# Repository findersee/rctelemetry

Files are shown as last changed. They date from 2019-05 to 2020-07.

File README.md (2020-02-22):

# rctelemetry
<p>FrSky Smart port compatible Telemetry board.</p>
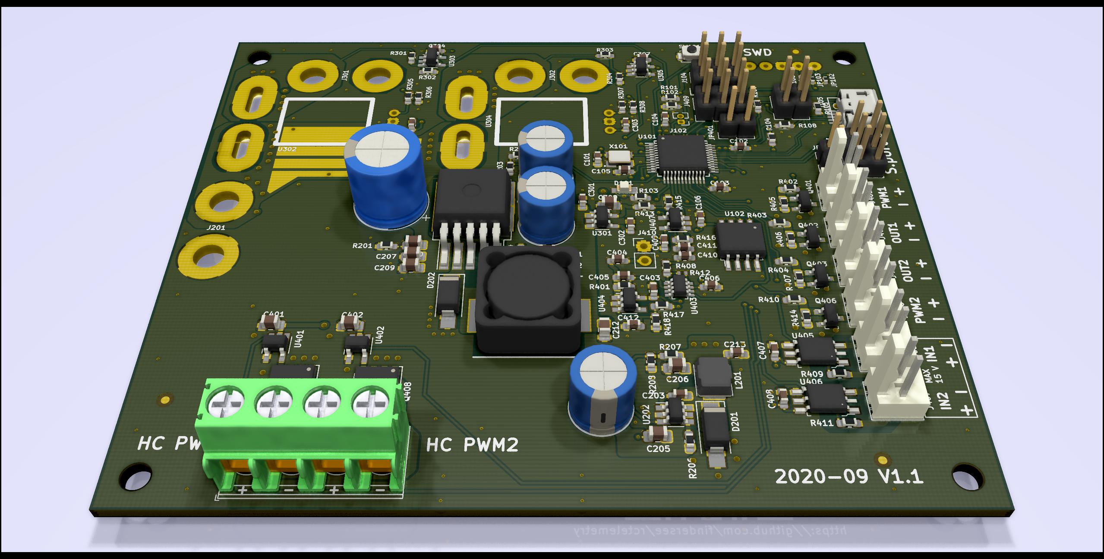
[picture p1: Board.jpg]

Telemetry features:<ul>
<li>Two DC power measurement channels, current and Voltage for speed controllers.</li>
<li>Battery input voltage measurement</li>
</ul>
Sbus integration:<ul>
  <li>2 servo channels</li>
  <li>2 PWM capable output channels 10A each</li>
  <li>2 PWM capable output channels 4A each</li>
  <li>2 Digital output channels 4A each</li>
  <li>2 Opto-isolated inputs</li>
  <li> Expansion UART </li>
</ul>

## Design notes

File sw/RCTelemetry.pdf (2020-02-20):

## RCTelemetry Project Configuration Report

# 1. Description

## 1.1. Project

Project Name | RCTelemetry
Board Name | custom
Generated with: | STM32CubeMX 5.4.0
Date | 02/18/2020

## 1.2. MCU

MCU Series | STM32F3
MCU Line | STM32F303
MCU name | STM32F303CCTx
MCU Package | LQFP48
MCU Pin number | 48

# 2. Pinout Configuration

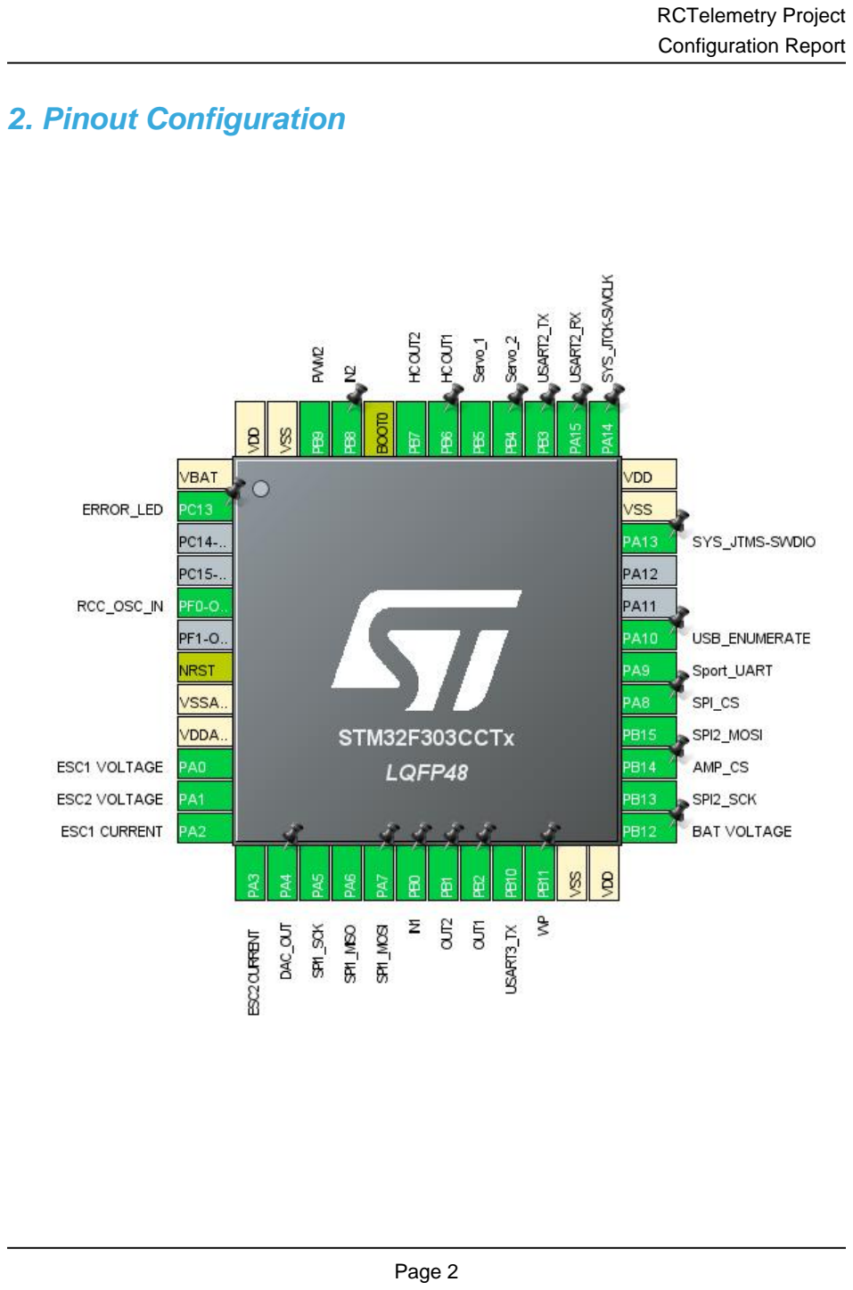
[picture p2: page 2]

# 3. Pins Configuration

Pin Number LQFP48 | Pin Name (function after reset) | Pin Type | Alternate Function(s) | Label
1 | VBAT | Power
2 | PC13 * | I/O | GPIO_Output | ERROR_LED
5 | PF0-OSC_IN | I/O | RCC_OSC_IN
7 | NRST | Reset
8 | VSSA/VREF- | Power
9 | VDDA/VREF+ | Power
10 | PA0 | I/O | ADC1_IN1 | ESC1 VOLTAGE
11 | PA1 | I/O | ADC1_IN2 | ESC2 VOLTAGE
12 | PA2 | I/O | ADC1_IN3 | ESC1 CURRENT
13 | PA3 | I/O | ADC1_IN4 | ESC2 CURRENT
14 | PA4 | I/O | DAC_OUT1 | DAC_OUT
15 | PA5 | I/O | SPI1_SCK
16 | PA6 | I/O | SPI1_MISO
17 | PA7 | I/O | SPI1_MOSI
18 | PB0 * | I/O | GPIO_Input | IN1
19 | PB1 * | I/O | GPIO_Output | OUT2
20 | PB2 * | I/O | GPIO_Output | OUT1
21 | PB10 | I/O | USART3_TX
22 | PB11 * | I/O | GPIO_Output | WP
23 | VSS | Power
24 | VDD | Power
25 | PB12 | I/O | ADC4_IN3 | BAT VOLTAGE
26 | PB13 | I/O | SPI2_SCK
27 | PB14 * | I/O | GPIO_Output | AMP_CS
28 | PB15 | I/O | SPI2_MOSI
29 | PA8 * | I/O | GPIO_Output | SPI_CS
30 | PA9 | I/O | USART1_TX | Sport_UART
31 | PA10 * | I/O | GPIO_Output | USB_ENUMERATE
34 | PA13 | I/O | SYS_JTMS-SWDIO
35 | VSS | Power
36 | VDD | Power
37 | PA14 | I/O | SYS_JTCK-SWCLK
38 | PA15 | I/O | USART2_RX
39 | PB3 | I/O | USART2_TX
40 | PB4 | I/O | TIM16_CH1 | Servo_2
41 | PB5 | I/O | TIM17_CH1 | Servo_1

Pin Number LQFP48 | Pin Name (function after reset) | Pin Type | Alternate Function(s) | Label
42 | PB6 | I/O | TIM4_CH1 | HC OUT1
43 | PB7 | I/O | TIM4_CH2 | HC OUT2
44 | BOOT0 | Boot
45 | PB8 * | I/O | GPIO_Input | IN2
46 | PB9 | I/O | TIM4_CH4 | PWM2
47 | VSS | Power
48 | VDD | Power

## * The pin is affected with an I/O function

# 4. Clock Tree Configuration

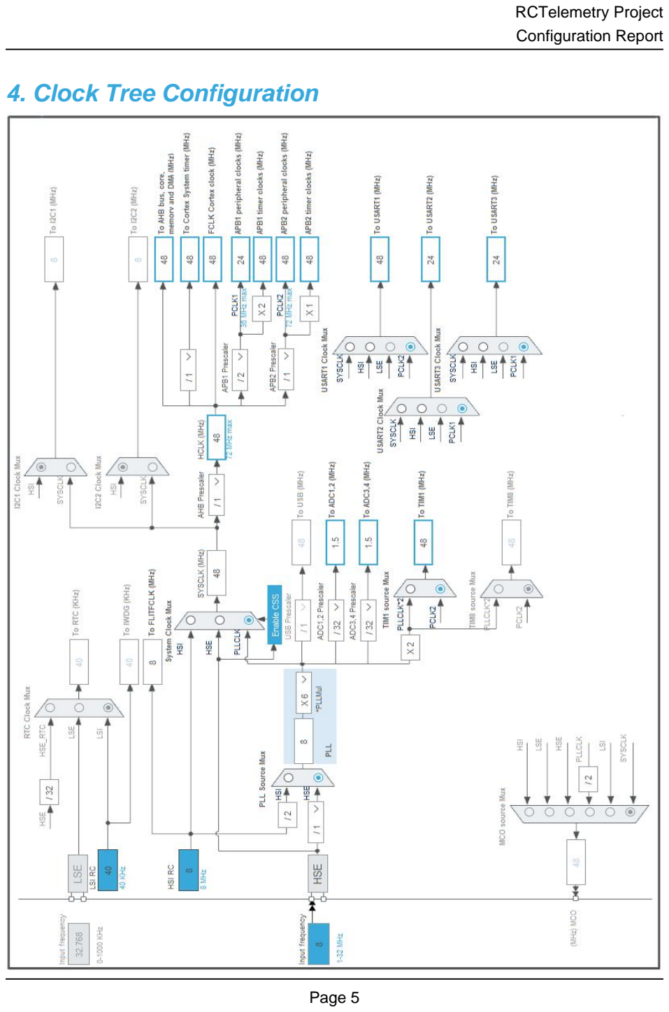
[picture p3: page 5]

# 5. Software Project

## 5.1. Project Settings

Name | Value
Project Name | RCTelemetry
Project Folder | C:\Users\akiku\GIT\rctelemetry\sw
Toolchain / IDE | STM32CubeIDE
Firmware Package Name and Version | STM32Cube FW_F3 V1.11.0

## 5.2. Code Generation Settings

Name | Value
STM32Cube MCU packages and embedded software | Copy only the necessary library files
Generate peripheral initialization as a pair of '.c/.h' files | No
Backup previously generated files when re-generating | No
Delete previously generated files when not re-generated | Yes
Set all free pins as analog (to optimize the power consumption) | No

# 6. Power Consumption Calculator report

### 6.1. Microcontroller Selection

Series | STM32F3
Line | STM32F303
MCU | STM32F303CCTx
Datasheet | 023353_Rev13

### 6.2. Parameter Selection

Temperature | 25
Vdd | 3.6

# 7. IPs and Middleware Configuration

# 7.1. ADC1

## IN1: IN1 Single-ended IN2: IN2 Single-ended IN3: IN3 Single-ended mode: IN4 mode: Vrefint Channel 7.1.1. Parameter Settings:

### ADCs_Common_Settings:

Mode | Independent mode

### ADC_Settings:

Clock Prescaler | ADC Asynchronous clock mode
Resolution | ADC 12-bit resolution
Data Alignment | Right alignment
Scan Conversion Mode | Enabled
Continuous Conversion Mode | Enabled *
Discontinuous Conversion Mode | Disabled
DMA Continuous Requests | Disabled
End Of Conversion Selection | End of single conversion
Overrun behaviour | Overrun data overwritten
Low Power Auto Wait | Disabled

### ADC_Regular_ConversionMode:

Enable Regular Conversions | Enable
Number Of Conversion | 5 *
External Trigger Conversion Source | Regular Conversion launched by software
External Trigger Conversion Edge | None
Rank | 1
Channel | Channel 1
Sampling Time | 7.5 Cycles *
Offset Number | No offset
Offset | 0
Rank | 2 *
Channel | Channel 2 *
Sampling Time | 7.5 Cycles *
Offset Number | No offset
Offset | 0
Rank | 3 *

Channel | Channel 3 *
Sampling Time | 7.5 Cycles *
Offset Number | No offset
Offset | 0
Rank | 4 *
Channel | Channel 4 *
Sampling Time | 7.5 Cycles *
Offset Number | No offset
Offset | 0
Rank | 5 *
Channel | Channel Vrefint *
Sampling Time | 1.5 Cycles
Offset Number | No offset
Offset | 0

### ADC_Injected_ConversionMode:

Enable Injected Conversions | Enable
Number Of Conversions | 0

### Analog Watchdog 1:

Enable Analog WatchDog1 Mode | false

### Analog Watchdog 2:

Enable Analog WatchDog2 Mode | false

### Analog Watchdog 3:

Enable Analog WatchDog3 Mode | false

# 7.2. ADC4

## IN3: IN3 Single-ended 7.2.1. Parameter Settings:

### ADCs_Common_Settings:

Mode | Independent mode

### ADC_Settings:

Clock Prescaler | ADC Asynchronous clock mode
Resolution | ADC 12-bit resolution
Data Alignment | Right alignment
Scan Conversion Mode | Disabled
Continuous Conversion Mode | Enabled *
Discontinuous Conversion Mode | Disabled
DMA Continuous Requests | Disabled

End Of Conversion Selection | End of single conversion
Overrun behaviour | Overrun data overwritten
Low Power Auto Wait | Disabled

### ADC_Regular_ConversionMode:

Enable Regular Conversions | Enable
Number Of Conversion | 1
External Trigger Conversion Source | Regular Conversion launched by software
External Trigger Conversion Edge | None
Rank | 1
Channel | Channel 3
Sampling Time | 1.5 Cycles
Offset Number | No offset
Offset | 0

### ADC_Injected_ConversionMode:

Enable Injected Conversions | Enable
Number Of Conversions | 0

### Analog Watchdog 1:

Enable Analog WatchDog1 Mode | false

### Analog Watchdog 2:

Enable Analog WatchDog2 Mode | false

### Analog Watchdog 3:

Enable Analog WatchDog3 Mode | false

# 7.3. CRC

## mode: Activated 7.3.1. Parameter Settings:

### Basic Parameters:

Default Polynomial State | Enable
Default Init Value State | Enable

### Advanced Parameters:

Input Data Inversion Mode | None
Output Data Inversion Mode | Disable
Input Data Format | Bytes

# 7.4. DAC

## mode: OUT1 Configuration 7.4.1. Parameter Settings:

### DAC Out1 Settings:

Output Buffer | Enable
Trigger | Timer 6 Trigger Out event *
Wave generation mode | Disabled

# 7.5. GPIO

# 7.6. RCC

## High Speed Clock (HSE): BYPASS Clock Source 7.6.1. Parameter Settings:

### System Parameters:

VDD voltage (V) | 3.3
Prefetch Buffer | Enabled
Flash Latency(WS) | 1 WS (2 CPU cycle)

### RCC Parameters:

HSI Calibration Value | 16
HSE Startup Timout Value (ms) | 100
LSE Startup Timout Value (ms) | 5000

# 7.7. SPI1

## Mode: Full-Duplex Master 7.7.1. Parameter Settings:

### Basic Parameters:

Frame Format | Motorola
Data Size | 8 Bits *
First Bit | MSB First

### Clock Parameters:

Prescaler (for Baud Rate) | 4 *
Baud Rate | 12.0 MBits/s *
Clock Polarity (CPOL) | Low

Clock Phase (CPHA) | 1 Edge

### Advanced Parameters:

CRC Calculation | Disabled
NSSP Mode | Enabled
NSS Signal Type | Software

# 7.8. SPI2

## Mode: Transmit Only Master 7.8.1. Parameter Settings:

### Basic Parameters:

Frame Format | Motorola
Data Size | 8 Bits *
First Bit | MSB First

### Clock Parameters:

Prescaler (for Baud Rate) | 2
Baud Rate | 12.0 MBits/s *
Clock Polarity (CPOL) | Low
Clock Phase (CPHA) | 1 Edge

### Advanced Parameters:

CRC Calculation | Disabled
NSSP Mode | Enabled
NSS Signal Type | Software

# 7.9. SYS

## Debug: Serial Wire Timebase Source: TIM7

# 7.10. TIM1

## Clock Source : Internal Clock 7.10.1. Parameter Settings:

### Counter Settings:

Prescaler (PSC - 16 bits value) | 0
Counter Mode | Up
Counter Period (AutoReload Register - 16 bits value ) | 0

Internal Clock Division (CKD) | No Division
Repetition Counter (RCR - 16 bits value) | 0
auto-reload preload | Disable

### Trigger Output (TRGO) Parameters:

Master/Slave Mode (MSM bit) | Disable (Trigger input effect not delayed)
Trigger Event Selection TRGO | Reset (UG bit from TIMx_EGR)
Trigger Event Selection TRGO2 | Reset (UG bit from TIMx_EGR)

# 7.11. TIM2

## Clock Source : Internal Clock 7.11.1. Parameter Settings:

### Counter Settings:

Prescaler (PSC - 16 bits value) | 24000 *
Counter Mode | Up
Counter Period (AutoReload Register - 32 bits value ) | 2000 *
Internal Clock Division (CKD) | No Division
auto-reload preload | Disable

### Trigger Output (TRGO) Parameters:

Master/Slave Mode (MSM bit) | Disable (Trigger input effect not delayed)
Trigger Event Selection TRGO | Update Event *

# 7.12. TIM3

## Clock Source : Internal Clock 7.12.1. Parameter Settings:

### Counter Settings:

Prescaler (PSC - 16 bits value) | 0
Counter Mode | Up
Counter Period (AutoReload Register - 16 bits value ) | 0
Internal Clock Division (CKD) | No Division
auto-reload preload | Disable

### Trigger Output (TRGO) Parameters:

Master/Slave Mode (MSM bit) | Disable (Trigger input effect not delayed)
Trigger Event Selection TRGO | Reset (UG bit from TIMx_EGR)

# 7.13. TIM4

## Clock Source : Internal Clock Channel1: PWM Generation CH1 Channel2: PWM Generation CH2 Channel4: PWM Generation CH4 7.13.1. Parameter Settings:

### Counter Settings:

Prescaler (PSC - 16 bits value) | 3-1 *
Counter Mode | Up
Counter Period (AutoReload Register - 16 bits value ) | 1600-1 *
Internal Clock Division (CKD) | No Division
auto-reload preload | Disable

### Trigger Output (TRGO) Parameters:

Master/Slave Mode (MSM bit) | Disable (Trigger input effect not delayed)
Trigger Event Selection TRGO | Reset (UG bit from TIMx_EGR)

### Clear Input:

Clear Input Source | Disable

### PWM Generation Channel 1:

Mode | PWM mode 1
Pulse (16 bits value) | 0
Output compare preload | Enable
Fast Mode | Disable
CH Polarity | High

### PWM Generation Channel 2:

Mode | PWM mode 1
Pulse (16 bits value) | 0
Output compare preload | Enable
Fast Mode | Disable
CH Polarity | High

### PWM Generation Channel 4:

Mode | PWM mode 1
Pulse (16 bits value) | 0
Output compare preload | Enable
Fast Mode | Disable
CH Polarity | High

# 7.14. TIM6

## mode: Activated 7.14.1. Parameter Settings:

### Counter Settings:

Prescaler (PSC - 16 bits value) | 1 *
Counter Mode | Up
Counter Period (AutoReload Register - 16 bits value ) | 64535 *
auto-reload preload | Enable *

### Trigger Output (TRGO) Parameters:

Trigger Event Selection | Reset (UG bit from TIMx_EGR)

# 7.15. TIM15

## mode: Clock Source 7.15.1. Parameter Settings:

### Counter Settings:

Prescaler (PSC - 16 bits value) | 0
Counter Mode | Up
Counter Period (AutoReload Register - 16 bits value ) | 0
Internal Clock Division (CKD) | No Division
Repetition Counter (RCR - 8 bits value) | 0
auto-reload preload | Disable

### Trigger Output (TRGO) Parameters:

Master/Slave Mode (MSM bit) | Disable (Trigger input effect not delayed)
Trigger Event Selection | Reset (UG bit from TIMx_EGR)

# 7.16. TIM16

## mode: Activated Channel1: Output Compare CH1 7.16.1. Parameter Settings:

### Counter Settings:

Prescaler (PSC - 16 bits value) | 0
Counter Mode | Up
Counter Period (AutoReload Register - 16 bits value ) | 0
Internal Clock Division (CKD) | No Division
Repetition Counter (RCR - 8 bits value) | 0
auto-reload preload | Disable

### Break And Dead Time management - BRK Configuration:

BRK State | Disable
BRK Polarity | High
BRK Filter (4 bits value) | 0

### Break And Dead Time management - Output Configuration:

Automatic Output State | Disable
Off State Selection for Run Mode (OSSR) | Disable
Off State Selection for Idle Mode (OSSI) | Disable
Lock Configuration | Off

### Output Compare Channel 1:

Mode | Frozen (used for Timing base)
Pulse (16 bits value) | 0
Output compare preload | Disable
CH Polarity | High
CH Idle State | Reset

# 7.17. TIM17

## mode: Activated Channel1: Output Compare CH1 7.17.1. Parameter Settings:

### Counter Settings:

Prescaler (PSC - 16 bits value) | 0
Counter Mode | Up
Counter Period (AutoReload Register - 16 bits value ) | 0
Internal Clock Division (CKD) | No Division
Repetition Counter (RCR - 8 bits value) | 0
auto-reload preload | Disable

### Break And Dead Time management - BRK Configuration:

BRK State | Disable
BRK Polarity | High
BRK Filter (4 bits value) | 0

### Break And Dead Time management - Output Configuration:

Automatic Output State | Disable
Off State Selection for Run Mode (OSSR) | Disable
Off State Selection for Idle Mode (OSSI) | Disable
Lock Configuration | Off

### Output Compare Channel 1:

Mode | Frozen (used for Timing base)
Pulse (16 bits value) | 0
Output compare preload | Disable
CH Polarity | High
CH Idle State | Reset

# 7.18. USART1

## Mode: Single Wire (Half-Duplex) 7.18.1. Parameter Settings:

### Basic Parameters:

Baud Rate | 57600 *
Word Length | 8 Bits (including Parity)
Parity | None
Stop Bits | 1

### Advanced Parameters:

Data Direction | Receive and Transmit
Over Sampling | 16 Samples
Single Sample | Disable

### Advanced Features:

Auto Baudrate | Disable
TX Pin Active Level Inversion | Enable *
RX Pin Active Level Inversion | Enable *
Data Inversion | Disable
TX and RX Pins Swapping | Disable
Overrun | Enable
DMA on RX Error | Enable
MSB First | Disable

# 7.19. USART2

## Mode: Asynchronous

## 7.19.1. Parameter Settings:

### Basic Parameters:

Baud Rate | 115200 *
Word Length | 8 Bits (including Parity)
Parity | None
Stop Bits | 1

### Advanced Parameters:

Data Direction | Receive and Transmit
Over Sampling | 16 Samples
Single Sample | Disable

### Advanced Features:

Auto Baudrate | Disable
TX Pin Active Level Inversion | Disable
RX Pin Active Level Inversion | Disable
Data Inversion | Disable
TX and RX Pins Swapping | Disable
Overrun | Enable
DMA on RX Error | Enable
MSB First | Disable

# 7.20. USART3

## Mode: Single Wire (Half-Duplex) 7.20.1. Parameter Settings:

### Basic Parameters:

Baud Rate | 100000 *
Word Length | 9 Bits (including Parity) *
Parity | Even *
Stop Bits | 2 *

### Advanced Parameters:

Data Direction | Receive Only *
Over Sampling | 16 Samples
Single Sample | Disable

### Advanced Features:

Auto Baudrate | Disable
TX Pin Active Level Inversion | Enable *

RX Pin Active Level Inversion

| Enable *
Data Inversion | Disable
TX and RX Pins Swapping | Disable
Overrun | Enable
DMA on RX Error | Enable
MSB First | Disable

# 7.21. FREERTOS

## Interface: CMSIS_V1 7.21.1. Config parameters:

### API:

FreeRTOS API | CMSIS v1

### Versions:

FreeRTOS version | 10.0.1
CMSIS-RTOS version | 1.02

### Kernel settings:

USE_PREEMPTION | Enabled
CPU_CLOCK_HZ | SystemCoreClock
TICK_RATE_HZ | 1000
MAX_PRIORITIES | 7
MINIMAL_STACK_SIZE | 128
MAX_TASK_NAME_LEN | 16
USE_16_BIT_TICKS | Disabled
IDLE_SHOULD_YIELD | Enabled
USE_MUTEXES | Enabled
USE_RECURSIVE_MUTEXES | Disabled
USE_COUNTING_SEMAPHORES | Disabled
QUEUE_REGISTRY_SIZE | 8
USE_APPLICATION_TASK_TAG | Disabled
ENABLE_BACKWARD_COMPATIBILITY | Enabled
USE_PORT_OPTIMISED_TASK_SELECTION | Enabled
USE_TICKLESS_IDLE | Disabled
USE_TASK_NOTIFICATIONS | Enabled
RECORD_STACK_HIGH_ADDRESS | Disabled

### Memory management settings:

Memory Allocation | Dynamic *
TOTAL_HEAP_SIZE | 5500 *
Memory Management scheme | heap_4

### Hook function related definitions:

USE_IDLE_HOOK | Disabled
USE_TICK_HOOK | Disabled
USE_MALLOC_FAILED_HOOK | Disabled
USE_DAEMON_TASK_STARTUP_HOOK | Disabled
CHECK_FOR_STACK_OVERFLOW | Disabled

### Run time and task stats gathering related definitions:

GENERATE_RUN_TIME_STATS | Disabled
USE_TRACE_FACILITY | Disabled
USE_STATS_FORMATTING_FUNCTIONS | Disabled

### Co-routine related definitions:

USE_CO_ROUTINES | Disabled
MAX_CO_ROUTINE_PRIORITIES | 2

### Software timer definitions:

USE_TIMERS | Disabled

### Interrupt nesting behaviour configuration:

LIBRARY_LOWEST_INTERRUPT_PRIORITY | 15
LIBRARY_MAX_SYSCALL_INTERRUPT_PRIORITY | 5

## 7.21.2. Include parameters:

### Include definitions:

vTaskPrioritySet | Enabled
uxTaskPriorityGet | Enabled
vTaskDelete | Enabled
vTaskCleanUpResources | Disabled
vTaskSuspend | Enabled
vTaskDelayUntil | Disabled
vTaskDelay | Enabled
xTaskGetSchedulerState | Enabled
xTaskResumeFromISR | Enabled
xQueueGetMutexHolder | Disabled
xSemaphoreGetMutexHolder | Disabled
pcTaskGetTaskName | Disabled
uxTaskGetStackHighWaterMark | Disabled
xTaskGetCurrentTaskHandle | Disabled
eTaskGetState | Disabled
xEventGroupSetBitFromISR | Disabled
xTimerPendFunctionCall | Disabled
xTaskAbortDelay | Disabled
xTaskGetHandle | Disabled

### * User modified value

# 8. System Configuration

# 8.1. GPIO configuration

IP | Pin | Signal | GPIO mode | GPIO pull/up pull down

## Max Speed

## User Label

ADC1 | PA0 | ADC1_IN1 | Analog mode | No pull up pull down | n/a | ESC1 VOLTAGE
| PA1 | ADC1_IN2 | Analog mode | No pull up pull down | n/a | ESC2 VOLTAGE
| PA2 | ADC1_IN3 | Analog mode | No pull up pull down | n/a | ESC1 CURRENT
| PA3 | ADC1_IN4 | Analog mode | No pull up pull down | n/a | ESC2 CURRENT
ADC4 | PB12 | ADC4_IN3 | Analog mode | No pull up pull down | n/a | BAT VOLTAGE
DAC | PA4 | DAC_OUT1 | Analog mode | No pull up pull down | n/a | DAC_OUT
RCC | PF0-OSC_IN RCC_OSC_IN | n/a | n/a | n/a
SPI1 | PA5 | SPI1_SCK | Alternate Function Push Pull | No pull up pull down | High *
| PA6 | SPI1_MISO | Alternate Function Push Pull | No pull up pull down | High *
| PA7 | SPI1_MOSI | Alternate Function Push Pull | No pull up pull down | High *
SPI2 | PB13 | SPI2_SCK | Alternate Function Push Pull | No pull up pull down | High *
| PB15 | SPI2_MOSI | Alternate Function Push Pull | No pull up pull down | High *
SYS | PA13 | SYS_JTMS- SWDIO | n/a | n/a | n/a
| PA14 | SYS_JTCK- SWCLK | n/a | n/a | n/a
TIM4 | PB6 | TIM4_CH1 | Alternate Function Push Pull | No pull up pull down | Low | HC OUT1
| PB7 | TIM4_CH2 | Alternate Function Push Pull | No pull up pull down | Low | HC OUT2
| PB9 | TIM4_CH4 | Alternate Function Push Pull | No pull up pull down | Low | PWM2
TIM16 | PB4 | TIM16_CH1 | Alternate Function Push Pull | No pull up pull down | Low | Servo_2
TIM17 | PB5 | TIM17_CH1 | Alternate Function Push Pull | No pull up pull down | Low | Servo_1
USART1 | PA9 | USART1_TX | Alternate Function

### Push Pull *

| | | | No pull up pull down | High * | Sport_UART
USART2 | PA15 | USART2_RX | Alternate Function Push Pull | No pull up pull down | High *
| PB3 | USART2_TX | Alternate Function Push Pull | No pull up pull down | High *
USART3 | PB10 | USART3_TX | Alternate Function Open Drain | No pull up pull down | High *
GPIO | PC13 | GPIO_Output | Output Open Drain * | No pull up pull down | Low | ERROR_LED
| PB0 | GPIO_Input | Input mode | Pull up * | n/a | IN1
| PB1 | GPIO_Output | Output Push Pull | No pull up pull down | Low | OUT2
| PB2 | GPIO_Output | Output Push Pull | No pull up pull down | Low | OUT1
| PB11 | GPIO_Output | Output Push Pull | No pull up pull down | Low | WP
| PB14 | GPIO_Output | Output Push Pull | No pull up pull down | Low | AMP_CS
| PA8 | GPIO_Output | Output Push Pull | No pull up pull down | Low | SPI_CS

IP | Pin | Signal | GPIO mode | GPIO pull/up pull down | Max Speed | User Label
| PA10 | GPIO_Output | Output Push Pull | No pull up pull down | Low | USB_ENUMERATE
| PB8 | GPIO_Input | Input mode | Pull up * | n/a | IN2

# 8.2. DMA configuration

DMA request | Stream | Direction | Priority
USART1_RX | DMA1_Channel5 | Peripheral To Memory | High *
DAC_CH1 | DMA2_Channel3 | Memory To Peripheral | High *
ADC1 | DMA1_Channel1 | Peripheral To Memory | Low
USART1_TX | DMA1_Channel4 | Memory To Peripheral | Very High *
ADC4 | DMA2_Channel2 | Peripheral To Memory | Low
USART3_RX | DMA1_Channel3 | Peripheral To Memory | Medium *
USART2_RX | DMA1_Channel6 | Peripheral To Memory | Low

## USART1_RX: DMA1_Channel5 DMA request Settings:

Mode: | Circular *
Peripheral Increment: | Disable
Memory Increment: | Enable *
Peripheral Data Width: | Byte
Memory Data Width: | Byte

## DAC_CH1: DMA2_Channel3 DMA request Settings:

Mode: | Circular *
Peripheral Increment: | Disable
Memory Increment: | Enable *
Peripheral Data Width: | Half Word
Memory Data Width: | Half Word

## ADC1: DMA1_Channel1 DMA request Settings:

Mode: | Circular *
Peripheral Increment: | Disable
Memory Increment: | Enable *
Peripheral Data Width: | Half Word
Memory Data Width: | Half Word

## USART1_TX: DMA1_Channel4 DMA request Settings:

Mode: | Normal
Peripheral Increment: | Disable
Memory Increment: | Enable *
Peripheral Data Width: | Byte
Memory Data Width: | Byte

## ADC4: DMA2_Channel2 DMA request Settings:

Mode: | Circular *
Peripheral Increment: | Disable
Memory Increment: | Enable *
Peripheral Data Width: | Half Word
Memory Data Width: | Half Word

## USART3_RX: DMA1_Channel3 DMA request Settings:

Mode: | Circular *
Peripheral Increment: | Disable
Memory Increment: | Enable *
Peripheral Data Width: | Byte
Memory Data Width: | Byte

## USART2_RX: DMA1_Channel6 DMA request Settings:

Mode: | Normal
Peripheral Increment: | Disable
Memory Increment: | Enable *
Peripheral Data Width: | Byte
Memory Data Width: | Byte

# 8.3. NVIC configuration

Interrupt Table | Enable | Preenmption Priority | SubPriority
Non maskable interrupt | true | 0 | 0
Hard fault interrupt | true | 0 | 0
Memory management fault | true | 0 | 0
Pre-fetch fault, memory access fault | true | 0 | 0
Undefined instruction or illegal state | true | 0 | 0
System service call via SWI instruction | true | 0 | 0
Debug monitor | true | 0 | 0
Pendable request for system service | true | 15 | 0
System tick timer | true | 15 | 0
DMA1 channel1 global interrupt | true | 5 | 0
DMA1 channel3 global interrupt | true | 5 | 0
DMA1 channel4 global interrupt | true | 5 | 0
DMA1 channel5 global interrupt | true | 5 | 0
DMA1 channel6 global interrupt | true | 5 | 0
TIM1 trigger, commutation and TIM17 interrupts | true | 5 | 0
USART1 global interrupt / USART1 wake-up interrupt through EXTI line 25 | true | 5 | 0
USART3 global interrupt / USART3 wake-up interrupt through EXTI line 28 | true | 5 | 0
TIM7 global interrupt | true | 0 | 0
DMA2 channel2 global interrupt | true | 5 | 0
DMA2 channel3 global interrupt | true | 5 | 0
PVD interrupt through EXTI line16 | unused
Flash global interrupt | unused
RCC global interrupt | unused
ADC1 and ADC2 interrupts | unused
TIM1 break and TIM15 interrupts | unused
TIM1 update and TIM16 interrupts | unused
TIM1 capture compare interrupt | unused
TIM2 global interrupt | unused
TIM3 global interrupt | unused
TIM4 global interrupt | unused
SPI1 global interrupt | unused
SPI2 global interrupt | unused
USART2 global interrupt / USART2 wake-up interrupt through EXTI line 26 | unused
Timer 6 interrupt and DAC underrun interrupts | unused
ADC4 interrupt | unused
Floating point unit interrupt | unused

### * User modified value

# 9. Software Pack Report

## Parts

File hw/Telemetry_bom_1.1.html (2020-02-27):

Source File | C:\Users\akiku\GIT\rctelemetry\hw\Telemetry.sch
BoM Date | 27.2.2020 21.57.53
Schematic Version | 1.1
Schematic Date | 2020-02-24
PCB Variant | [u'default']
KiCad Version | Eeschema (5.1.5)-3
Component Groups | 54
Component Count (per PCB) | 130
Fitted Components (per PCB) | 127
Number of PCBs | 1
Total Component Count (for 1 PCBs) | 127
 | Description | References | Value | Footprint | Quantity Per PCB | Manufacturer | MPN | Datasheet
1 | Unpolarized capacitor, small symbol | C101 C102 C103 C104 C105 C106 C303 C304 C306 C307 C403 C405 C406 C407 C408 C409 C411 C412 | 100n/50V | C_0603_1608Metric_Pad1.05x0.95mm_HandSolder | 18 |  |  | ~
2 | Unpolarized capacitor | C207 C211 C212 | 100n/50V | C_0805_2012Metric_Pad1.15x1.40mm_HandSolder | 3 |  |  | ~
3 | Polarized capacitor | C202 C208 | 100uF/10V | C_Radial_D7.5_L11.2_P2.5 | 2 |  |  | ~
4 | Unpolarized capacitor, small symbol | C203 C213 C302 | 10n/50V | C_0603_1608Metric_Pad1.05x0.95mm_HandSolder | 3 |  |  | ~
5 | Unpolarized capacitor | C209 C210 | 10n/50V | C_0805_2012Metric_Pad1.15x1.40mm_HandSolder | 2 |  |  | ~
6 | Unpolarized capacitor | C206 | 10u/10V | C_0805_2012Metric_Pad1.15x1.40mm_HandSolder | 1 |  |  | ~
7 | Unpolarized capacitor, small symbol | C404 C410 | 10u/10V | C_0603_1608Metric_Pad1.05x0.95mm_HandSolder | 2 |  |  | ~
8 | Unpolarized capacitor | C205 C401 C402 | 1u/35V | C_0805_2012Metric_Pad1.15x1.40mm_HandSolder | 3 |  |  | ~
9 | Unpolarized capacitor, small symbol | C301 | 1u/35V | C_0603_1608Metric_Pad1.05x0.95mm_HandSolder | 1 |  |  | ~
10 | Polarized capacitor | C204 | 22u/35V | C_Radial_D7.5_L11.2_P2.5 | 1 |  |  | ~
11 | Unpolarized capacitor, small symbol | C309 | 2u2/10V | C_0805_2012Metric_Pad1.15x1.40mm_HandSolder | 1 |  |  | ~
12 | Polarized capacitor | C201 | 470uF/35V | CP_Radial_D10.0mm_P5.00mm | 1 |  |  | ~
13 | Light emitting diode | D101 | LED_Green | LED_0603_HandSoldering | 1 |  |  | ~
14 | Schottky diode | D201 D202 | SS54 | D_SMA_Handsoldering | 2 |  | SS54 | https://www.farnell.com/datasheets/1441695.pdf
15 | Generic connector, single row, 01x02, script generated (kicad-library-utils/schlib/autogen/connector/) | J410 | AUDIO | PinHeader_1x02_P2.54mm_Vertical | 1 |  |  | ~
16 | Generic connector, single row, 01x02, script generated (kicad-library-utils/schlib/autogen/connector/) | J102 | BOOT0 | Pin_Header_Straight_1x02_Pitch1.27mm | 1 |  |  | ~
17 | Generic connector, single row, 01x02, script generated (kicad-library-utils/schlib/autogen/connector/) | J201 J301 J302 | Conn_01x02 | 2Pin_4mm | 3 |  |  | ~
18 | Generic connector, single row, 01x02, script generated (kicad-library-utils/schlib/autogen/connector/) | J401 J402 J403 J405 J406 J407 | Conn_01x02 | Molex_KK-254_AE-6410-02A_1x02_P2.54mm_Vertical | 6 |  |  | ~
19 | Generic screw terminal, single row, 01x04, script generated (kicad-library-utils/schlib/autogen/connector/) | J404 | HC_OUT | TerminalBlock_Phoenix_PT-1,5-4-5.0-H_1x04_P5.00mm_Horizontal | 1 |  |  | ~
20 | Generic connector, single row, 01x06, script generated (kicad-library-utils/schlib/autogen/connector/) | J103 J104 | SPORT | Pin_Header_Straight_2x03 | 2 |  |  | ~
21 | Generic connector, double row, 02x03, odd/even pin numbering scheme (row 1 odd numbers, row 2 even numbers), script generated (kicad-library-utils/schlib/autogen/connector/) | J409 | ServoCon | PinHeader_2x03_P2.54mm_Vertical | 1 |  |  | ~
22 | Generic connector, single row, 01x04, script generated (kicad-library-utils/schlib/autogen/connector/) | J106 | UART_EXP | PinHeader_2x02_P2.54mm_Vertical | 1 |  |  | ~
23 | USB Micro Type B connector | J105 | USB_B_Micro | USB_Micro-B | 1 |  |  | ~
24 | Jumper, normally closed, small symbol | JP101 JP401 | Jumper_NC_Small | PinHeader_1x02_P2.54mm_Vertical | 2 |  |  | ~
25 | Inductor | L202 | BCRH1212Y-680M | L_Sunlord_MWSA1206 | 1 | Sunlord | MWSA1206-470MT | https://datasheet.lcsc.com/szlcsc/Sunlord-MWSA1206-470MT_C115409.pdf
26 | Inductor | L201 | SPN30304R7MPTE | L_Sunlord_MWSA0402 | 1 | Sunlord | MWSA0402-4R7MT | https://datasheet.lcsc.com/szlcsc/Sunlord-MWSA0402-4R7MT_C136097.pdf
27 | 100A Id, 30V Vds, NexFET N-Channel Power MOSFET, 4.2mOhm Ron, Qg (typ) 11.8nC, SON8 5x6mm | Q404 Q408 | CSD17306Q5A | TDSON-8-1_HandSoldering | 2 | Texas Instruments | CSD17306Q5A | http://www.ti.com/lit/gpn/csd17306q5a
28 | MOSFET N-CH 30V 5A SOT23 | Q401 Q402 Q403 Q406 | IRLML6344TRPBF | SOT-23-3 | 4 | Infineon Technologies | IRLML6344TRPBF | https://www.infineon.com/dgdl/irlml6344pbf.pdf?fileId=5546d462533600a4015356689c44262c
29 | Resistor | R101 R201 R206 R413 R415 R417 R418 | 10k | R_0603_1608Metric_Pad1.05x0.95mm_HandSolder | 7 |  |  | ~
30 | Resistor, small symbol | R205 R302 R304 R305 R307 | 12k | R_0603_1608Metric_Pad1.05x0.95mm_HandSolder | 5 |  |  | ~
31 | Resistor, small symbol | R401 R416 | 15k | R_0603_1608Metric_Pad1.05x0.95mm_HandSolder | 2 |  |  | ~
32 | Resistor, small symbol | R306 R308 | 18k | R_0603_1608Metric_Pad1.05x0.95mm_HandSolder | 2 |  |  | ~
33 | Resistor, small symbol | R105 R402 R403 R404 R409 R410 R411 | 1k5 | R_0603_1608Metric_Pad1.05x0.95mm_HandSolder | 7 |  |  | ~
34 | Resistor, small symbol | R202 R208 | 24k | R_0603_1608Metric_Pad1.05x0.95mm_HandSolder | 2 |  |  | ~
35 | Resistor | R102 R103 | 470R | R_0603_1608Metric_Pad1.05x0.95mm_HandSolder | 2 |  |  | ~
36 | Resistor | R104 R106 R107 R108 | 50R | R_0603_1608Metric_Pad1.05x0.95mm_HandSolder | 4 |  |  | ~
37 | Resistor, small symbol | R203 R301 R303 | 68k | R_0603_1608Metric_Pad1.05x0.95mm_HandSolder | 3 |  |  | ~
38 | Resistor, small symbol | R204 R408 | 6k2 | R_0603_1608Metric_Pad1.05x0.95mm_HandSolder | 2 |  |  | ~
39 | Resistor, small symbol | R207 R405 R406 R407 R414 | 75k | R_0603_1608Metric_Pad1.05x0.95mm_HandSolder | 5 |  |  | ~
40 | Push button switch, generic, two pins | SW101 | SW_Push | SW_SPST_B3U-1000P | 1 | Omron | B3U-1000P | https://omronfs.omron.com/en_US/ecb/products/pdf/en-b3u.pdf
41 | 100A Unidirectional Hall-Effect Current Sensor, +5.0V supply, 40mV/A, CB-5 PSF | U302 U304 | ACS758LCB-100B-PFF-T | Allegro_PFF | 2 | Allegro | ACS758LCB-100B-PFF-T | http://www.allegromicro.com/~/media/Files/Datasheets/ACS758-Datasheet.ashx?la=en
42 |  | U403 | AD5160BRJZ10-R2 | SOT-23-8 | 1 | AD5160BRJZ10-R2 | Analog Devices | https://www.analog.com/media/en/technical-documentation/data-sheets/AD5160.pdf
43 |  | U201 | AP1501-K5 | TO-263-5_TabPin3 | 1 | Diodes Inc | AP1501-K5 | https://www.diodes.com/assets/Datasheets/AP1501.pdf
44 |  | U102 | IS25LP032D | SOIC-8_W5.6mm | 1 | ISSI | IS25LP032D | http://www.issi.com/WW/pdf/25LP-WP032D.pdf
45 | 150mA 16V Low-noise Low-dropout Regulator With Shutdown, 5.0V output voltage, SOT-23-5 | U301 | LP2985-5.0 | SOT-23-5_HandSoldering | 1 | Texas Instruments | LP2985-5.0 | http://www.ti.com/lit/ds/symlink/lp2985.pdf
46 |  | U401 U402 | MCP1416 | SOT-23-5_HandSoldering | 2 | Microchip | MCP1416 | http://ww1.microchip.com/downloads/en/DeviceDoc/20002092F.pdf
47 | 1MHz, Low-Power Op Amp, SOT-23-5 | U303 | MCP6001-OT | SOT-23-5_HandSoldering | 1 | Microchip | MCP6001-OT | http://ww1.microchip.com/downloads/en/DeviceDoc/21733j.pdf
48 | 1MHz, Low-Power Op Amp, SOT-23-5 | U305 U404 U407 | MCP6001-OT | SOT-23-5_HandSoldering | 3 | Microchip | MCP6001-OT | http://ww1.microchip.com/downloads/en/DeviceDoc/21733j.pdf
49 |  | U202 | RT6200 | SOT-23-6_Handsoldering | 1 | Richtek Tech | RT6200 | https://www.richtek.com/assets/product_file/RT6200/DS6200-04.pdf
50 |  | U101 | STM32F303CBx | LQFP-48_7x7mm_Pitch0.5mm | 1 | ST Microelectronics | STM32F303CB | https://www.st.com/resource/en/datasheet/stm32f303cb.pdf
51 | OPTOISO 3.75KV PSH PULL SO6-5 | U405 U406 | TLP2361_TPL_E | SOIC-6-5_W4.55mm | 2 | Toshiba Semiconductor and Storage | TLP2361-TPLECT | https://toshiba.semicon-storage.com/info/docget.jsp?did=14229&prodName=TLP2361
52 |  | X101 | SG-310_SCF_8.000000MHZ | SG- 310 | 1 | Epson | SG-310_SCF_8.000000MHZ | https://support.epson.biz/td/api/doc_check.php?dl=brief_SG-310SEF&lang=en

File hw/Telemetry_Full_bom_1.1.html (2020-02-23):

Source File | C:\Users\akiku\GIT\rctelemetry\hw\Telemetry.sch
BoM Date | 23.2.2020 20.33.02
Schematic Version | 1.1
Schematic Date | 2020-02-23
PCB Variant | [u'default']
KiCad Version | Eeschema (5.1.5)-3
Component Groups | 54
Component Count (per PCB) | 119
Fitted Components (per PCB) | 118
Number of PCBs | 1
Total Component Count (for 1 PCBs) | 118
 | Description | References | Value | Footprint | Quantity Per PCB | Manufacturer | MPN | Datasheet
1 | Unpolarized capacitor, small symbol | C101 C102 C103 C104 C105 C106 C303 C304 C306 C307 C403 C405 C406 C407 C408 | 100n/50V | C_0603_1608Metric_Pad1.05x0.95mm_HandSolder | 15 |  |  | ~
2 | Unpolarized capacitor | C207 C211 C212 | 100n/50V | C_0805_2012Metric_Pad1.15x1.40mm_HandSolder | 3 |  |  | ~
3 | Polarized capacitor | C202 C208 | 100uF/10V | C_Radial_D7.5_L11.2_P2.5 | 2 |  |  | ~
4 | Unpolarized capacitor, small symbol | C203 C213 C302 | 10n/50V | C_0603_1608Metric_Pad1.05x0.95mm_HandSolder | 3 |  |  | ~
5 | Unpolarized capacitor | C209 C210 | 10n/50V | C_0805_2012Metric_Pad1.15x1.40mm_HandSolder | 2 |  |  | ~
6 | Unpolarized capacitor | C206 | 10u/10V | C_0805_2012Metric_Pad1.15x1.40mm_HandSolder | 1 |  |  | ~
7 | Unpolarized capacitor, small symbol | C404 | 10u/10V | C_0603_1608Metric_Pad1.05x0.95mm_HandSolder | 1 |  |  | ~
8 | Unpolarized capacitor | C205 C401 C402 | 1u/35V | C_0805_2012Metric_Pad1.15x1.40mm_HandSolder | 3 |  |  | ~
9 | Unpolarized capacitor, small symbol | C301 | 1u/35V | C_0603_1608Metric_Pad1.05x0.95mm_HandSolder | 1 |  |  | ~
10 | Polarized capacitor | C204 | 22u/35V | C_Radial_D7.5_L11.2_P2.5 | 1 |  |  | ~
11 | Unpolarized capacitor, small symbol | C309 | 2u2/10V | C_0805_2012Metric_Pad1.15x1.40mm_HandSolder | 1 |  |  | ~
12 | Polarized capacitor | C201 | 470uF/35V | CP_Radial_D10.0mm_P5.00mm | 1 |  |  | ~
13 | Light emitting diode | D101 | LED_Green | LED_0603_HandSoldering | 1 |  |  | ~
14 | Schottky diode | D201 D202 | SS54 | D_SMA_Handsoldering | 2 |  | SS54 | https://www.farnell.com/datasheets/1441695.pdf
15 | Generic connector, single row, 01x02, script generated (kicad-library-utils/schlib/autogen/connector/) | J410 | AUDIO | PinHeader_1x02_P2.54mm_Vertical | 1 |  |  | ~
16 | Generic connector, single row, 01x02, script generated (kicad-library-utils/schlib/autogen/connector/) | J102 | BOOT0 | Pin_Header_Straight_1x02_Pitch1.27mm | 1 |  |  | ~
17 | Generic connector, single row, 01x02, script generated (kicad-library-utils/schlib/autogen/connector/) | J201 J301 J302 | Conn_01x02 | 2Pin_4mm | 3 |  |  | ~
18 | Generic connector, single row, 01x02, script generated (kicad-library-utils/schlib/autogen/connector/) | J401 J402 J403 J405 J406 J407 | Conn_01x02 | Molex_KK-254_AE-6410-02A_1x02_P2.54mm_Vertical | 6 |  |  | ~
19 | Generic connector, single row, 01x02, script generated (kicad-library-utils/schlib/autogen/connector/) | J404 J408 | Conn_01x02 | TerminalBlock_Phoenix_PT-1,5-2-5.0-H_1x02_P5.00mm_Horizontal | 2 |  |  | ~
20 | Generic connector, single row, 01x06, script generated (kicad-library-utils/schlib/autogen/connector/) | J103 J104 | SPORT | Pin_Header_Straight_2x03 | 2 |  |  | ~
21 | Generic connector, double row, 02x03, odd/even pin numbering scheme (row 1 odd numbers, row 2 even numbers), script generated (kicad-library-utils/schlib/autogen/connector/) | J409 | ServoCon | PinHeader_2x03_P2.54mm_Vertical | 1 |  |  | ~
22 | Generic connector, single row, 01x04, script generated (kicad-library-utils/schlib/autogen/connector/) | J106 | UART_EXP | PinHeader_2x02_P2.54mm_Vertical | 1 |  |  | ~
23 | USB Micro Type B connector | J105 | USB_B_Micro | USB_Micro-B | 1 |  |  | ~
24 | Jumper, normally closed, small symbol | JP101 JP401 | Jumper_NC_Small | PinHeader_1x02_P2.54mm_Vertical | 2 |  |  | ~
25 | Inductor | L202 | BCRH1212Y-680M | L_Sunlord_MWSA1206 | 1 | Sunlord | MWSA1206-470MT | https://datasheet.lcsc.com/szlcsc/Sunlord-MWSA1206-470MT_C115409.pdf
26 | Inductor | L201 | SPN30304R7MPTE | L_Sunlord_MWSA0402 | 1 | Sunlord | MWSA0402-4R7MT | https://datasheet.lcsc.com/szlcsc/Sunlord-MWSA0402-4R7MT_C136097.pdf
27 | 100A Id, 30V Vds, NexFET N-Channel Power MOSFET, 4.2mOhm Ron, Qg (typ) 11.8nC, SON8 5x6mm | Q404 Q408 | CSD17306Q5A | TDSON-8-1_HandSoldering | 2 | Texas Instruments | CSD17306Q5A | http://www.ti.com/lit/gpn/csd17306q5a
28 | MOSFET N-CH 30V 5A SOT23 | Q401 Q402 Q403 Q406 | IRLML6344TRPBF | SOT-23-3 | 4 | Infineon Technologies | IRLML6344TRPBF | https://www.infineon.com/dgdl/irlml6344pbf.pdf?fileId=5546d462533600a4015356689c44262c
29 | Resistor, small symbol | R402 R403 R404 R410 | 10 | R_0603_1608Metric_Pad1.05x0.95mm_HandSolder | 4 |  |  | ~
30 | Resistor, small symbol | R409 R411 | 100 | R_0603_1608Metric_Pad1.05x0.95mm_HandSolder | 2 |  |  | ~
31 | Resistor | R101 R201 R206 R401 R405 R406 R407 R408 R414 | 10k | R_0603_1608Metric_Pad1.05x0.95mm_HandSolder | 9 |  |  | ~
32 | Resistor, small symbol | R205 R302 R304 R305 R307 | 12k | R_0603_1608Metric_Pad1.05x0.95mm_HandSolder | 5 |  |  | ~
33 | Resistor, small symbol | R306 R308 | 18k | R_0603_1608Metric_Pad1.05x0.95mm_HandSolder | 2 |  |  | ~
34 | Resistor, small symbol | R105 | 1k5 | R_0603_1608Metric_Pad1.05x0.95mm_HandSolder | 1 |  |  | ~
35 | Resistor, small symbol | R202 R208 | 24k | R_0603_1608Metric_Pad1.05x0.95mm_HandSolder | 2 |  |  | ~
36 | Resistor | R102 R103 | 470R | R_0603_1608Metric_Pad1.05x0.95mm_HandSolder | 2 |  |  | ~
37 | Resistor | R104 R106 R107 R108 | 50R | R_0603_1608Metric_Pad1.05x0.95mm_HandSolder | 4 |  |  | ~
38 | Resistor, small symbol | R204 | 5k6 | R_0603_1608Metric_Pad1.05x0.95mm_HandSolder | 1 |  |  | ~
39 | Resistor, small symbol | R203 R301 R303 | 68k | R_0603_1608Metric_Pad1.05x0.95mm_HandSolder | 3 |  |  | ~
40 | Resistor, small symbol | R207 | 75k | R_0603_1608Metric_Pad1.05x0.95mm_HandSolder | 1 |  |  | ~
41 | Push button switch, generic, two pins | SW101 | SW_Push | SW_SPST_B3U-1000P | 1 | Omron | B3U-1000P | https://omronfs.omron.com/en_US/ecb/products/pdf/en-b3u.pdf
42 | 100A Unidirectional Hall-Effect Current Sensor, +5.0V supply, 40mV/A, CB-5 PSF | U302 | ACS758CB-100U-PSF | Allegro_PFF | 1 | Allegro | ACS758LCB-100B-PFF-T | http://www.allegromicro.com/~/media/Files/Datasheets/ACS758-Datasheet.ashx?la=en
43 | 100A Unidirectional Hall-Effect Current Sensor, +5.0V supply, 40mV/A, CB-5 PSF | U304 | ACS758LCB-100B-PFF-T | Allegro_PFF | 1 | Allegro | ACS758LCB-100B-PFF-T | http://www.allegromicro.com/~/media/Files/Datasheets/ACS758-Datasheet.ashx?la=en
44 |  | U403 | AD5160BRJZ10-R2 | SOT-23-8 | 1 | AD5160BRJZ10-R2 | Analog Devices | https://www.analog.com/media/en/technical-documentation/data-sheets/AD5160.pdf
45 |  | U201 | AP1501-K5 | TO-263-5_TabPin3 | 1 | Diodes Inc | AP1501-K5 | https://www.diodes.com/assets/Datasheets/AP1501.pdf
46 |  | U102 | IS25LP032D | SOIC-8_W5.6mm | 1 | ISSI | IS25LP032D | http://www.issi.com/WW/pdf/25LP-WP032D.pdf
47 | 150mA 16V Low-noise Low-dropout Regulator With Shutdown, 5.0V output voltage, SOT-23-5 | U301 | LP2985-5.0 | SOT-23-5_HandSoldering | 1 | Texas Instruments | LP2985-5.0 | http://www.ti.com/lit/ds/symlink/lp2985.pdf
48 |  | U401 U402 | MCP1416 | SOT-23-5_HandSoldering | 2 | Microchip | MCP1416 | http://ww1.microchip.com/downloads/en/DeviceDoc/20002092F.pdf
49 | 1MHz, Low-Power Op Amp, SOT-23-5 | U303 U305 U404 | MCP6001-OT | SOT-23-5_HandSoldering | 3 | Microchip | MCP6001-OT | http://ww1.microchip.com/downloads/en/DeviceDoc/21733j.pdf
50 |  | U202 | RT6200 | SOT-23-6_Handsoldering | 1 | Richtek Tech | RT6200 | https://www.richtek.com/assets/product_file/RT6200/DS6200-04.pdf
51 |  | U101 | STM32F303CBx | LQFP-48_7x7mm_Pitch0.5mm | 1 | ST Microelectronics | STM32F303CB | https://www.st.com/resource/en/datasheet/stm32f303cb.pdf
52 | OPTOISO 3.75KV PSH PULL SO6-5 | U405 U406 | TLP2361_TPL_E | SOIC-6-5_W4.55mm | 2 | Toshiba Semiconductor and Storage | TLP2361-TPLECT | https://toshiba.semicon-storage.com/info/docget.jsp?did=14229&prodName=TLP2361
53 |  | X101 | SG-310_SCF_8.000000MHZ | SG- 310 | 1 | Epson | SG-310_SCF_8.000000MHZ | https://support.epson.biz/td/api/doc_check.php?dl=brief_SG-310SEF&lang=en

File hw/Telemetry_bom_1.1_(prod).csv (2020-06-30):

Component | Description | Designator | Comment | Footprint | Quantity Per PCB | Datasheet | MPN | Manufacturer
1 | Unpolarized capacitor, small symbol | C101 | 100n/50V | 0603_C | 1 | ~
2 | Unpolarized capacitor, small symbol | C102 | 100n/50V | 0603_C | 1 | ~
3 | Unpolarized capacitor, small symbol | C103 | 100n/50V | 0603_C | 1 | ~
4 | Unpolarized capacitor, small symbol | C104 | 100n/50V | 0603_C | 1 | ~
5 | Unpolarized capacitor, small symbol | C105 | 100n/50V | 0603_C | 1 | ~
6 | Unpolarized capacitor, small symbol | C106 | 100n/50V | 0603_C | 1 | ~
7 | Unpolarized capacitor | C207 | 100n/50V | 0805_C | 1 | ~
8 | Unpolarized capacitor, small symbol | C211 | 100n/50V | 0805_C | 1 | ~
9 | Unpolarized capacitor | C212 | 100n/50V | 0805_C | 1 | ~
10 | Unpolarized capacitor, small symbol | C303 | 100n/50V | 0603_C | 1 | ~
11 | Unpolarized capacitor, small symbol | C304 | 100n/50V | 0603_C | 1 | ~
12 | Unpolarized capacitor, small symbol | C306 | 100n/50V | 0603_C | 1 | ~
13 | Unpolarized capacitor, small symbol | C307 | 100n/50V | 0603_C | 1 | ~
14 | Unpolarized capacitor, small symbol | C403 | 100n/50V | 0603_C | 1 | ~
15 | Unpolarized capacitor, small symbol | C405 | 100n/50V | 0603_C | 1 | ~
16 | Unpolarized capacitor, small symbol | C406 | 100n/50V | 0603_C | 1 | ~
17 | Unpolarized capacitor, small symbol | C407 | 100n/50V | 0603_C | 1 | ~
18 | Unpolarized capacitor, small symbol | C408 | 100n/50V | 0603_C | 1 | ~
19 | Unpolarized capacitor, small symbol | C409 | 100n/50V | 0603_C | 1 | ~
20 | Unpolarized capacitor, small symbol | C411 | 100n/50V | 0603_C | 1 | ~
21 | Unpolarized capacitor, small symbol | C412 | 100n/50V | 0603_C | 1 | ~
22 | Unpolarized capacitor, small symbol | C203 | 10n/50V | 0603_C | 1 | ~
23 | Unpolarized capacitor | C209 | 10n/50V | 0805_C | 1 | ~
24 | Unpolarized capacitor | C210 | 10n/50V | 0805_C | 1 | ~
25 | Unpolarized capacitor | C213 | 10n/50V | 0603_C | 1 | ~
26 | Unpolarized capacitor, small symbol | C302 | 10n/50V | 0603_C | 1 | ~
27 | Unpolarized capacitor | C206 | 10u/10V | 0805_C | 1 | ~
28 | Unpolarized capacitor, small symbol | C404 | 10u/10V | 0603_C | 1 | ~
29 | Unpolarized capacitor, small symbol | C410 | 10u/10V | 0603_C | 1 | ~
30 | Unpolarized capacitor | C205 | 1u/35V | 0805_C | 1 | ~
31 | Unpolarized capacitor, small symbol | C301 | 1u/35V | 0603_C | 1 | ~
32 | Unpolarized capacitor, small symbol | C401 | 1u/35V | 0805_C | 1 | ~
33 | Unpolarized capacitor, small symbol | C402 | 1u/35V | 0805_C | 1 | ~
34 | Unpolarized capacitor, small symbol | C309 | 2u2/10V | 0805_C | 1 | ~
35 | Light emitting diode | D101 | LED_Green | LED_0603_HandSoldering | 1 | ~
36 | Schottky diode | D201 | SS54 | D_SMA | 1 | https://www.farnell.com/datasheets/1441695.pdf | SS54
37 | Schottky diode | D202 | SS54 | D_SMA | 1 | https://www.farnell.com/datasheets/1441695.pdf | SS54
38 | Inductor | L202 | BCRH1212Y-680M | L_Sunlord_MWSA1206 | 1 | https://datasheet.lcsc.com/szlcsc/Sunlord-MWSA1206-470MT_C115409.pdf | MWSA1206-470MT | Sunlord
39 | Inductor | L201 | SPN30304R7MPTE | L_Sunlord_MWSA0402 | 1 | https://datasheet.lcsc.com/szlcsc/Sunlord-MWSA0402-4R7MT_C136097.pdf | MWSA0402-4R7MT | Sunlord
40 | 100A Id, 30V Vds, NexFET N-Channel Power MOSFET, 4.2mOhm Ron, Qg (typ) 11.8nC, SON8 5x6mm | Q404 | CSD17306Q5A | TDSON-8-1_HandSoldering | 1 | http://www.ti.com/lit/gpn/csd17306q5a | CSD17306Q5A | Texas Instruments
41 | 100A Id, 30V Vds, NexFET N-Channel Power MOSFET, 4.2mOhm Ron, Qg (typ) 11.8nC, SON8 5x6mm | Q408 | CSD17306Q5A | TDSON-8-1_HandSoldering | 1 | http://www.ti.com/lit/gpn/csd17306q5a | CSD17306Q5A | Texas Instruments
42 | MOSFET N-CH 30V 5A SOT23 | Q401 | IRLML6344TRPBF | SOT-23-3 | 1 | https://www.infineon.com/dgdl/irlml6344pbf.pdf?fileId=5546d462533600a4015356689c44262c | IRLML6344TRPBF | Infineon Technologies
43 | MOSFET N-CH 30V 5A SOT23 | Q402 | IRLML6344TRPBF | SOT-23-3 | 1 | https://www.infineon.com/dgdl/irlml6344pbf.pdf?fileId=5546d462533600a4015356689c44262c | IRLML6344TRPBF | Infineon Technologies
44 | MOSFET N-CH 30V 5A SOT23 | Q403 | IRLML6344TRPBF | SOT-23-3 | 1 | https://www.infineon.com/dgdl/irlml6344pbf.pdf?fileId=5546d462533600a4015356689c44262c | IRLML6344TRPBF | Infineon Technologies
45 | MOSFET N-CH 30V 5A SOT23 | Q406 | IRLML6344TRPBF | SOT-23-3 | 1 | https://www.infineon.com/dgdl/irlml6344pbf.pdf?fileId=5546d462533600a4015356689c44262c | IRLML6344TRPBF | Infineon Technologies
46 | Resistor | R101 | 10k | 0603_R | 1 | ~
47 | Resistor, small symbol | R201 | 10k | 0603_R | 1 | ~
48 | Resistor | R206 | 10k | 0603_R | 1 | ~
49 | Resistor, small symbol | R413 | 10k | 0603_R | 1 | ~
50 | Resistor, small symbol | R415 | 10k | 0603_R | 1 | ~
51 | Resistor, small symbol | R417 | 10k | 0603_R | 1 | ~
52 | Resistor, small symbol | R418 | 10k | 0603_R | 1 | ~
53 | Resistor, small symbol | R205 | 12k | 0603_R | 1 | ~
54 | Resistor, small symbol | R302 | 12k | 0603_R | 1 | ~
55 | Resistor, small symbol | R304 | 12k | 0603_R | 1 | ~
56 | Resistor, small symbol | R305 | 12k | 0603_R | 1 | ~
57 | Resistor, small symbol | R307 | 12k | 0603_R | 1 | ~
58 | Resistor, small symbol | R401 | 15k | 0603_R | 1 | ~
59 | Resistor, small symbol | R416 | 15k | 0603_R | 1 | ~
60 | Resistor, small symbol | R306 | 18k | 0603_R | 1 | ~
61 | Resistor, small symbol | R308 | 18k | 0603_R | 1 | ~
62 | Resistor, small symbol | R105 | 1k5 | 0603_R | 1 | ~
63 | Resistor, small symbol | R402 | 1k5 | 0603_R | 1 | ~
64 | Resistor, small symbol | R403 | 1k5 | 0603_R | 1 | ~
65 | Resistor, small symbol | R404 | 1k5 | 0603_R | 1 | ~
66 | Resistor, small symbol | R409 | 1k5 | 0603_R | 1 | ~
67 | Resistor, small symbol | R410 | 1k5 | 0603_R | 1 | ~
68 | Resistor, small symbol | R411 | 1k5 | 0603_R | 1 | ~
69 | Resistor, small symbol | R202 | 24k | 0603_R | 1 | ~
70 | Resistor, small symbol | R208 | 24k | 0603_R | 1 | ~
71 | Resistor | R102 | 470R | 0603_R | 1 | ~
72 | Resistor | R103 | 470R | 0603_R | 1 | ~
73 | Resistor | R104 | 50R | 0603_R | 1 | ~
74 | Resistor | R106 | 50R | 0603_R | 1 | ~
75 | Resistor | R107 | 50R | 0603_R | 1 | ~
76 | Resistor | R108 | 50R | 0603_R | 1 | ~
77 | Resistor, small symbol | R203 | 68k | 0603_R | 1 | ~
78 | Resistor, small symbol | R301 | 68k | 0603_R | 1 | ~
79 | Resistor, small symbol | R303 | 68k | 0603_R | 1 | ~
80 | Resistor, small symbol | R204 | 6k2 | 0603_R | 1 | ~
81 | Resistor, small symbol | R408 | 6k2 | 0603_R | 1 | ~
82 | Resistor, small symbol | R207 | 75k | 0603_R | 1 | ~
83 | Resistor, small symbol | R405 | 75k | 0603_R | 1 | ~
84 | Resistor, small symbol | R406 | 75k | 0603_R | 1 | ~
85 | Resistor, small symbol | R407 | 75k | 0603_R | 1 | ~
86 | Resistor, small symbol | R414 | 75k | 0603_R | 1 | ~
87 |  | U403 | AD5160BRJZ10-R2 | SOT-23-8 | 1 | https://www.analog.com/media/en/technical-documentation/data-sheets/AD5160.pdf | Analog Devices | AD5160BRJZ10-R2
88 |  | U201 | AP1501-K5 | TO-263-5_TabPin3 | 1 | https://www.diodes.com/assets/Datasheets/AP1501.pdf | AP1501-K5 | Diodes Inc
89 |  | U102 | IS25LP032D | SOIC-8_W5.6mm | 1 | http://www.issi.com/WW/pdf/25LP-WP032D.pdf | IS25LP032D | ISSI
90 | 150mA 16V Low-noise Low-dropout Regulator With Shutdown, 5.0V output voltage, SOT-23-5 | U301 | LP2985-5.0 | SOT-23-5 | 1 | http://www.ti.com/lit/ds/symlink/lp2985.pdf | LP2985-5.0 | Texas Instruments
91 |  | U401 | MCP1416 | SOT-23-5 | 1 | http://ww1.microchip.com/downloads/en/DeviceDoc/20002092F.pdf | MCP1416 | Microchip
92 |  | U402 | MCP1416 | SOT-23-5 | 1 | http://ww1.microchip.com/downloads/en/DeviceDoc/20002092F.pdf | MCP1416 | Microchip
93 | 1MHz, Low-Power Op Amp, SOT-23-5 | U303 | MCP6001-OT | SOT-23-5 | 1 | http://ww1.microchip.com/downloads/en/DeviceDoc/21733j.pdf | MCP6001-OT | Microchip
94 | 1MHz, Low-Power Op Amp, SOT-23-5 | U305 | MCP6001-OT | SOT-23-5 | 1 | http://ww1.microchip.com/downloads/en/DeviceDoc/21733j.pdf | MCP6001-OT | Microchip
95 | 1MHz, Low-Power Op Amp, SOT-23-5 | U404 | MCP6001-OT | SOT-23-5 | 1 | http://ww1.microchip.com/downloads/en/DeviceDoc/21733j.pdf | MCP6001-OT | Microchip
96 | 1MHz, Low-Power Op Amp, SOT-23-5 | U407 | MCP6001-OT | SOT-23-5 | 1 | http://ww1.microchip.com/downloads/en/DeviceDoc/21733j.pdf | MCP6001-OT | Microchip
97 |  | U202 | RT6200 | SOT-23-6_Handsoldering | 1 | https://www.richtek.com/assets/product_file/RT6200/DS6200-04.pdf | RT6200 | Richtek Tech
98 |  | U101 | STM32F303CBx | LQFP-48_7x7mm_Pitch0.5mm | 1 | https://www.st.com/resource/en/datasheet/stm32f303cb.pdf | STM32F303CB | ST Microelectronics
99 | OPTOISO 3.75KV PSH PULL SO6-5 | U405 | TLP2361_TPL_E | SOIC-6-5_W4.55mm | 1 | https://toshiba.semicon-storage.com/info/docget.jsp?did=14229&prodName=TLP2361 | TLP2361-TPLECT | Toshiba Semiconductor and Storage
100 | OPTOISO 3.75KV PSH PULL SO6-5 | U406 | TLP2361_TPL_E | SOIC-6-5_W4.55mm | 1 | https://toshiba.semicon-storage.com/info/docget.jsp?did=14229&prodName=TLP2361 | TLP2361-TPLECT | Toshiba Semiconductor and Storage
101 |  | X101 | SG-310_SCF_8.000000MHZ | SG- 310 | 1 | https://support.epson.biz/td/api/doc_check.php?dl=brief_SG-310SEF&lang=en | SG-310_SCF_8.000000MHZ | Epson
Component Groups: | 130
Component Count: | 130
Fitted Components: | 101
Number of PCBs: | 1
Total components: | 101
Schematic Version: | 1.1
Schematic Date: | 2020-02-24
PCB Variant: | prod
BoM Date: | 1.3.2020 13.21.48
Schematic Source: | C:\Users\akiku\GIT\rctelemetry\hw\Telemetry.sch
KiCad Version: | Eeschema (5.1.5)-3

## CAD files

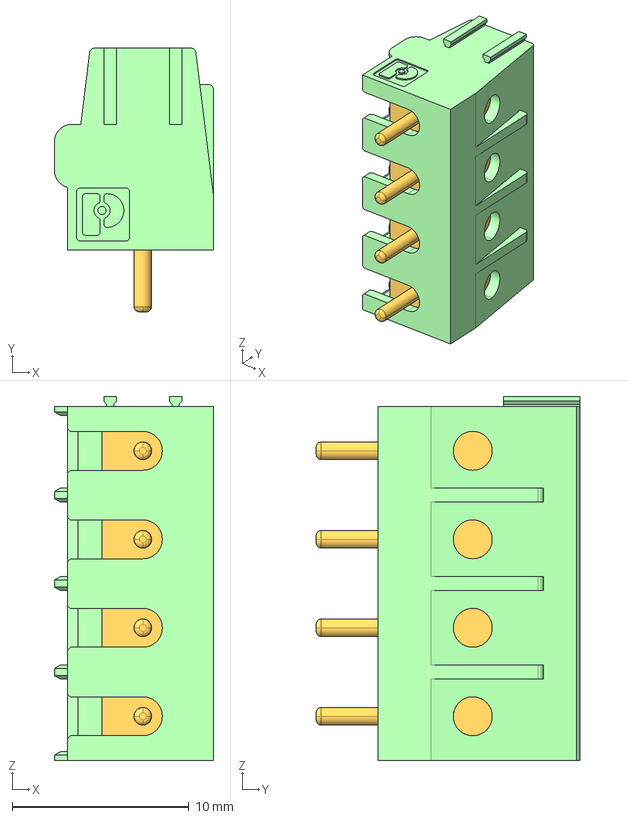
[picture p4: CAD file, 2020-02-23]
hw/Models/pxc_1935187.stp
9.00 x 14.9 x 20.6 mm

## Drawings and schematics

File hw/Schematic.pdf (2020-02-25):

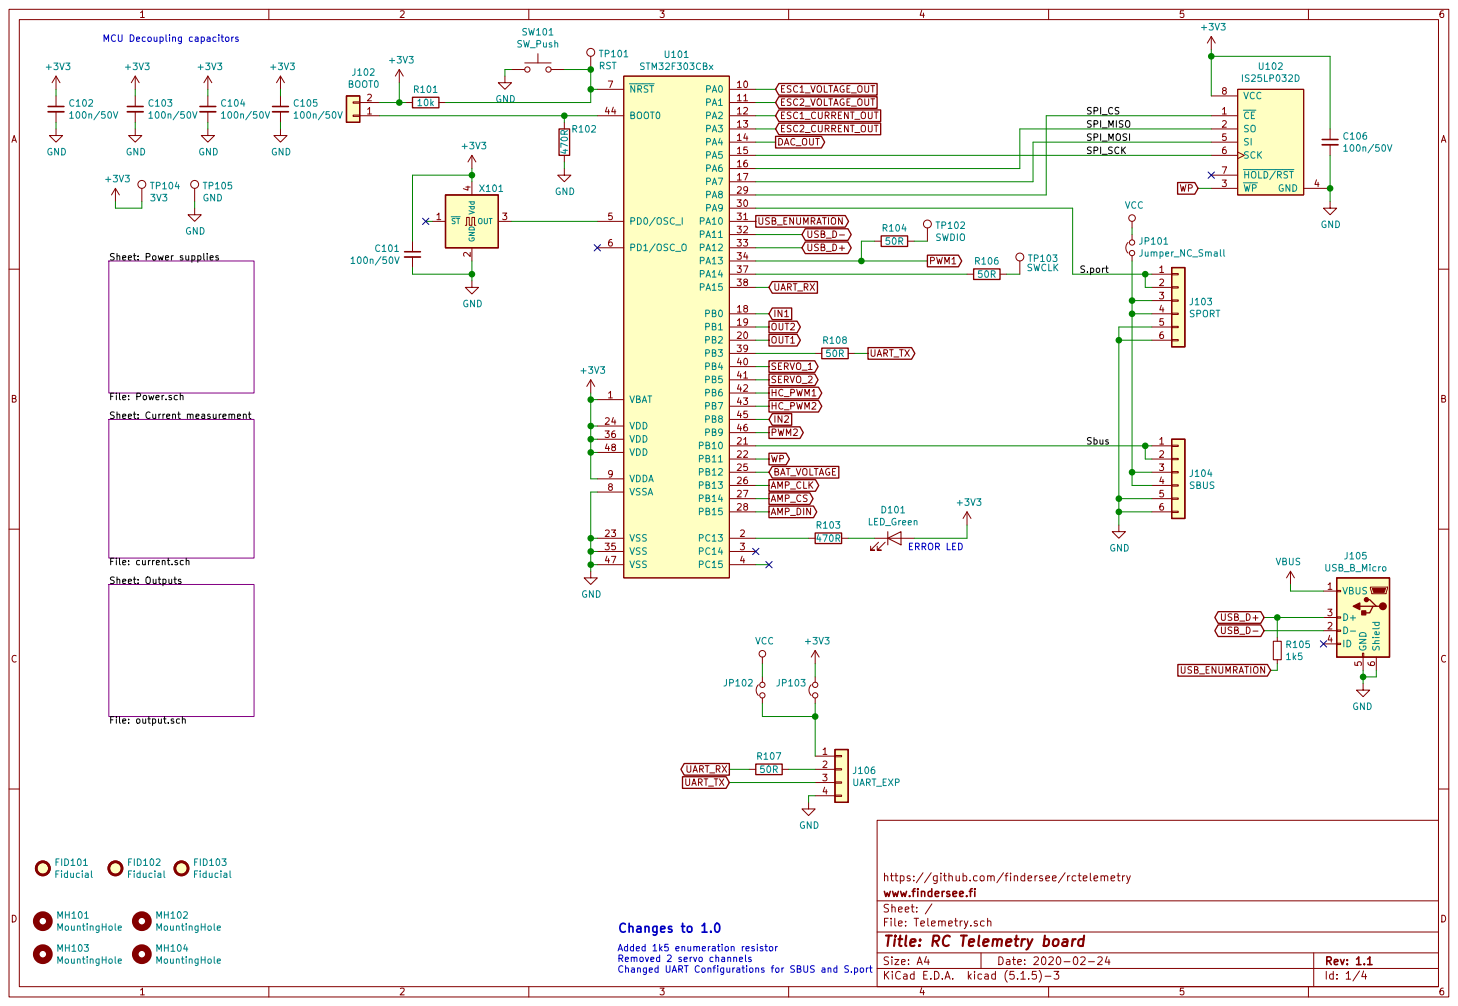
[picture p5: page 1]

2 OUT 3 Vdd 4X101 CE 1 SO 2 WP 3 GND 4 SI 5 SCK 6 HOLD/RST 7 VCC 8 U102
Sheet: Power supplies File: Power.sch Sheet: Current measurement File: current.sch Sheet: Outputs

File: Telemetry.sch Sheet: / www.findersee.fi https://github.com/findersee/rctelemetry

Id: 1/4 Title: RC Telemetry board

Added 1k5 enumeration resistor Removed 2 servo channels Changed UART Configurations for SBUS and S.port

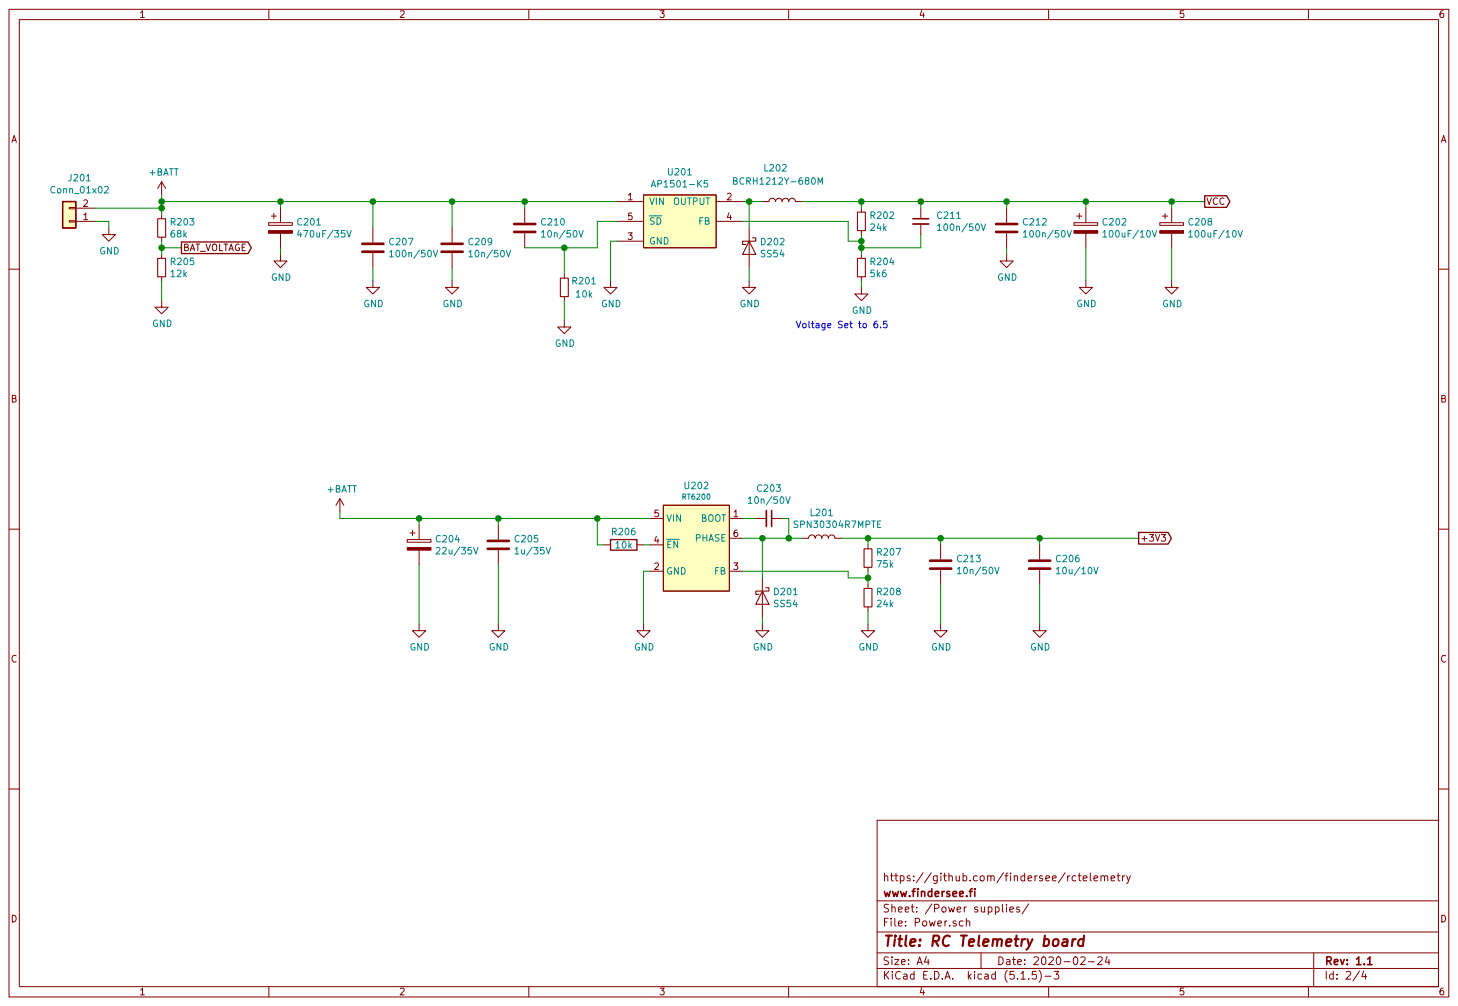
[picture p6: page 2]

File: Power.sch Sheet: /Power supplies/ www.findersee.fi https://github.com/findersee/rctelemetry

Id: 2/4 Title: RC Telemetry board

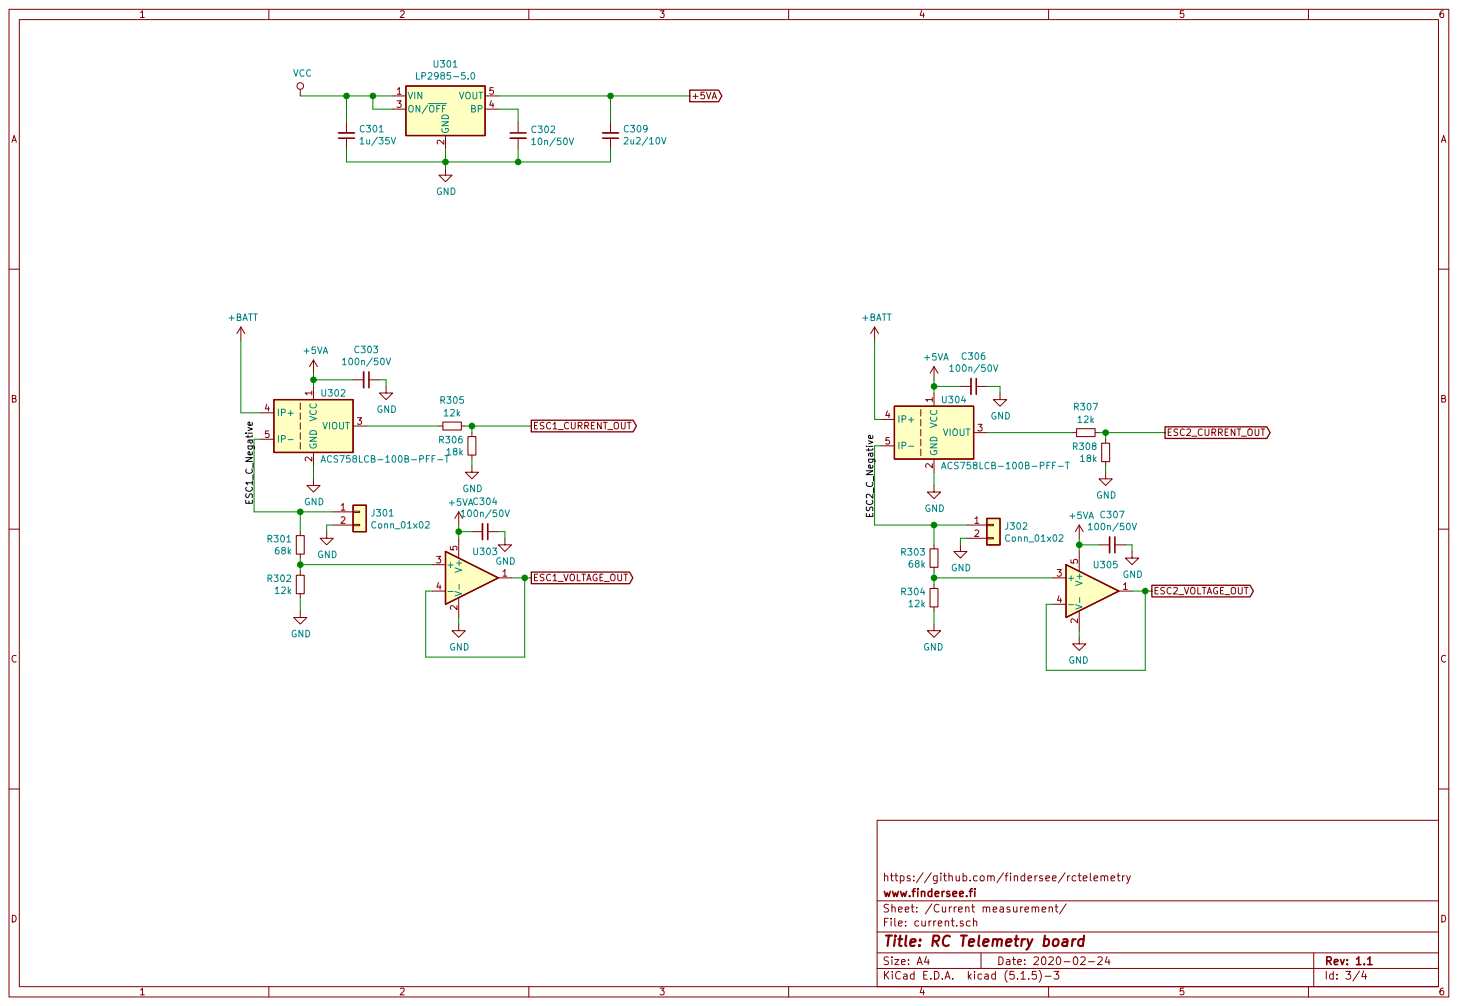
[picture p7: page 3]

File: current.sch Sheet: /Current measurement/ www.findersee.fi https://github.com/findersee/rctelemetry R306

Id: 3/4 Title: RC Telemetry board

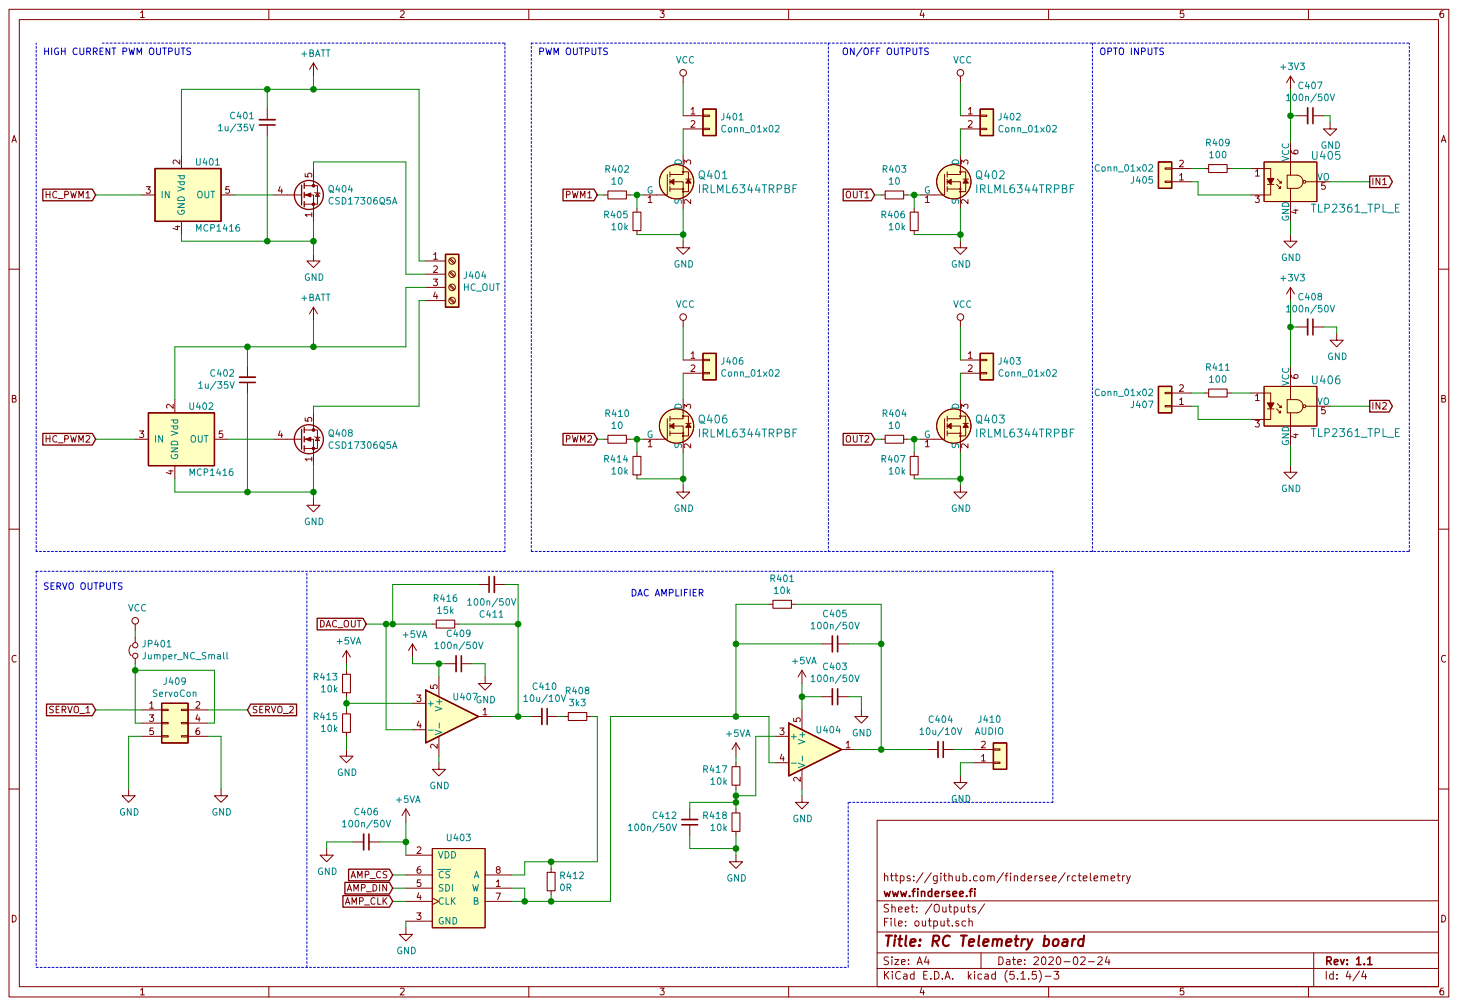
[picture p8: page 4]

Sheet: /Outputs/ www.findersee.fi https://github.com/findersee/rctelemetry

File: output.sch
Id: 4/4 Title: RC Telemetry board

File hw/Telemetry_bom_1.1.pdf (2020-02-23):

## KiBoM PCB Bill of Materials

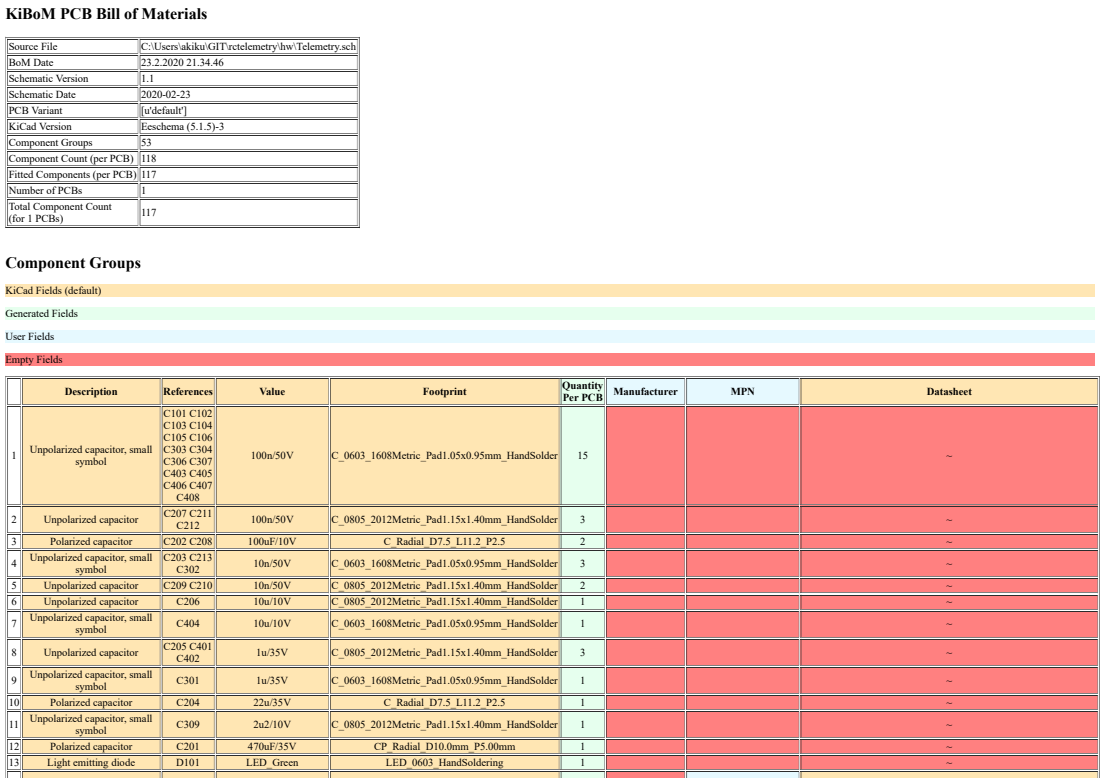
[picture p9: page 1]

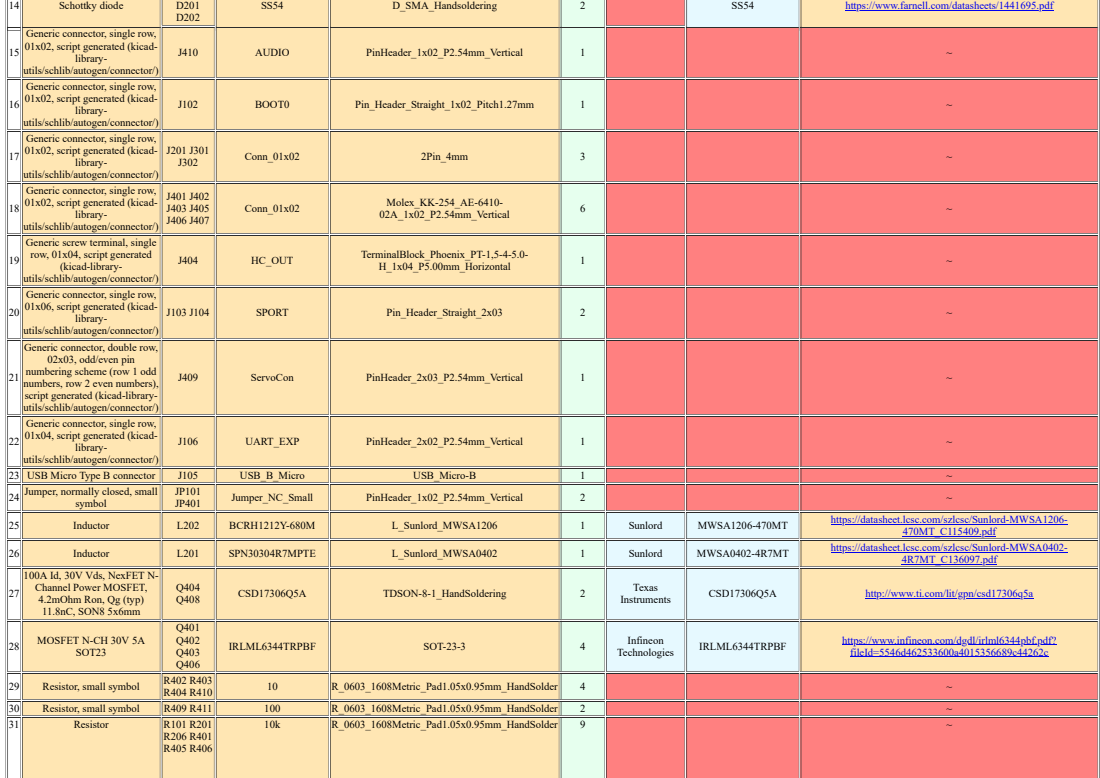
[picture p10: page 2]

Generic connector, single row,
01x02, script generated (kicad-
utils/schlib/autogen/connector/)
Generic screw terminal, single
row, 01x04, script generated
01x06, script generated (kicad-
Generic connector, double row,
02x03, odd/even pin
numbering scheme (row 1 odd
numbers, row 2 even numbers),
script generated (kicad-library-
01x04, script generated (kicad-

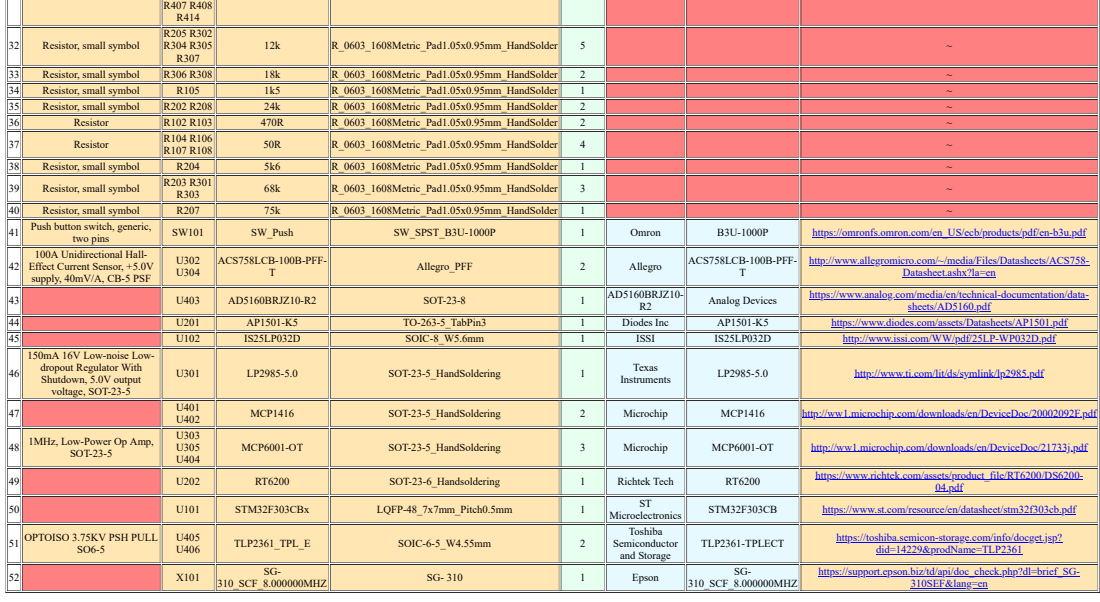
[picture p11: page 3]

http://www.allegromicro.com/~/media/Files/Datasheets/ACS758-

Datasheet.ashx?la=en (http://www.allegromicro.com/~/media/Files/Datasheets/ACS758-Datasheet.ashx?la=en)

https://support.epson.biz/td/api/doc_check.php?dl=brief_SG-

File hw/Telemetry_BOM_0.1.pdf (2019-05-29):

## KiBoM PCB Bill of Materials

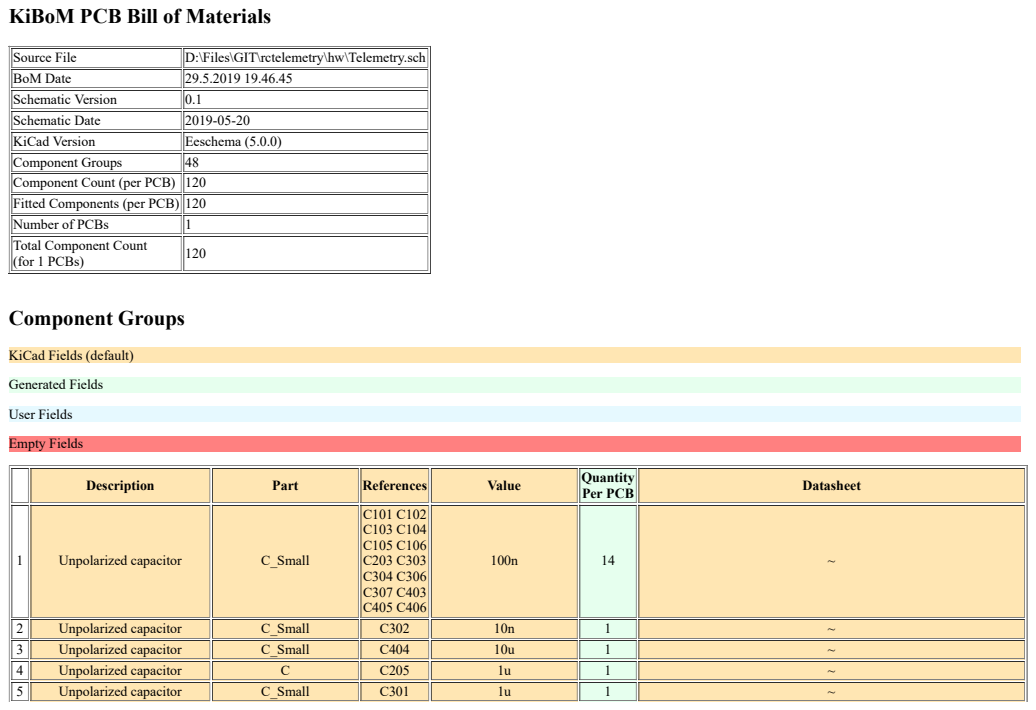
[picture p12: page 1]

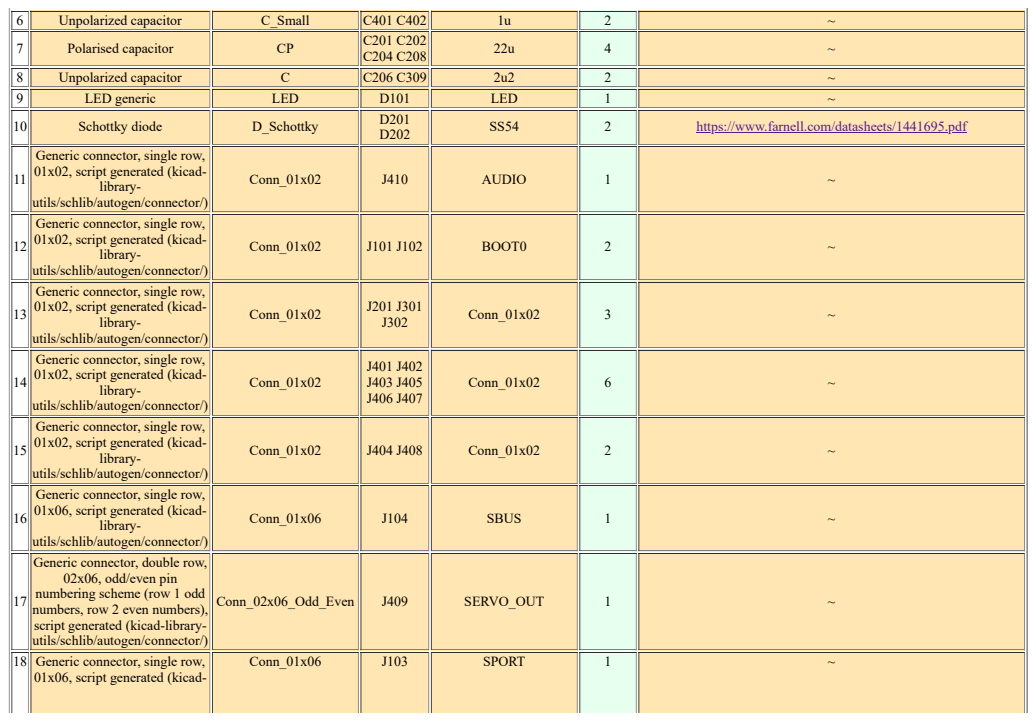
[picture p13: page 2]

Generic connector, single row,
01x02, script generated (kicad-
utils/schlib/autogen/connector/)
01x06, script generated (kicad-
Generic connector, double row,
02x06, odd/even pin
numbering scheme (row 1 odd
numbers, row 2 even numbers),
script generated (kicad-library-

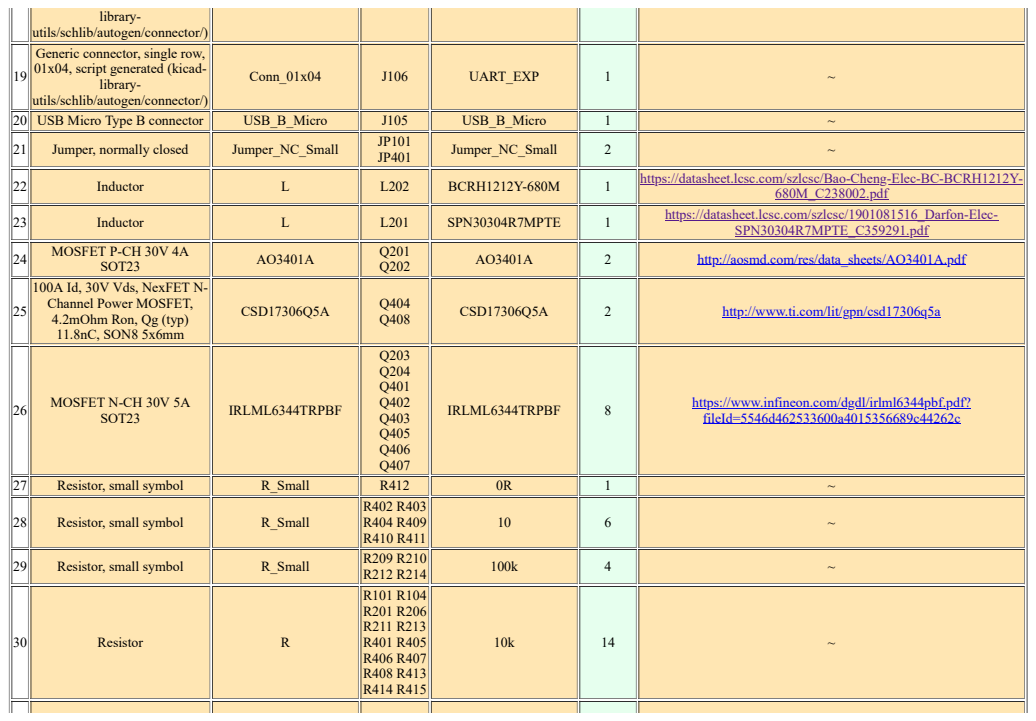
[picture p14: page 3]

utils/schlib/autogen/connector/)
Generic connector, single row,
01x04, script generated (kicad-

https://datasheet.lcsc.com/szlcsc/Bao-Cheng-Elec-BC-BCRH1212Y-

https://datasheet.lcsc.com/szlcsc/1901081516_Darfon-Elec-

https://www.infineon.com/dgdl/irlml6344pbf.pdf?
fileId=5546d462533600a4015356689c44262c (https://www.infineon.com/dgdl/irlml6344pbf.pdf?fileId=5546d462533600a4015356689c44262c)

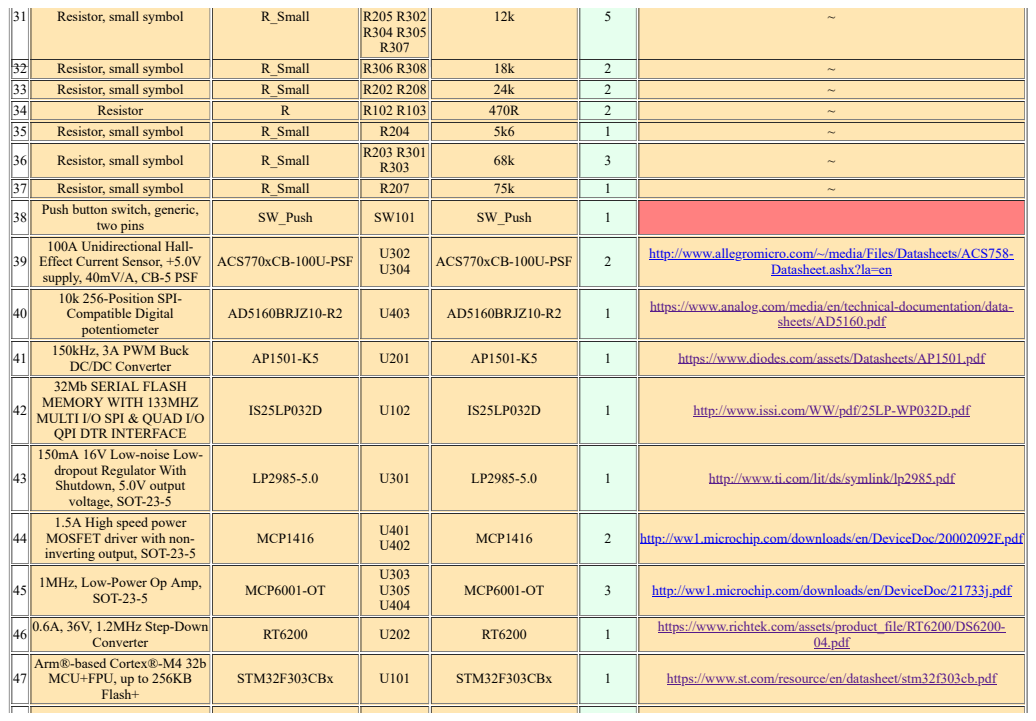
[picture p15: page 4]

http://www.allegromicro.com/~/media/Files/Datasheets/ACS758-

Datasheet.ashx?la=en (http://www.allegromicro.com/~/media/Files/Datasheets/ACS758-Datasheet.ashx?la=en)

https://www.analog.com/media/en/technical-documentation/data-

MOSFET driver with non-

https://www.richtek.com/assets/product_file/RT6200/DS6200-

MCU+FPU, up to 256KB

48 Crystal oscillator (SPXO) CMOS output

SG-310_SCF_8.000000MHZ

X101 | SG-
310_SCF_8.000000MHZ
1 | https://support.epson.biz/td/api/doc_check.php?dl=brief_SG-
310SEF&lang=en (https://support.epson.biz/td/api/doc_check.php?dl=brief_SG-310SEF&lang=en)

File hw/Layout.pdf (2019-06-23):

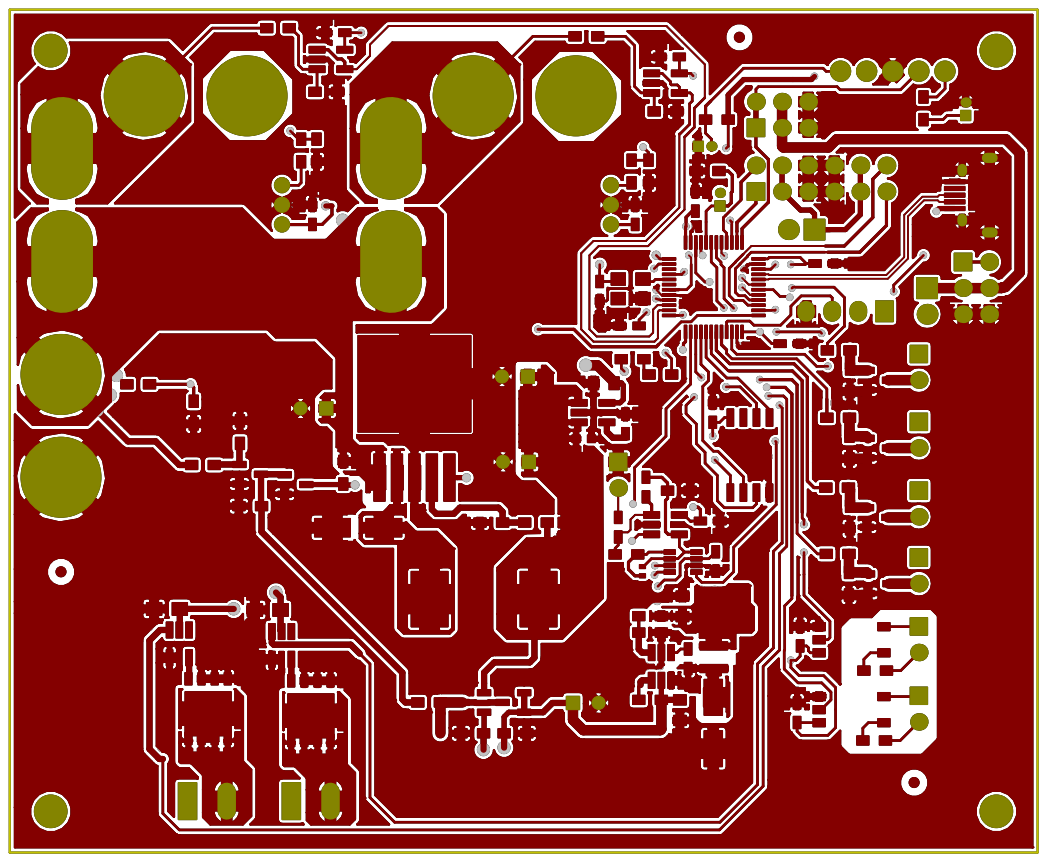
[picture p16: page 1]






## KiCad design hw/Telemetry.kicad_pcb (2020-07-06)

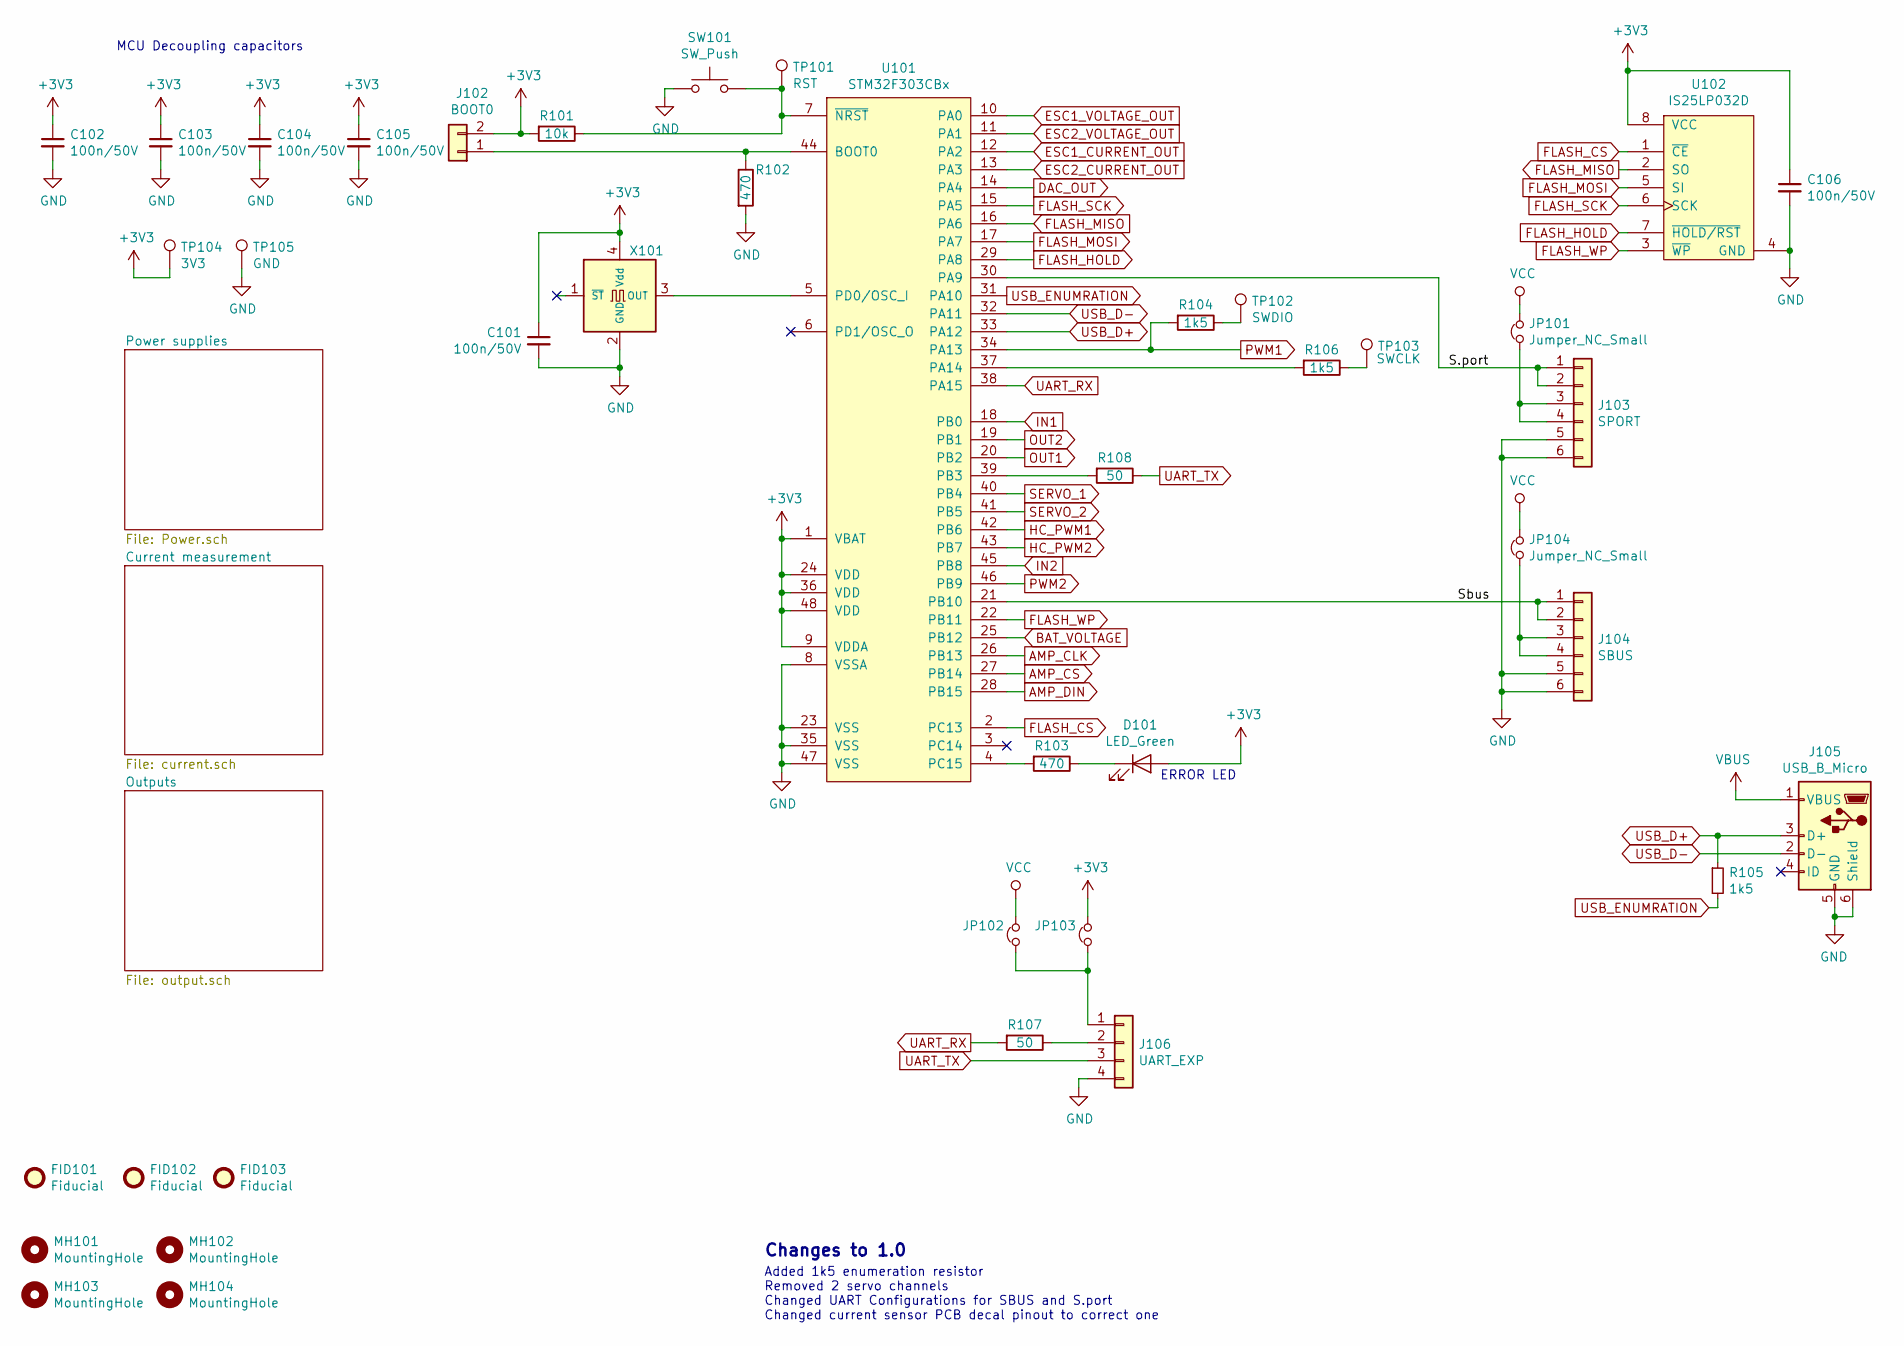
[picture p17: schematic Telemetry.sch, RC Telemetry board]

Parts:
C101, C102, C103, C104, C105, C106: 100n/50V; C_0603_1608Metric_Pad1.05x0.95mm_HandSolder
D101: LED_Green; LED_0603_HandSoldering
FID101, FID102, FID103: Fiducial; Fiducial_1mm_Mask2mm
J102: BOOT0; Pin_Header_Straight_1x02_Pitch1.27mm
J103: SPORT; Pin_Header_Straight_2x03
J104: SBUS; Pin_Header_Straight_2x03
J105: USB_B_Micro; USB_Micro-B
J106: UART_EXP; PinHeader_2x02_P2.54mm_Vertical
JP101, JP104: Jumper_NC_Small; PinHeader_1x02_P1.27mm_Vertical
JP102, JP103: Jumper_NC_Small; R_0402_1005Metric
MH101, MH102, MH103, MH104: MountingHole; MountingHole_3.2mm_M3_DIN965
R101: 10k; R_0603_1608Metric_Pad1.05x0.95mm_HandSolder
R102, R103: 470; R_0603_1608Metric_Pad1.05x0.95mm_HandSolder
R104, R105, R106: 1k5; R_0603_1608Metric_Pad1.05x0.95mm_HandSolder
R107, R108: 50; R_0603_1608Metric_Pad1.05x0.95mm_HandSolder
SW101: SW_Push; SW_SPST_B3U-1000P; MPN B3U-1000P
TP101: RST; SolderWirePad_single_0-8mmDrill
TP102: SWDIO; SolderWirePad_single_0-8mmDrill
TP103: SWCLK; SolderWirePad_single_0-8mmDrill
TP104: 3V3; SolderWirePad_single_0-8mmDrill
TP105: GND; SolderWirePad_single_0-8mmDrill
U101: STM32F303CBx; LQFP-48_7x7mm_Pitch0.5mm; MPN STM32F303CB
U102: IS25LP032D; SOIC-8_W5.6mm; MPN IS25LP032D
X101: SG-310_SCF_8.000000MHZ; SG- 310; MPN SG-310_SCF_8.000000MHZ

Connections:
+3V3: C101.1, C102.1, C103.1, C104.1, C105.1, C106.1, D101.2 (A), J102.2, JP103.2, R101.2, TP104.1, U101.1 (VBAT), U101.9 (VDDA), U101.24 (VDD), U101.36 (VDD), U101.48 (VDD), U102.8 (VCC), X101.4 (Vdd); also elsewhere on the board
/S.port: J103.1, J103.2, U101.30 (PA9)
/Sbus: J104.1, J104.2, U101.21 (PB10)
AMP_CLK: U101.26 (PB13); also elsewhere on the board
AMP_CS: U101.27 (PB14); also elsewhere on the board
AMP_DIN: U101.28 (PB15); also elsewhere on the board
BAT_VOLTAGE: U101.25 (PB12); also elsewhere on the board
DAC_OUT: U101.14 (PA4); also elsewhere on the board
ESC1_CURRENT_OUT: U101.12 (PA2); also elsewhere on the board
ESC1_VOLTAGE_OUT: U101.10 (PA0); also elsewhere on the board
ESC2_CURRENT_OUT: U101.13 (PA3); also elsewhere on the board
ESC2_VOLTAGE_OUT: U101.11 (PA1); also elsewhere on the board
FLASH_CS: U101.2 (PC13), U102.1 (~CE)
FLASH_HOLD: U101.29 (PA8), U102.7 (~HOLD/RST)
FLASH_MISO: U101.16 (PA6), U102.2 (SO)
FLASH_MOSI: U101.17 (PA7), U102.5 (SI)
FLASH_SCK: U101.15 (PA5), U102.6 (SCK)
FLASH_WP: U101.22 (PB11), U102.3 (~WP)
GND: C101.2, C102.2, C103.2, C104.2, C105.2, C106.2, J103.5, J103.6, J104.5, J104.6, J105.5 (GND), J105.6 (Shield), J106.4, R102.2, SW101.1, TP105.1, U101.8 (VSSA), U101.23 (VSS), U101.35 (VSS), U101.47 (VSS), U102.4 (GND), X101.2 (GND); also elsewhere on the board
HC_PWM1: U101.42 (PB6); also elsewhere on the board
HC_PWM2: U101.43 (PB7); also elsewhere on the board
IN1: U101.18 (PB0); also elsewhere on the board
IN2: U101.45 (PB8); also elsewhere on the board
unnamed: D101.1 (K), R103.1
unnamed: J102.1, R102.1, U101.44 (BOOT0)
unnamed: J103.3, J103.4, JP101.1
unnamed: J104.3, J104.4, JP104.1
unnamed: J106.1, JP102.1, JP103.1
unnamed: J106.2, R107.1
unnamed: R101.1, SW101.2, TP101.1, U101.7 (~NRST)
unnamed: R103.2, U101.4 (PC15)
unnamed: R104.1, TP102.1
unnamed: R106.1, TP103.1
unnamed: R106.2, U101.37 (PA14)
unnamed: R108.2, U101.39 (PB3)
unnamed: U101.5 (PD0/OSC_I), X101.3 (OUT)
OUT1: U101.20 (PB2); also elsewhere on the board
OUT2: U101.19 (PB1); also elsewhere on the board
PWM1: R104.2, U101.34 (PA13); also elsewhere on the board
PWM2: U101.46 (PB9); also elsewhere on the board
SERVO_1: U101.40 (PB4); also elsewhere on the board
SERVO_2: U101.41 (PB5); also elsewhere on the board
UART_RX: R107.2, U101.38 (PA15)
UART_TX: J106.3, R108.1
USB_D+: J105.3 (D+), R105.1, U101.33 (PA12)
USB_D-: J105.2 (D-), U101.32 (PA11)
USB_ENUMRATION: R105.2, U101.31 (PA10)
VBUS: J105.1 (VBUS)
VCC: JP101.2, JP102.2, JP104.2; also elsewhere on the board

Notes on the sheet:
ERROR LED
Changes to 1.0
MCU Decoupling capacitors
Added 1k5 enumeration resistor Removed 2 servo channels Changed UART Configurations for SBUS and S.port Changed current sensor PCB decal pinout to correct one

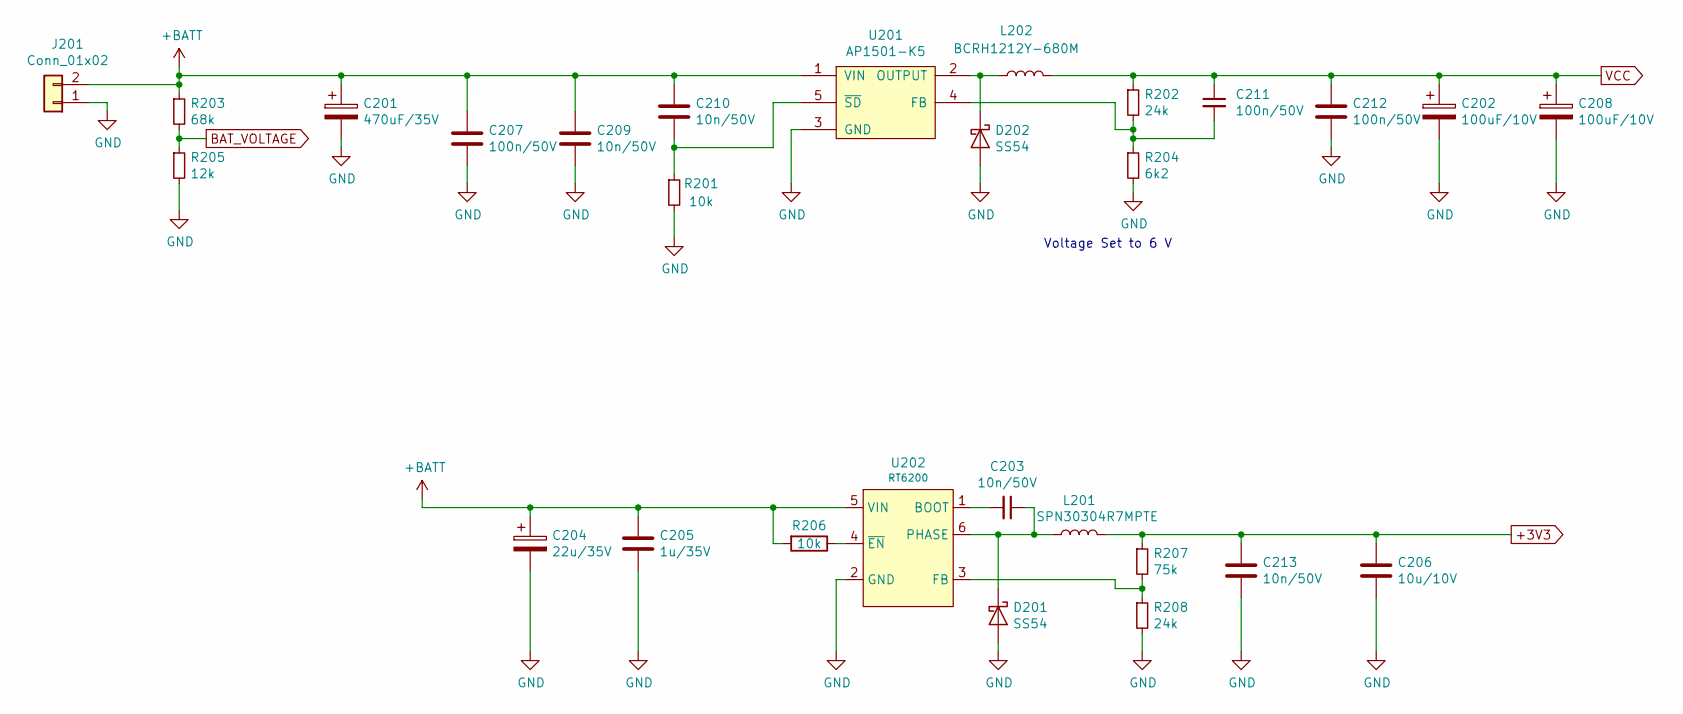
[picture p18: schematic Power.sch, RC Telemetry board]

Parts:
C201: 470uF/35V; CP_Radial_D10.0mm_P5.00mm
C202, C208: 100uF/10V; C_Radial_D7.5_L11.2_P2.5
C203, C213: 10n/50V; C_0603_1608Metric_Pad1.05x0.95mm_HandSolder
C204: 22u/35V; C_Radial_D7.5_L11.2_P2.5
C205: 1u/35V; C_0805_2012Metric_Pad1.15x1.40mm_HandSolder
C206: 10u/10V; C_0805_2012Metric_Pad1.15x1.40mm_HandSolder
C207, C211, C212: 100n/50V; C_0805_2012Metric_Pad1.15x1.40mm_HandSolder
C209, C210: 10n/50V; C_0805_2012Metric_Pad1.15x1.40mm_HandSolder
D201, D202: SS54; D_SMA_Handsoldering; MPN SS54
J201: Conn_01x02; 2Pin_4mm
L201: SPN30304R7MPTE; L_Sunlord_MWSA0402; MPN MWSA0402-4R7MT; LCSC Part-number C359291
L202: BCRH1212Y-680M; L_Sunlord_MWSA1206; MPN MWSA1206-470MT; LCSC Part-number C238002
R201, R206: 10k; R_0603_1608Metric_Pad1.05x0.95mm_HandSolder
R202, R208: 24k; R_0603_1608Metric_Pad1.05x0.95mm_HandSolder
R203: 68k; R_0603_1608Metric_Pad1.05x0.95mm_HandSolder
R204: 6k2; R_0603_1608Metric_Pad1.05x0.95mm_HandSolder
R205: 12k; R_0603_1608Metric_Pad1.05x0.95mm_HandSolder
R207: 75k; R_0603_1608Metric_Pad1.05x0.95mm_HandSolder
U201: AP1501-K5; TO-263-5_TabPin3; MPN AP1501-K5
U202: RT6200; SOT-23-6_Handsoldering; MPN RT6200

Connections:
+3V3: C206.1, C213.1, L201.2, R207.1; also elsewhere on the board
+BATT: C201.1, C204.1, C205.1, C207.1, C209.1, C210.1, J201.2, R203.1, R206.2, U201.1 (VIN), U202.5 (VIN); also elsewhere on the board
BAT_VOLTAGE: R203.2, R205.1; also elsewhere on the board
GND: C201.2, C202.2, C204.2, C205.2, C206.2, C207.2, C208.2, C209.2, C212.2, C213.2, D201.2 (A), D202.2 (A), J201.1, R201.2, R204.2, R205.2, R208.2, U201.3 (GND), U202.2 (GND); also elsewhere on the board
unnamed: C203.1, D201.1 (K), L201.1, U202.6 (PHASE)
unnamed: C203.2, U202.1 (BOOT)
unnamed: C210.2, R201.1, U201.5 (~SD)
unnamed: C211.2, R202.2, R204.1, U201.4 (FB)
unnamed: D202.1 (K), L202.1, U201.2 (OUTPUT)
unnamed: R206.1, U202.4 (~EN)
unnamed: R207.2, R208.1, U202.3 (FB)
VCC: C202.1, C208.1, C211.1, C212.1, L202.2, R202.1; also elsewhere on the board

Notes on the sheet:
Voltage Set to 6 V

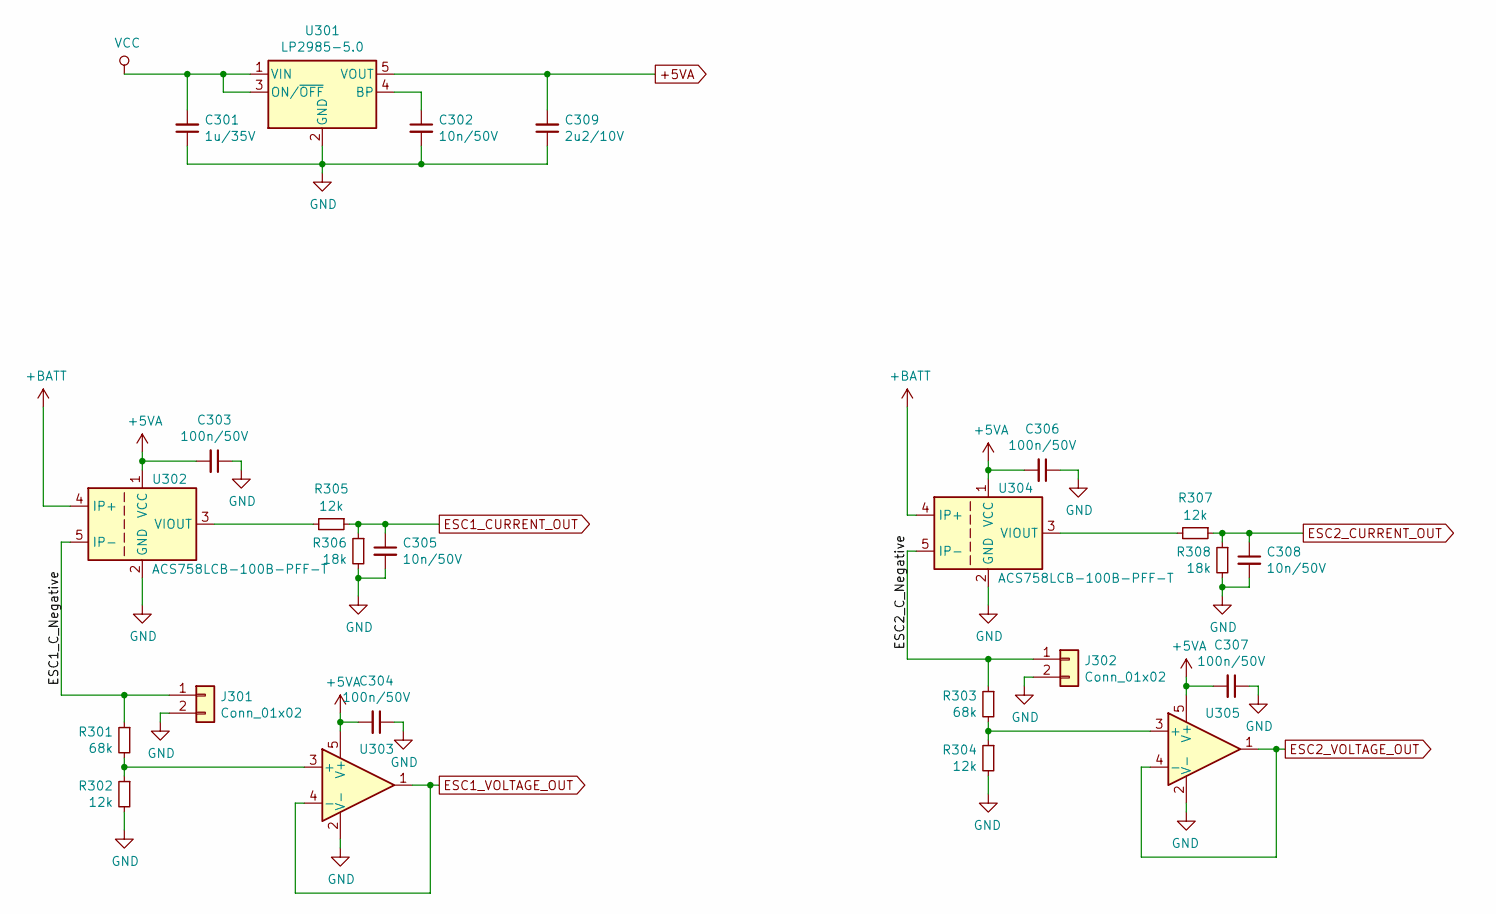
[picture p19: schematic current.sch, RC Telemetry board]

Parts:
C301: 1u/35V; C_0603_1608Metric_Pad1.05x0.95mm_HandSolder
C302, C305, C308: 10n/50V; C_0603_1608Metric_Pad1.05x0.95mm_HandSolder
C303, C304, C306, C307: 100n/50V; C_0603_1608Metric_Pad1.05x0.95mm_HandSolder
C309: 2u2/10V; C_0805_2012Metric_Pad1.15x1.40mm_HandSolder
J301, J302: Conn_01x02; 2Pin_4mm
R301, R303: 68k; R_0603_1608Metric_Pad1.05x0.95mm_HandSolder
R302, R304, R305, R307: 12k; R_0603_1608Metric_Pad1.05x0.95mm_HandSolder
R306, R308: 18k; R_0603_1608Metric_Pad1.05x0.95mm_HandSolder
U301: LP2985-5.0; SOT-23-5_HandSoldering; MPN LP2985-5.0
U302, U304: ACS758LCB-100B-PFF-T; Allegro_CB_PFF; MPN ACS758LCB-100B-PFF-T
U303, U305: MCP6001-OT; SOT-23-5_HandSoldering; MPN MCP6001-OT

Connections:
+5VA: C303.2, C304.2, C306.2, C307.2, C309.2, U301.5 (VOUT), U302.1 (VCC), U303.5 (V+), U304.1 (VCC), U305.5 (V+); also elsewhere on the board
+BATT: U302.4 (IP+), U304.4 (IP+); also elsewhere on the board
/Current measurement/ESC1_C_Negative: J301.1, R301.1, U302.5 (IP-)
/Current measurement/ESC2_C_Negative: J302.1, R303.1, U304.5 (IP-)
ESC1_CURRENT_OUT: C305.1, R305.1, R306.1; also elsewhere on the board
ESC1_VOLTAGE_OUT: U303.1, U303.4 (-); also elsewhere on the board
ESC2_CURRENT_OUT: C308.1, R307.1, R308.1; also elsewhere on the board
ESC2_VOLTAGE_OUT: U305.1, U305.4 (-); also elsewhere on the board
GND: C301.1, C302.2, C303.1, C304.1, C305.2, C306.1, C307.1, C308.2, C309.1, J301.2, J302.2, R302.2, R304.2, R306.2, R308.2, U301.2 (GND), U302.2 (GND), U303.2 (V-), U304.2 (GND), U305.2 (V-); also elsewhere on the board
unnamed: C302.1, U301.4 (BP)
unnamed: R301.2, R302.1, U303.3 (+)
unnamed: R303.2, R304.1, U305.3 (+)
unnamed: R305.2, U302.3 (VIOUT)
unnamed: R307.2, U304.3 (VIOUT)
VCC: C301.2, U301.1 (VIN), U301.3 (ON/~OFF~); also elsewhere on the board

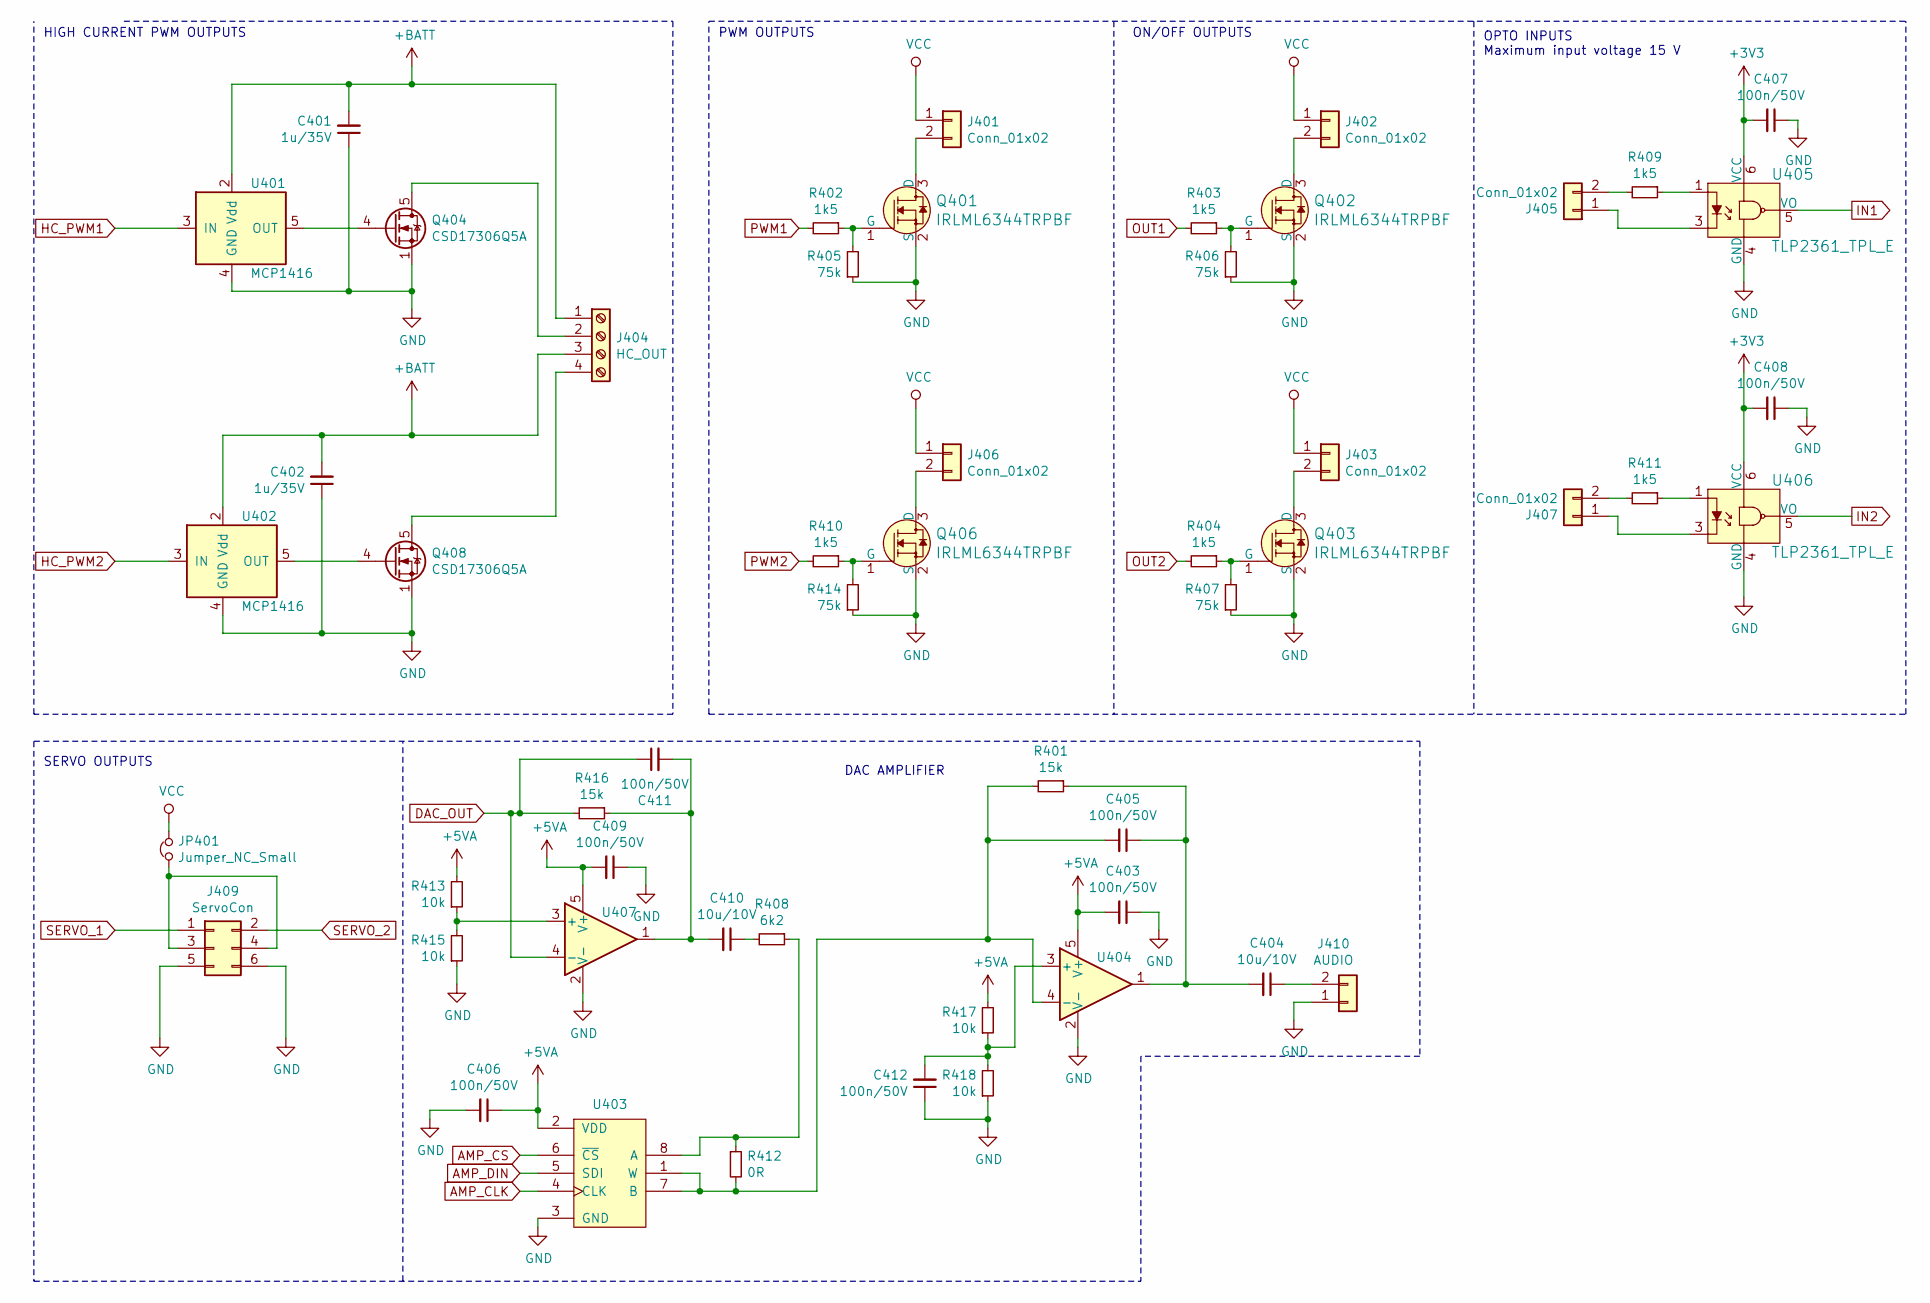
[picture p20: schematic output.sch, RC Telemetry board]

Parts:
C401, C402: 1u/35V; C_0805_2012Metric_Pad1.15x1.40mm_HandSolder
C403, C405, C406, C407, C408, C409, C411, C412: 100n/50V; C_0603_1608Metric_Pad1.05x0.95mm_HandSolder
C404, C410: 10u/10V; C_0603_1608Metric_Pad1.05x0.95mm_HandSolder
J401, J402, J403, J405, J406, J407: Conn_01x02; Molex_KK-254_AE-6410-02A_1x02_P2.54mm_Vertical
J404: HC_OUT; TerminalBlock_Phoenix_PT-1,5-4-5.0-H_1x04_P5.00mm_Horizontal
J409: ServoCon; PinHeader_2x03_P2.54mm_Vertical
J410: AUDIO; PinHeader_1x02_P2.54mm_Vertical
JP401: Jumper_NC_Small; PinHeader_1x02_P1.27mm_Vertical
Q401, Q402, Q403, Q406: IRLML6344TRPBF; SOT-23-3; MPN IRLML6344TRPBF; Digi-Key_PN IRLML6344TRPBFCT-ND
Q404, Q408: CSD17306Q5A; TDSON-8-1_HandSoldering; MPN CSD17306Q5A
R401, R416: 15k; R_0603_1608Metric_Pad1.05x0.95mm_HandSolder
R402, R403, R404, R409, R410, R411: 1k5; R_0603_1608Metric_Pad1.05x0.95mm_HandSolder
R405, R406, R407, R414: 75k; R_0603_1608Metric_Pad1.05x0.95mm_HandSolder
R408: 6k2; R_0603_1608Metric_Pad1.05x0.95mm_HandSolder
R412: 0R; R_0402_NoSilk
R413, R415, R417, R418: 10k; R_0603_1608Metric_Pad1.05x0.95mm_HandSolder
U401, U402: MCP1416; SOT-23-5_HandSoldering; MPN MCP1416
U403: AD5160BRJZ10-R2; SOT-23-8; MPN Analog Devices
U404, U407: MCP6001-OT; SOT-23-5_HandSoldering; MPN MCP6001-OT
U405, U406: TLP2361_TPL_E; SOIC-6-5_W4.55mm; MPN TLP2361-TPLECT; Digi-Key_PN TLP2361(TPLECT-ND

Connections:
+3V3: C407.2, C408.2, U405.6 (VCC), U406.6 (VCC); also elsewhere on the board
+5VA: C403.2, C406.1, C409.2, R413.2, R417.2, U403.2 (VDD), U404.5 (V+), U407.5 (V+); also elsewhere on the board
+BATT: C401.2, C402.2, J404.1, J404.3, U401.2 (Vdd), U402.2 (Vdd); also elsewhere on the board
AMP_CLK: U403.4 (CLK); also elsewhere on the board
AMP_CS: U403.6 (~CS); also elsewhere on the board
AMP_DIN: U403.5 (SDI); also elsewhere on the board
DAC_OUT: C411.1, R416.2, U407.4 (-); also elsewhere on the board
GND: C401.1, C402.1, C403.1, C406.2, C407.1, C408.1, C409.1, C412.1, J409.5, J409.6, J410.1, Q401.2 (S), Q402.2 (S), Q403.2 (S), Q404.1 (S), Q404.2 (S), Q404.3 (S), Q406.2 (S), Q408.1 (S), Q408.2 (S), Q408.3 (S), R405.1, R406.1, R407.1, R414.1, R415.1, R418.1, U401.4 (GND), U402.4 (GND), U403.3 (GND), U404.2 (V-), U405.4 (GND), U406.4 (GND), U407.2 (V-); also elsewhere on the board
HC_PWM1: U401.3 (IN); also elsewhere on the board
HC_PWM2: U402.3 (IN); also elsewhere on the board
IN1: U405.5 (VO); also elsewhere on the board
IN2: U406.5 (VO); also elsewhere on the board
unnamed: C404.1, J410.2
unnamed: C404.2, C405.1, R401.1, U404.1
unnamed: C405.2, R401.2, R412.2, U403.1 (W), U403.7 (B), U404.4 (-)
unnamed: C410.1, R408.2
unnamed: C410.2, C411.2, R416.1, U407.1
unnamed: C412.2, R417.1, R418.2, U404.3 (+)
unnamed: J401.2, Q401.3 (D)
unnamed: J402.2, Q402.3 (D)
unnamed: J403.2, Q403.3 (D)
unnamed: J404.2, Q404.5 (D)
unnamed: J404.4, Q408.5 (D)
unnamed: J405.1, U405.3
unnamed: J405.2, R409.2
unnamed: J406.2, Q406.3 (D)
unnamed: J407.1, U406.3
unnamed: J407.2, R411.2
unnamed: J409.3, J409.4, JP401.1
unnamed: Q401.1 (G), R402.1, R405.2
unnamed: Q402.1 (G), R403.1, R406.2
unnamed: Q403.1 (G), R404.1, R407.2
unnamed: Q404.4 (G), U401.5 (OUT)
unnamed: Q406.1 (G), R410.1, R414.2
unnamed: Q408.4 (G), U402.5 (OUT)
unnamed: R408.1, R412.1, U403.8 (A)
unnamed: R409.1, U405.1
unnamed: R411.1, U406.1
unnamed: R413.1, R415.2, U407.3 (+)
OUT1: R403.2; also elsewhere on the board
OUT2: R404.2; also elsewhere on the board
PWM1: R402.2; also elsewhere on the board
PWM2: R410.2; also elsewhere on the board
SERVO_1: J409.1; also elsewhere on the board
SERVO_2: J409.2; also elsewhere on the board
VCC: J401.1, J402.1, J403.1, J406.1, JP401.2; also elsewhere on the board

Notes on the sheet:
DAC AMPLIFIER
HIGH CURRENT PWM OUTPUTS
PWM OUTPUTS
ON/OFF OUTPUTS
SERVO OUTPUTS
OPTO INPUTS Maximum input voltage 15 V

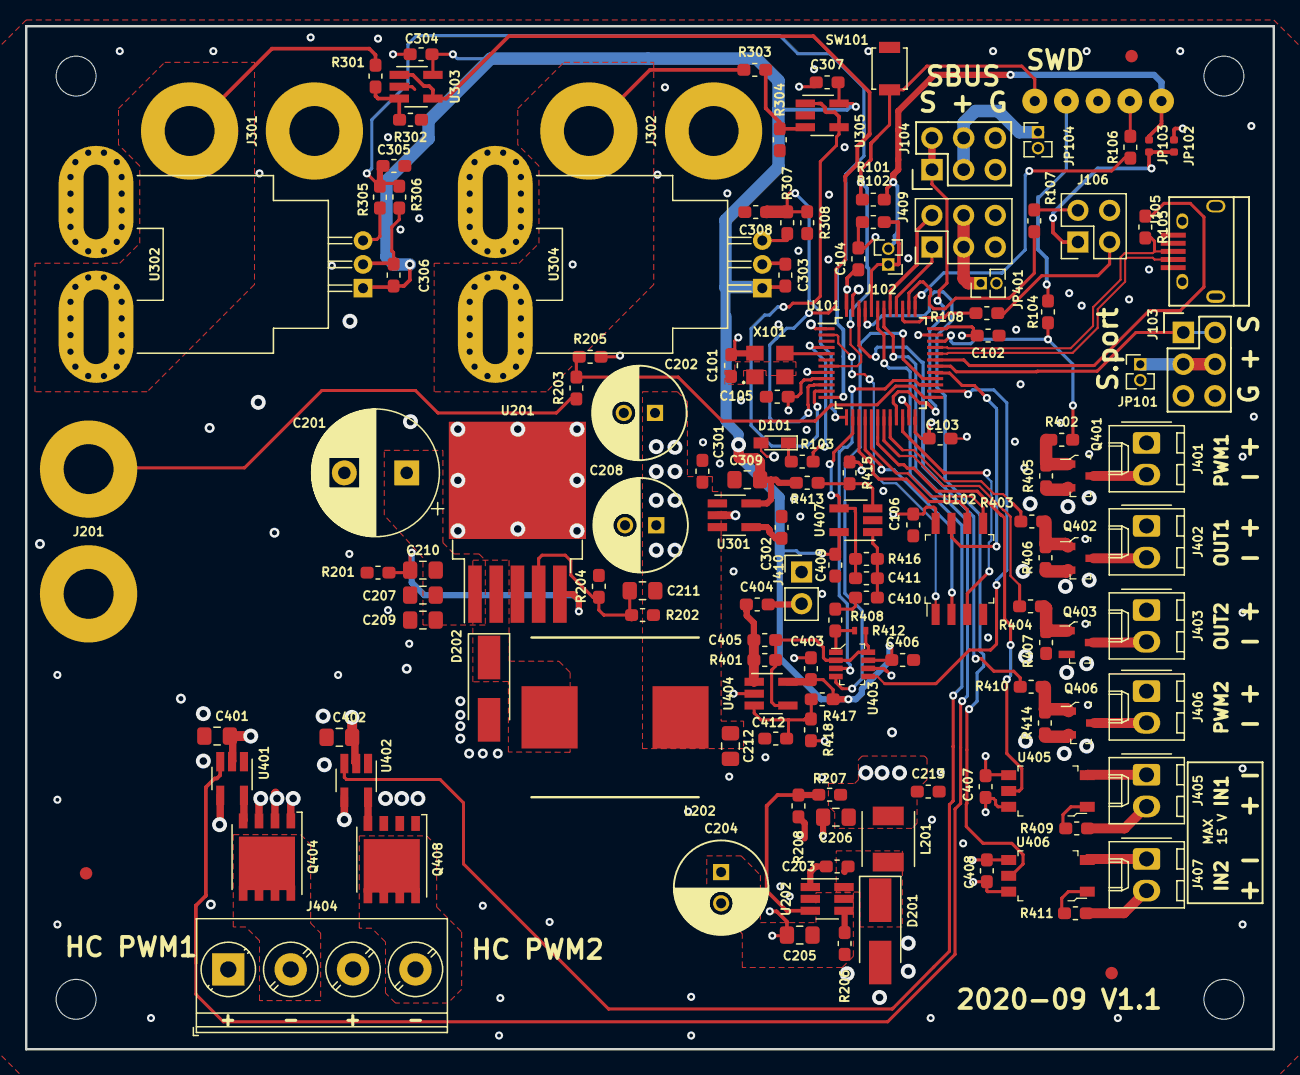
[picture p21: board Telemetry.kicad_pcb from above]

Board: 4 copper layers, 100.0 x 82.0 mm, 146 parts (1 on the bottom side), 91 nets.

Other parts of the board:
https://github.com/findersee/rctelemetry: rctelemetry_QR

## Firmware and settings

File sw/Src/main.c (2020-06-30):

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

/* Includes ------------------------------------------------------------------*/
#include "main.h"
#include "cmsis_os.h"

/* USER CODE BEGIN Includes */
#include <string.h>
#include <stdlib.h>
/* USER CODE END Includes */

/* USER CODE BEGIN PTD */
typedef struct
{
	char ID;
}telemetryMessage;
typedef struct
{
	float ESC1_powerValue;
	float ESC1_voltageValue;
	float ESC1_currentValue;
	float ESC2_powerValue;
	float ESC2_voltageValue;
	float ESC2_currentValue;
}powerMessage;
typedef struct
{
	uint16_t value;
}BatteryMessage;
/* USER CODE END PTD */

ADC_HandleTypeDef hadc1;
ADC_HandleTypeDef hadc4;
DMA_HandleTypeDef hdma_adc1;
DMA_HandleTypeDef hdma_adc4;

CRC_HandleTypeDef hcrc;

DAC_HandleTypeDef hdac;
DMA_HandleTypeDef hdma_dac_ch1;

SPI_HandleTypeDef hspi1;
SPI_HandleTypeDef hspi2;

TIM_HandleTypeDef htim1;
TIM_HandleTypeDef htim2;
TIM_HandleTypeDef htim3;
TIM_HandleTypeDef htim4;
TIM_HandleTypeDef htim6;
TIM_HandleTypeDef htim15;
TIM_HandleTypeDef htim16;
TIM_HandleTypeDef htim17;

UART_HandleTypeDef huart1;
UART_HandleTypeDef huart2;
UART_HandleTypeDef huart3;
DMA_HandleTypeDef hdma_usart1_rx;
DMA_HandleTypeDef hdma_usart1_tx;
DMA_HandleTypeDef hdma_usart2_rx;
DMA_HandleTypeDef hdma_usart3_rx;

osThreadId defaultTaskHandle;
osThreadId SendTelemetryHandle;
osThreadId PowerParserHandle;
osThreadId BattVoltageHandle;
osThreadId SbusDecoderHandle;
osMessageQId telemetryRequestQueueHandle;
osMutexId SportMessageHandle;
/* USER CODE BEGIN PV */
uartDriver SportUart;
UartTxData SportTXBuffer[3];
uint8_t SportRXBuffer[2];

uartDriver SbusUart;
//UartTxData SbusTXBuffer[3];
uint8_t SbusRXBuffer[25];

SemaphoreHandle_t powerMutex;
QueueHandle_t telemetryQueue;
QueueHandle_t powerQueue;

QueueHandle_t battQueue;

/* USER CODE END PV */

void SystemClock_Config(void);
static void MX_GPIO_Init(void);
static void MX_DMA_Init(void);
static void MX_ADC1_Init(void);
static void MX_CRC_Init(void);
static void MX_TIM2_Init(void);
static void MX_USART1_UART_Init(void);
static void MX_SPI1_Init(void);
static void MX_TIM3_Init(void);
static void MX_TIM4_Init(void);
static void MX_ADC4_Init(void);
static void MX_DAC_Init(void);
static void MX_TIM1_Init(void);
static void MX_TIM15_Init(void);
static void MX_USART3_UART_Init(void);
static void MX_TIM6_Init(void);
static void MX_TIM16_Init(void);
static void MX_SPI2_Init(void);
static void MX_TIM17_Init(void);
static void MX_USART2_UART_Init(void);
void StartDefaultTask(void const * argument);
void StartSendTelemetry(void const * argument);
void StartPower(void const * argument);
void StartBattVoltage(void const * argument);
void StartSbusDecoder(void const * argument);

/* USER CODE BEGIN PFP */
//extern uint8_t CDC_Transmit_FS(uint8_t* Buf, uint16_t Len);
uint8_t CRCCalc( uint8_t * packet);
HAL_StatusTypeDef SET_PWM_VALUE(uint16_t value,uint32_t channel, TIM_HandleTypeDef *htim);
/* USER CODE END PFP */

/* USER CODE BEGIN 0 */
void HardFault_Handler(void){
	HAL_GPIO_WritePin(ERROR_LED_GPIO_Port, ERROR_LED_Pin, GPIO_PIN_RESET);
	while(1){
	asm("nop");
	}
}

void BusFault_Handler(void){
	HAL_GPIO_WritePin(ERROR_LED_GPIO_Port, ERROR_LED_Pin, GPIO_PIN_RESET);
	while(1){
	HAL_GPIO_WritePin(ERROR_LED_GPIO_Port, ERROR_LED_Pin, GPIO_PIN_RESET);
	}
}


void HAL_UART_ErrorCallback(UART_HandleTypeDef *huart){


	asm("nop");
}

void HAL_UART_TxCpltCallback(UART_HandleTypeDef *huart){
	asm("nop");

	if(huart->Instance == USART1){
		osSignalSet(SendTelemetryHandle, 0x0002);
	}
}
void HAL_UART_RxCpltCallback(UART_HandleTypeDef *huart){
	asm("nop");

	if(huart->Instance == USART1){
		osSignalSet(SendTelemetryHandle, 0x0001);
	}
	if(huart->Instance == USART3){
		osSignalSet(SbusDecoderHandle, 0x0001);
	}
}

/* USER CODE END 0 */

/**
  * @brief  The application entry point.
  * @retval int
  */
int main(void)
{
  

  /* MCU Configuration--------------------------------------------------------*/

  /* Reset of all peripherals, Initializes the Flash interface and the Systick. */
  HAL_Init();

  /* Configure the system clock */
  SystemClock_Config();

  /* Initialize all configured peripherals */
  MX_GPIO_Init();
  MX_DMA_Init();
  MX_ADC1_Init();
  MX_CRC_Init();
  MX_TIM2_Init();
  MX_USART1_UART_Init();
  MX_SPI1_Init();
  MX_TIM3_Init();
  MX_TIM4_Init();
  MX_ADC4_Init();
  MX_DAC_Init();
  MX_TIM1_Init();
  MX_TIM15_Init();
  MX_USART3_UART_Init();
  MX_TIM6_Init();
  MX_TIM16_Init();
  MX_SPI2_Init();
  MX_TIM17_Init();
  MX_USART2_UART_Init();
  /* USER CODE BEGIN 2 */
  SportUart = uartDriverInit(SportTXBuffer,3,SportRXBuffer,sizeof(SportRXBuffer),&huart1,RXTX);
  SbusUart = uartDriverInit(NULL,0,SbusRXBuffer,25,&huart3,RX);
  //HAL_UART_Receive_IT(&huart1, SportRXBuffer, 4);
  //HAL_UART_Receive_DMA(&huart1, SportRXBuffer, 2);

  /* USER CODE END 2 */

  /* Create the mutex(es) */
  /* definition and creation of SportMessage */
  osMutexDef(SportMessage);
  SportMessageHandle = osMutexCreate(osMutex(SportMessage));

  /* USER CODE BEGIN RTOS_MUTEX */
  /* add mutexes, ... */
  powerMutex = xSemaphoreCreateMutex();
  /* USER CODE END RTOS_MUTEX */

  /* USER CODE BEGIN RTOS_SEMAPHORES */
  /* add semaphores, ... */
  /* USER CODE END RTOS_SEMAPHORES */

  /* USER CODE BEGIN RTOS_TIMERS */
  /* start timers, add new ones, ... */
  /* USER CODE END RTOS_TIMERS */

  /* Create the queue(s) */
  /* definition and creation of telemetryRequestQueue */
  osMessageQDef(telemetryRequestQueue, 6, telemetryMessage);
  telemetryRequestQueueHandle = osMessageCreate(osMessageQ(telemetryRequestQueue), NULL);

  /* USER CODE BEGIN RTOS_QUEUES */
  /* add queues, ... */
  /* USER CODE END RTOS_QUEUES */

  /* Create the thread(s) */
  /* definition and creation of defaultTask */
  osThreadDef(defaultTask, StartDefaultTask, osPriorityIdle, 0, 128);
  defaultTaskHandle = osThreadCreate(osThread(defaultTask), NULL);

  /* definition and creation of SendTelemetry */
  osThreadDef(SendTelemetry, StartSendTelemetry, osPriorityRealtime, 0, 256);
  SendTelemetryHandle = osThreadCreate(osThread(SendTelemetry), NULL);

  /* definition and creation of PowerParser */
  osThreadDef(PowerParser, StartPower, osPriorityNormal, 0, 192);
  PowerParserHandle = osThreadCreate(osThread(PowerParser), NULL);

  /* definition and creation of BattVoltage */
  osThreadDef(BattVoltage, StartBattVoltage, osPriorityNormal, 0, 128);
  BattVoltageHandle = osThreadCreate(osThread(BattVoltage), NULL);

  /* definition and creation of SbusDecoder */
  osThreadDef(SbusDecoder, StartSbusDecoder, osPriorityNormal, 0, 192);
  SbusDecoderHandle = osThreadCreate(osThread(SbusDecoder), NULL);

  /* USER CODE BEGIN RTOS_THREADS */
  //osThreadTerminate(SbusDecoderHandle);
  /* add threads, ... */
  /* USER CODE END RTOS_THREADS */

  /* Start scheduler */
  osKernelStart();
  
  /* We should never get here as control is now taken by the scheduler */

  /* Infinite loop */
  /* USER CODE BEGIN WHILE */
  while (1)
  {
    /* USER CODE END WHILE */

    /* USER CODE BEGIN 3 */
  }
  /* USER CODE END 3 */
}

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
/* USER CODE BEGIN 4 */
#define ADC_samples 8

//Power ADC size definitions
#define powerChannels 5
#define powerBufferSize (ADC_samples*powerChannels)

//ADC Scaling definitions
#define currentScaling 0.6f
#define voltageScaling 0.15f
//#define ADC_step (3.3f/4095)
#define ADC_Bits 12
float ADC_step = (3.3f/(2^ADC_Bits));



#define VREFINT_CAL_ADDR    0x1FFFF7BA


uint16_t DAC_BUFFER[30];
uint16_t power_ADC_Buffer[powerBufferSize];
uint16_t temp_ADC_Buffer[ADC_samples];
uint16_t batVolt_ADC_Buffer[ADC_samples];

osPoolId teleRxpool;
osPoolDef(teleRxpool,6,telemetryMessage);

uint8_t CRCCalc (uint8_t *packet) {
    short crc = 0;
    for (int i=0; i<7; i++) {
        crc += packet[i]; //0-1FF
        crc += crc >> 8;  //0-100
        crc &= 0x00ff;
        crc += crc >> 8;  //0-0FF
        crc &= 0x00ff;
    }
    return ~crc;
}

HAL_StatusTypeDef SET_PWM_VALUE(uint16_t value,uint32_t channel, TIM_HandleTypeDef *htim)
{
	if(htim == NULL)
		return HAL_ERROR;
    TIM_OC_InitTypeDef sConfigOC;

    sConfigOC.OCMode = TIM_OCMODE_PWM1;
    sConfigOC.Pulse = value;
    sConfigOC.OCPolarity = TIM_OCPOLARITY_HIGH;
    sConfigOC.OCFastMode = TIM_OCFAST_DISABLE;
    HAL_TIM_PWM_ConfigChannel(htim, &sConfigOC, channel);
    HAL_TIM_PWM_Start(htim, channel);

    return HAL_OK;
}



/* USER CODE END 4 */

/* USER CODE BEGIN Header_StartDefaultTask */
/**
  * @brief  Function implementing the defaultTask thread.
  * @param  argument: Not used 
  * @retval None
  */
/* USER CODE END Header_StartDefaultTask */
void StartDefaultTask(void const * argument)
{
  /* USER CODE BEGIN 5 */
  HAL_GPIO_WritePin(ERROR_LED_GPIO_Port, ERROR_LED_Pin, GPIO_PIN_SET);
  //uint8_t startMsg[] = "bootrom\n";
  HAL_NVIC_DisableIRQ(DMA1_Channel1_IRQn); //Disable interrupt because the Cube won't let us and we don't need it
  HAL_ADC_Start_DMA(&hadc1, (uint32_t *)power_ADC_Buffer , powerBufferSize); // Start ESC voltage and current measurement ADC
  HAL_NVIC_DisableIRQ(DMA2_Channel2_IRQn); //Disable interrupt because the Cube won't let us and we don't need it
  HAL_ADC_Start_DMA(&hadc4, (uint32_t *)batVolt_ADC_Buffer, ADC_samples); // Start battery voltage measurement ADC
  //HAL_GPIO_WritePin(HC_OUTPUT_GPIO_Port, HC_OUTPUT_Pin, GPIO_PIN_RESET);
  if(SET_PWM_VALUE(0, TIM_CHANNEL_1, &htim4) != HAL_OK)
	  Error_Handler();
  if(SET_PWM_VALUE(0, TIM_CHANNEL_2, &htim4) != HAL_OK)
	  Error_Handler();

  //CDC_Transmit_FS(startMsg, sizeof(startMsg));
  /* Infinite loop */
  //uint8_t Msg[] = "Power";
  for(;;)
  {
	HAL_GPIO_TogglePin(ERROR_LED_GPIO_Port, ERROR_LED_Pin);
    osDelay(50);
    //uartDriverLoadData(Msg, 3, &SportUart);
    //HAL_UART_Transmit_DMA(&huart1, Msg, 3);
    //osDelay(1900);
  }
  /* USER CODE END 5 */ 
}

/* USER CODE BEGIN Header_StartSendTelemetry */
/**
* @brief Function implementing the SendTelemetry thread.
* @param argument: Not used
* @retval None
*/
/* USER CODE END Header_StartSendTelemetry */
void StartSendTelemetry(void const * argument)
{
  /* USER CODE BEGIN StartSendTelemetry */

powerMessage *powerPtr;
powerMessage powerDataScaled = {.ESC1_currentValue = 0, .ESC1_powerValue = 0, .ESC1_voltageValue=0, \
		.ESC2_currentValue = 0, .ESC2_powerValue = 0,.ESC2_voltageValue= 0};
BatteryMessage *battPtr;
BatteryMessage BattVoltage = {.value = 0};

uint8_t sensorBuffer[8];
uint8_t mBuffer[4];
const uint8_t packetType = 0x10;

#define Esc1Data 0x01
#define Esc2Data 0x10
#define battData 0x02
#define  IN1_data 0x04
#define  IN2_data 0x08

uint8_t IN1_prev = GPIO_PIN_RESET;
uint8_t IN2_prev = GPIO_PIN_RESET;

uint8_t IN1_cnt = 0;
uint8_t IN2_cnt = 0;

uint8_t NewData = 0;
  /* Infinite loop */
  for(;;)
  {

	if(powerQueue != 0){
		if(xQueueReceive(powerQueue, &(powerPtr), (TickType_t)0) == pdTRUE){
			powerDataScaled.ESC1_currentValue = (powerPtr->ESC1_currentValue)*100;
			powerDataScaled.ESC1_powerValue = (powerPtr->ESC1_powerValue)*10;
			powerDataScaled.ESC1_voltageValue = (powerPtr->ESC1_voltageValue)*100;

			powerDataScaled.ESC2_currentValue = (powerPtr->ESC2_currentValue)*100;
			powerDataScaled.ESC2_powerValue = (powerPtr->ESC2_powerValue)*10;
			powerDataScaled.ESC2_voltageValue = (powerPtr->ESC2_voltageValue)*100;
			NewData |= Esc1Data;
			NewData |= Esc2Data;
		}
	}

	if(battQueue != 0){
		if(xQueueReceive(battQueue, &(battPtr), (TickType_t)0) == pdTRUE){
			BattVoltage.value = battPtr->value;
			NewData |= battData;
		}
	}

	if((IN1_prev != HAL_GPIO_ReadPin(IN1_GPIO_Port, IN1_Pin)) || (IN1_cnt >= 90)){
		IN1_prev = HAL_GPIO_ReadPin(IN1_GPIO_Port, IN1_Pin);
		NewData |= IN1_data;
		IN1_cnt = 0;
	}

	if((IN2_prev != HAL_GPIO_ReadPin(IN2_GPIO_Port, IN2_Pin))  || (IN2_cnt >= 90)){
		IN2_prev = HAL_GPIO_ReadPin(IN2_GPIO_Port, IN2_Pin);
		NewData |= IN2_data;
		IN2_cnt = 0;
	}
	IN1_cnt ++;
	IN2_cnt ++;

	osEvent signalEvent = osSignalWait(0x0001, osWaitForever);
	if(signalEvent.status == osEventSignal)
	{

		asm("nop");

		unsigned ID = 0;
		unsigned bytes = uartDriverSpace(&SportUart);

		if(bytes > 1){
			uartDriverReadData(&mBuffer, bytes, &SportUart);

			for(unsigned cnt=0;cnt<bytes;cnt++){
				ID = 0;
				if((mBuffer[cnt] == 0x7E) && ( cnt < (bytes+1)) && (mBuffer[cnt+1] != 0x00)){
					cnt++;
					ID = mBuffer[cnt];
					uint32_t dataTmp = 0;
					memset(&sensorBuffer,0,8);
					switch(ID)
					{
						case SPORT_ID3:
							//Send ESC 1 power data
							if((NewData & Esc1Data) == Esc1Data){
							sensorBuffer[0] = packetType;
							dataTmp = (uint16_t)powerDataScaled.ESC1_voltageValue;
							//dataTmp = 0xDEADBEEF;
							sensorBuffer[1] = (uint8_t)(ESC_POWER_FIRST_ID);
							sensorBuffer[2] = (uint8_t)(ESC_POWER_FIRST_ID >> 8);
							NewData &= ~Esc1Data;

							sensorBuffer[3] = (uint8_t)dataTmp;
							sensorBuffer[4] = (uint8_t)(dataTmp>>8);
							dataTmp = (uint16_t)powerDataScaled.ESC1_currentValue;
							sensorBuffer[5] = (uint8_t)(dataTmp);
							sensorBuffer[6] = (uint8_t)(dataTmp>>8);
							}
							sensorBuffer[7] = CRCCalc((uint8_t *)sensorBuffer);

							uartDriverLoadData(sensorBuffer, sizeof(sensorBuffer), &SportUart);
							osDelay(1);
							break;

						case SPORT_ID4:
							//Send ESC 2 power data
							if((NewData & Esc2Data) == Esc2Data){
							sensorBuffer[0] = packetType;
							dataTmp = (uint32_t)powerDataScaled.ESC2_voltageValue;
							sensorBuffer[1] = (uint8_t)(ESC_POWER_FIRST_ID+1);
							sensorBuffer[2] = (uint8_t)((ESC_POWER_FIRST_ID+1) >> 8);
							NewData &= ~Esc2Data;

							sensorBuffer[3] = (uint8_t)dataTmp;
							sensorBuffer[4] = (uint8_t)(dataTmp>>8);
							dataTmp = (uint16_t)powerDataScaled.ESC2_currentValue;
							sensorBuffer[5] = (uint8_t)(dataTmp);
							sensorBuffer[6] = (uint8_t)(dataTmp>>8);
							}
							sensorBuffer[7] = CRCCalc((uint8_t *)sensorBuffer);

							uartDriverLoadData(sensorBuffer, sizeof(sensorBuffer), &SportUart);
							osDelay(1);
							break;

						case SPORT_ID10:
							if((NewData & battData) == battData){
							sensorBuffer[0] = packetType;
							dataTmp = (uint32_t)BattVoltage.value;
							sensorBuffer[1] = (uint8_t)(A3_FIRST_ID);
							sensorBuffer[2] = (uint8_t)(A3_FIRST_ID>>8);
							NewData &= ~battData;
							}
							sensorBuffer[3] = (uint8_t)dataTmp;
							sensorBuffer[4] = (uint8_t)(dataTmp>>8);
							sensorBuffer[5] = (uint8_t)(dataTmp>>16);
							sensorBuffer[6] = (uint8_t)(dataTmp>>24);

							sensorBuffer[7] = CRCCalc((uint8_t *)sensorBuffer);

							uartDriverLoadData(sensorBuffer, sizeof(sensorBuffer), &SportUart);
							osDelay(1);
							break;

						case SPORT_ID12:

							if((NewData & IN1_data) == IN1_data){
								sensorBuffer[0] = packetType;
								sensorBuffer[1] = (uint8_t)(ADC1_ID);
								sensorBuffer[2] = (uint8_t)(ADC1_ID>>8);

								if(IN1_prev == GPIO_PIN_RESET)
									sensorBuffer[3] = 50;
								else{
									sensorBuffer[3] = 0xE8;
									sensorBuffer[4] = 0x03;
								}

								NewData &= ~IN1_data;
							}

							sensorBuffer[7] = CRCCalc((uint8_t *)sensorBuffer);

							uartDriverLoadData(sensorBuffer, sizeof(sensorBuffer), &SportUart);
							osDelay(1);
							break;

						case SPORT_ID13:

							if((NewData & IN2_data) == IN2_data){
								sensorBuffer[0] = packetType;
								sensorBuffer[1] = (uint8_t)(ADC2_ID);
								sensorBuffer[2] = (uint8_t)(ADC2_ID>>8);

								if(IN2_prev == GPIO_PIN_RESET)
									sensorBuffer[3] = 50;
								else{
									sensorBuffer[3] = 0xE8;
									sensorBuffer[4] = 0x03;
								}

								NewData &= ~IN2_data;
							}
							sensorBuffer[7] = CRCCalc((uint8_t *)sensorBuffer);

							uartDriverLoadData(sensorBuffer, sizeof(sensorBuffer), &SportUart);
							osDelay(1);
							break;

						default:
							break;
					}
					//osSignalWait(0x0002, 2);
				}
				else
					uartDriverDMASync(&SportUart);

			}
		}
	}
	//osDelay(1);
  }
  /* USER CODE END StartSendTelemetry */
}

/* USER CODE BEGIN Header_StartPower */
/**
* @brief Function implementing the PowerParser thread.
* @param argument: Not used
* @retval None
*/
/* USER CODE END Header_StartPower */
void StartPower(void const * argument)
{
  /* USER CODE BEGIN StartPower */
	  //uint8_t Msg[] = "Power\n";
	  //CDC_Transmit_FS(Msg, sizeof(Msg));
	uint16_t measurements[powerChannels];
	#define currentScaling 0.6f
	#define voltageScaling 0.15f
	//#define ADC_step (3.3f/1024)


	powerMessage power_new = {.ESC1_currentValue = 0, .ESC1_powerValue = 0, .ESC1_voltageValue=0, \
			.ESC2_currentValue = 0, .ESC2_powerValue = 0,.ESC2_voltageValue= 0};
	powerMessage *msgPtr;

	float temp = 0.0f;
	while(powerQueue == NULL){
		powerQueue = xQueueCreate(1,sizeof(powerMessage * ));
		osDelay(10);
	}
  /* Infinite loop */
  for(;;)
  {
	  //uint16_t test = sizeof(measurements);
	 memset((uint16_t*)measurements,0,sizeof(measurements));
	 /*
	 for(uint8_t s=0; s < powerChannels; s++)
	 {
		 measurements[s] = 0;
	 }
	  */
	 for(uint8_t ch=0; ch < powerChannels; ch++)
	 {
		 uint32_t loopTemp=0;
		 for(uint8_t buf=ch;buf<(powerBufferSize-ch); buf+=powerChannels)
		 {
			 loopTemp += power_ADC_Buffer[buf];
		 }
		 measurements[ch] = (loopTemp/ADC_samples);
	 }


		 temp = 0.0f;
		 //ESC1 Voltage scaled
		 temp = measurements[0]*ADC_step;
		 temp /= voltageScaling;
		 power_new.ESC1_voltageValue = temp;

		 temp = 0.0f;
		 //ESC2 Voltage scaled
		 temp = measurements[1]*ADC_step;
		 temp /= voltageScaling;
		 power_new.ESC2_voltageValue = temp;

		 temp = 0.0f;
		 //ESC1 Current scaled
		 temp = measurements[2]*ADC_step;
		 temp /= currentScaling;
		 if(temp > 0.5){
			 temp -= 0.5f; //Subtract offset value;
		 	 temp /= 0.04f; //Calculate Amps with formula 40mV/A
		 }
		 else
			 temp = 0;
		 power_new.ESC1_currentValue = temp;

		 temp = 0.0f;
		 //ESC2 Current scaled
		 temp = measurements[3]*ADC_step;
		 temp /= currentScaling;
		 if(temp > 0.5){
			 temp -= 0.5f; //Subtract offset value;
		 	 temp /= 0.04f; //Calculate Amps with formula 40mV/A
		 }
		 else
			 temp = 0;
		 power_new.ESC2_currentValue = temp;

		 temp = measurements[4];

		 //uint16_t vrefint_cal;                        // VREFINT calibration value
		 //vrefint_cal= *((uint16_t*)VREFINT_CAL_ADDR); // read VREFINT_CAL_ADDR memory location

		 if(temp != 0)
			 ADC_step = (3.3f*(*((uint16_t*)VREFINT_CAL_ADDR)/temp))/4095;



		 power_new.ESC1_powerValue = (power_new.ESC1_currentValue*power_new.ESC1_voltageValue);
		 power_new.ESC2_powerValue = (power_new.ESC2_currentValue*power_new.ESC2_voltageValue);
		 msgPtr = &power_new;

		 xQueueOverwrite(powerQueue,( void * ) &msgPtr);
		 osDelay(1000);

  }
  /* USER CODE END StartPower */
}

/* USER CODE BEGIN Header_StartBattVoltage */
/**
* @brief Function implementing the BattVoltage thread.
* @param argument: Not used
* @retval None
*/
/* USER CODE END Header_StartBattVoltage */
void StartBattVoltage(void const * argument)
{
  /* USER CODE BEGIN StartBattVoltage */
	BatteryMessage Bat = {.value = 0};
	float temp = 0.0f;
	BatteryMessage *msgPtr;
	while(battQueue == NULL){
		battQueue = xQueueCreate(1,sizeof(BatteryMessage * ));
		osDelay(10);
	}
	/* Infinite loop */
	for(;;)
	{
	  uint32_t loopTemp = 0;
	for(unsigned i=0;i<ADC_samples;i++){
		loopTemp += batVolt_ADC_Buffer[i];
	}
	temp = (loopTemp/ADC_samples);
	temp = (temp*ADC_step);
	temp /= 0.15f ;
	Bat.value = 100*temp;
	msgPtr = &Bat;

	xQueueOverwrite(battQueue,( void * ) &msgPtr);
	osDelay(1000);
	}
  /* USER CODE END StartBattVoltage */
}
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

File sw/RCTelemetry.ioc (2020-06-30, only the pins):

Mcu.UserName=STM32F303CCTx
PA0.GPIO_Label=ESC1 VOLTAGE
PA0.Signal=ADC1_IN1
PA1.GPIO_Label=ESC2 VOLTAGE
PA1.Signal=ADC1_IN2
PA10.GPIO_Label=USB_ENUMERATE
PA10.Signal=GPIO_Output
PA13.Signal=SYS_JTMS-SWDIO
PA14.Signal=SYS_JTCK-SWCLK
PA15.Signal=USART2_RX
PA2.GPIO_Label=ESC1 CURRENT
PA2.Signal=ADC1_IN3
PA3.GPIO_Label=ESC2 CURRENT
PA3.Signal=ADC1_IN4
PA4.GPIO_Label=DAC_OUT
PA4.Signal=COMP_DAC1_group
PA5.GPIO_Label=FLASH_SCK
PA5.Signal=SPI1_SCK
PA6.GPIO_Label=FLASH_MISO
PA6.Signal=SPI1_MISO
PA7.GPIO_Label=FLASH_MOSI
PA7.Signal=SPI1_MOSI
PA8.GPIO_Label=FLASH_HOLD
PA8.Signal=GPIO_Output
PA9.GPIO_Label=Sport_UART
PA9.Signal=USART1_TX
PB0.GPIO_Label=IN1
PB0.Signal=GPIO_Input
PB1.GPIO_Label=OUT2
PB1.Signal=GPIO_Output
PB10.Signal=USART3_TX
PB11.GPIO_Label=FLASH_WP
PB11.Signal=GPIO_Output
PB12.GPIO_Label=BAT VOLTAGE
PB12.Signal=ADC4_IN3
PB13.Signal=SPI2_SCK
PB14.GPIO_Label=AMP_CS
PB14.Signal=GPIO_Output
PB15.Signal=SPI2_MOSI
PB2.GPIO_Label=OUT1
PB2.Signal=GPIO_Output
PB3.Signal=USART2_TX
PB4.GPIO_Label=Servo_2
PB4.Signal=S_TIM16_CH1
PB5.GPIO_Label=Servo_1
PB5.Signal=S_TIM17_CH1
PB6.GPIO_Label=HC OUT1
PB6.Signal=S_TIM4_CH1
PB7.GPIO_Label=HC OUT2
PB7.Signal=S_TIM4_CH2
PB8.GPIO_Label=IN2
PB8.Signal=GPIO_Input
PB9.GPIO_Label=PWM2
PB9.Signal=S_TIM4_CH4
PC13.GPIO_Label=FLASH_CS
PC13.Signal=GPIO_Output
PC15-OSC32_OUT.GPIO_Label=ERROR_LED
PC15-OSC32_OUT.Signal=GPIO_Output
PF0-OSC_IN.Signal=RCC_OSC_IN

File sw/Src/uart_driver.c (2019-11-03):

/*
 * uart_driver.c
 *
 *  Created on: Jun 23, 2019
 *      Author: Finder
 */

#include "uart_driver.h"

extern uartDriver SportUart;
extern uartDriver SbusUart;
static void StartTXDMA(DMA_HandleTypeDef *hdma, uint32_t SrcAddress, uint32_t DstAddress, uint32_t DataLength);
static void UART_DMAReceiveCplt(DMA_HandleTypeDef *hdma)
{
	UART_HandleTypeDef* huart = (UART_HandleTypeDef*)(hdma->Parent);

	HAL_UART_RxCpltCallback(huart);
}

static void UART_DMATransmitCplt(DMA_HandleTypeDef *hdma)
{
	UART_HandleTypeDef* huart = (UART_HandleTypeDef*)(hdma->Parent);

	uartDriver *_driver = NULL;

	if(huart->Instance == USART1)
		_driver = &SportUart;
	else if(huart->Instance == USART2)
		_driver = &SbusUart;
	else if(huart->Instance == USART3)
		_driver = &SbusUart;

	__HAL_DMA_DISABLE(hdma);
	//__HAL_DMA_CLEAR_FLAG(hdma)

	_driver->txBufTail = (_driver->txBufTail + 1) % _driver->txBufSize;


	if(_driver->txBufHead !=_driver->txBufTail)
	{
		__HAL_UART_CLEAR_FLAG(huart,UART_FLAG_TC);

		//StartTXDMA(hdma,(uint32_t)(_driver->txBuf[_driver->txBufTail].data), (uint32_t)&(_driver->huart->Instance->TDR), (uint32_t)8);
		StartTXDMA(_driver->huart->hdmatx,(uint32_t)(_driver->txBuf[_driver->txBufTail].data), (uint32_t)&(_driver->huart->Instance->TDR), _driver->txBuf[_driver->txBufTail].size);
		SET_BIT(_driver->huart->Instance->CR3, USART_CR3_DMAT);
	}

	else if((_driver->huart->Instance->CR3 & USART_CR3_HDSEL) != 0){
		/*
		SET_BIT(_driver->huart->Instance->CR1, USART_CR1_RE);
		SET_BIT(_driver->huart->Instance->CR3, USART_CR3_DMAR);
		*/
		_driver->txActive = 0;
	}

	HAL_UART_TxCpltCallback(huart);
}


static void StartTXDMA(DMA_HandleTypeDef *hdma, uint32_t SrcAddress, uint32_t DstAddress, uint32_t DataLength)
{

  /* Check the parameters */
  assert_param(IS_DMA_BUFFER_SIZE(DataLength));

  /* Process locked */
  //__HAL_LOCK(hdma);

  if(HAL_DMA_STATE_READY == hdma->State)
  {
  	/* Change DMA peripheral state */
  	hdma->State = HAL_DMA_STATE_BUSY;

  	hdma->ErrorCode = HAL_DMA_ERROR_NONE;

  	/* Disable the peripheral */
  	hdma->Instance->CCR &= ~DMA_CCR_EN;

  	hdma->XferCpltCallback = UART_DMATransmitCplt;

  	/* Configure the source, destination address and the data length */

  	hdma->DmaBaseAddress->IFCR  = (DMA_FLAG_GL1 << hdma->ChannelIndex);

  	hdma->Instance->CNDTR = DataLength;

  	hdma->Instance->CPAR = DstAddress;

  	hdma->Instance->CMAR = SrcAddress;

  	/* Enable the transfer complete interrupt */
  	/* Half transfer interrupt is optional: enable it only if associated callback is available */
	hdma->Instance->CCR |= (DMA_IT_TC);

  	/* Enable the Peripheral */
  	//hdma->Instance->CCR |= DMA_CCR_EN;
  	__HAL_DMA_ENABLE(hdma);
  	//__HAL_UNLOCK(hdma);
  }
  else
  {
  	/* Process Unlocked */
    //__HAL_UNLOCK(hdma);

    /* Remain BUSY */
  }

}




uartDriver uartDriverInit(UartTxData * TxBuffer,unsigned TxBufferSize,uint8_t * RxBuffer,unsigned RxBufferSize,UART_HandleTypeDef *_huart,UartMode mode){
		uartDriver driver;
		driver.huart = _huart;
		driver.rxBufHead = 0;
		driver.rxBufTail = 0;
		driver.txBufHead = 0;
		driver.txBufTail = 0;
		driver.rxBuf = RxBuffer;
		driver.txBuf = TxBuffer;
		driver.rxBufSize = RxBufferSize;
		driver.txBufSize = TxBufferSize;
		driver.Mode = mode;
		driver.txActive = 0;


		if(mode != TX){
			if(_huart->Instance == USART1){

				//__HAL_LOCK(_huart);
				_huart->hdmarx->XferCpltCallback = UART_DMAReceiveCplt;
				//_huart->hdmarx->XferHalfCpltCallback = UART_DMAReceiveCplt;
				HAL_DMA_Start_IT(_huart->hdmarx, (uint32_t)&_huart->Instance->RDR, (uint32_t)driver.rxBuf, driver.rxBufSize);

				//__HAL_UNLOCK(_huart);
				SET_BIT(_huart->Instance->CR3, USART_CR3_DMAR);
				//SET_BIT(_huart->Instance->CR1, USART_CR1_RXNEIE);
				return driver;
			}
			else if(_huart->Instance == USART3){

				//__HAL_LOCK(_huart);
				_huart->hdmarx->XferCpltCallback = UART_DMAReceiveCplt;
				//_huart->hdmarx->XferHalfCpltCallback = UART_DMAReceiveCplt;
				HAL_DMA_Start_IT(_huart->hdmarx, (uint32_t)&_huart->Instance->RDR, (uint32_t)driver.rxBuf, driver.rxBufSize);

				//__HAL_UNLOCK(_huart);
				SET_BIT(_huart->Instance->CR3, USART_CR3_DMAR);
				//SET_BIT(_huart->Instance->CR1, USART_CR1_RXNEIE);
				return driver;
			}
			else if(_huart->Instance == USART2){

				//__HAL_LOCK(_huart);
				_huart->hdmarx->XferCpltCallback = UART_DMAReceiveCplt;
				//_huart->hdmarx->XferHalfCpltCallback = UART_DMAReceiveCplt;
				HAL_DMA_Start_IT(_huart->hdmarx, (uint32_t)&_huart->Instance->RDR, (uint32_t)driver.rxBuf, driver.rxBufSize);

				//__HAL_UNLOCK(_huart);
				SET_BIT(_huart->Instance->CR3, USART_CR3_DMAR);
				//SET_BIT(_huart->Instance->CR1, USART_CR1_RXNEIE);
				return driver;
			}
			else
				Error_Handler();
		}
		return driver;
}

void uartDriverReadData(void *_buffer,unsigned _bytes,uartDriver *_driver){

	unsigned tail = _driver->rxBufTail;

	for(unsigned i=0;i<_bytes;i++){
		((uint8_t*)_buffer)[i] = _driver->rxBuf[tail];
		tail = (tail+1) % _driver->rxBufSize;
	}

	_driver->rxBufTail = tail;
}

unsigned uartDriverDataReady(uartDriver *driver_){

	unsigned head = driver_->rxBufSize-__HAL_DMA_GET_COUNTER(driver_->huart->hdmarx);
	return (head - driver_->rxBufTail + driver_->rxBufSize) % (driver_->rxBufSize);
}

uint8_t uartDriverLoadData(const void *data,unsigned bytes,uartDriver *_driver){


	if(_driver == NULL)
		return 0;
	if(_driver->txBuf != NULL){
		if(data == NULL && bytes < 1)
			return 0;

		unsigned head = _driver->txBufHead;

		unsigned spaceInBuffer = (_driver->txBufSize - 1) - ((head - _driver->txBufTail) + _driver->txBufSize) % _driver->txBufSize;

		if(spaceInBuffer == 0)
			return 0;

		const UartTxData txData = {.data = data , .size = bytes};
		//txData.data = data;
		//txData.size = bytes;

		_driver->txBuf[head] = txData;
		head = (head + 1) % _driver->txBufSize;

		_driver->txBufHead = head;
		//Start DMA transfer
		if ((_driver->huart->hdmatx->Instance->CCR & DMA_CCR_EN) == 0){

			/*
			if((_driver->huart->Instance->CR3 & USART_CR3_HDSEL) != 0){
				CLEAR_BIT(_driver->huart->Instance->CR1, USART_CR1_RE);
				CLEAR_BIT(_driver->huart->Instance->CR3, USART_CR3_DMAR);
			}
			*/
			_driver->txActive = 1;

			StartTXDMA(_driver->huart->hdmatx,(uint32_t)(_driver->txBuf[_driver->txBufTail].data), (uint32_t)&(_driver->huart->Instance->TDR), _driver->txBuf[_driver->txBufTail].size);


			//CLEAR_BIT(_driver->huart->Instance->CR3, USART_CR3_DMAR);
			SET_BIT(_driver->huart->Instance->CR3, USART_CR3_DMAT);
		}

		return 1;
	}
	return 2;
}

unsigned uartDriverSpace(uartDriver *_driver){

	//unsigned head = _driver->rxBufSize - __HAL_DMA_GET_COUNTER(_driver->huart->hdmarx);
	//return (head - _driver->rxBufTail + _driver->rxBufSize) % _driver->rxBufSize;
	if(_driver->txActive == 0){
		return(__HAL_DMA_GET_COUNTER(_driver->huart->hdmarx));
	}
	else
		return 0;
}

void uartDriverClearRxBuffer(uartDriver *_driver){


	_driver->rxBufTail = _driver->rxBufSize - __HAL_DMA_GET_COUNTER(_driver->huart->hdmarx);

}
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

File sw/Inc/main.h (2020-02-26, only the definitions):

#define FLASH_CS_Pin GPIO_PIN_13
#define FLASH_CS_GPIO_Port GPIOC
#define ERROR_LED_Pin GPIO_PIN_15
#define ERROR_LED_GPIO_Port GPIOC
#define ESC1_VOLTAGE_Pin GPIO_PIN_0
#define ESC1_VOLTAGE_GPIO_Port GPIOA
#define ESC2_VOLTAGE_Pin GPIO_PIN_1
#define ESC2_VOLTAGE_GPIO_Port GPIOA
#define ESC1_CURRENT_Pin GPIO_PIN_2
#define ESC1_CURRENT_GPIO_Port GPIOA
#define ESC2_CURRENT_Pin GPIO_PIN_3
#define ESC2_CURRENT_GPIO_Port GPIOA
#define DAC_OUT_Pin GPIO_PIN_4
#define DAC_OUT_GPIO_Port GPIOA
#define FLASH_SCK_Pin GPIO_PIN_5
#define FLASH_SCK_GPIO_Port GPIOA
#define FLASH_MISO_Pin GPIO_PIN_6
#define FLASH_MISO_GPIO_Port GPIOA
#define FLASH_MOSI_Pin GPIO_PIN_7
#define FLASH_MOSI_GPIO_Port GPIOA
#define IN1_Pin GPIO_PIN_0
#define IN1_GPIO_Port GPIOB
#define OUT2_Pin GPIO_PIN_1
#define OUT2_GPIO_Port GPIOB
#define OUT1_Pin GPIO_PIN_2
#define OUT1_GPIO_Port GPIOB
#define FLASH_WP_Pin GPIO_PIN_11
#define FLASH_WP_GPIO_Port GPIOB
#define BAT_VOLTAGE_Pin GPIO_PIN_12
#define BAT_VOLTAGE_GPIO_Port GPIOB
#define AMP_CS_Pin GPIO_PIN_14
#define AMP_CS_GPIO_Port GPIOB
#define FLASH_HOLD_Pin GPIO_PIN_8
#define FLASH_HOLD_GPIO_Port GPIOA
#define Sport_UART_Pin GPIO_PIN_9
#define Sport_UART_GPIO_Port GPIOA
#define USB_ENUMERATE_Pin GPIO_PIN_10
#define USB_ENUMERATE_GPIO_Port GPIOA
#define Servo_2_Pin GPIO_PIN_4
#define Servo_2_GPIO_Port GPIOB
#define Servo_1_Pin GPIO_PIN_5
#define Servo_1_GPIO_Port GPIOB
#define HC_OUT1_Pin GPIO_PIN_6
#define HC_OUT1_GPIO_Port GPIOB
#define HC_OUT2_Pin GPIO_PIN_7
#define HC_OUT2_GPIO_Port GPIOB
#define IN2_Pin GPIO_PIN_8
#define IN2_GPIO_Port GPIOB
#define PWM2_Pin GPIO_PIN_9
#define PWM2_GPIO_Port GPIOB
#define SPORT_ID1	0x00
#define SPORT_ID2	0xA1
#define SPORT_ID3	0x22
#define SPORT_ID4	0x83
#define SPORT_ID5	0xE4
#define SPORT_ID6	0x45
#define SPORT_ID7	0xC6
#define SPORT_ID8	0x67
#define SPORT_ID9	0x48
#define SPORT_ID10	0xE9
#define SPORT_ID11	0x6A
#define SPORT_ID12	0xCB
#define SPORT_ID13	0xAC
#define SPORT_ID14	0x0D
#define SPORT_ID15	0x8E
#define SPORT_ID16	0x2F
#define SPORT_ID17	0xD0
#define SPORT_ID18	0x71
#define SPORT_ID19	0xF2
#define SPORT_ID20	0x53
#define SPORT_ID21	0x34
#define SPORT_ID22	0x95
#define SPORT_ID23	0x16
#define SPORT_ID24	0xB7
#define SPORT_ID25	0x98
#define SPORT_ID26	0x39
#define SPORT_ID27	0xBA
#define SPORT_ID28	0x1B
#define ALT_FIRST_ID              0x0100
#define ALT_LAST_ID               0x010f
#define VARIO_FIRST_ID            0x0110
#define VARIO_LAST_ID             0x011f
#define CURR_FIRST_ID             0x0200
#define CURR_LAST_ID              0x020f
#define VFAS_FIRST_ID             0x0210
#define VFAS_LAST_ID              0x021f
#define CELLS_FIRST_ID            0x0300
#define CELLS_LAST_ID             0x030f
#define T1_FIRST_ID               0x0400
#define T1_LAST_ID                0x040f
#define T2_FIRST_ID               0x0410
#define T2_LAST_ID                0x041f
#define RPM_FIRST_ID              0x0500
#define RPM_LAST_ID               0x050f
#define FUEL_FIRST_ID             0x0600
#define FUEL_LAST_ID              0x060f
#define ACCX_FIRST_ID             0x0700
#define ACCX_LAST_ID              0x070f
#define ACCY_FIRST_ID             0x0710
#define ACCY_LAST_ID              0x071f
#define ACCZ_FIRST_ID             0x0720
#define ACCZ_LAST_ID              0x072f
#define GPS_LONG_LATI_FIRST_ID    0x0800
#define GPS_LONG_LATI_LAST_ID     0x080f
#define GPS_ALT_FIRST_ID          0x0820
#define GPS_ALT_LAST_ID           0x082f
#define GPS_SPEED_FIRST_ID        0x0830
#define GPS_SPEED_LAST_ID         0x083f
#define GPS_COURS_FIRST_ID        0x0840
#define GPS_COURS_LAST_ID         0x084f
#define GPS_TIME_DATE_FIRST_ID    0x0850
#define GPS_TIME_DATE_LAST_ID     0x085f
#define A3_FIRST_ID               0x0900
#define A3_LAST_ID                0x090f
#define A4_FIRST_ID               0x0910
#define A4_LAST_ID                0x091f
#define AIR_SPEED_FIRST_ID        0x0a00
#define AIR_SPEED_LAST_ID         0x0a0f
#define RBOX_BATT1_FIRST_ID       0x0b00
#define RBOX_BATT1_LAST_ID        0x0b0f
#define RBOX_BATT2_FIRST_ID       0x0b10
#define RBOX_BATT2_LAST_ID        0x0b1f
#define RBOX_STATE_FIRST_ID       0x0b20
#define RBOX_STATE_LAST_ID        0x0b2f
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

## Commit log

2019-05-20 First Creation
    [Power.sch, Telemetry.kicad_pcb, Telemetry.sch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]
2019-05-20 Removed inverters and added expansion port
    [Telemetry.sch]
2019-05-20 Updated pin assignments and preliminary timer2 setup
    [Power.sch, Telemetry.sch, current.sch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]
2019-05-21 Connections updates
    [Power.sch, Telemetry.sch, current.sch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]
2019-05-22 Layout started, schematic modified for easier layout
    [Power.sch, Telemetry.kicad_pcb, Telemetry.sch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]
2019-05-23 Continued layout Setup USB device CDC
    [Telemetry.kicad_pcb, Telemetry.sch]
2019-05-23 Layout improvements
    [Power.sch, Telemetry.kicad_pcb, Telemetry.sch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]
2019-05-24 Added DAC initialization Added 32Mbit SPI FLASH memory Removed SPI expansion port
    [Telemetry.kicad_pcb, Telemetry.sch]
2019-05-24 Fixed crash problems
    [Telemetry.kicad_pcb, Telemetry.sch]
2019-05-25 Switched High Current FETs and added drivers for those
    [Power.sch, Telemetry.kicad_pcb, output.sch]
2019-05-25 Changed DAC timer settings
2019-05-25 Added DAC output connector to the design
    [Telemetry.kicad_pcb, Telemetry.sch]
2019-05-26 Lots and lots of updates Added DAC amplifier that can be controlled Cleaned up the schematic
    [Power.sch, Telemetry.kicad_pcb, Telemetry.sch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]
2019-05-26 Added SWD connector for debugging
    [Power.sch, Telemetry.kicad_pcb, Telemetry.sch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]
2019-05-28 Changed the digital potentiometer to AD5160 10k version and enabled SPI3
    [Telemetry.kicad_pcb, Telemetry.sch, current.sch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]
2019-05-28 Refactored schematic net names
    [Telemetry.kicad_pcb, Telemetry.sch, output.sch]
2019-05-29 Renamed schematic pdf Added gerbers Added layout pdf Fixed silkscreen on layout
    [Power.sch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]
2019-05-29 Added Bom
    [Power.sch]
2019-05-29 Added cooling temperature sensor
    [Telemetry-B.Cu.gbr, Telemetry-B.Mask.gbr, Telemetry-B.SilkS.gbr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]
2019-05-29 Added BOM PDF
2019-05-29 Layout and gerber update
    [Telemetry-B.Cu.gbr, Telemetry-B.Mask.gbr, Telemetry-B.Paste.gbr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]
2019-05-29 Gerber update
    [Telemetry-B.Cu.gbr, Telemetry-B.Mask.gbr, Telemetry-B.SilkS.gbr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]
2019-05-29 Power parser task done
2019-06-23 Added Opto-isolated inputs to the design Added uartdriver to the project Refined pin definitions
    [Telemetry-B.Cu.gbl, Telemetry-B.Mask.gbs, Telemetry-B.SilkS.gbo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]
2019-06-24 Fixed silkscreen
    [Telemetry-B.Cu.gbl, Telemetry-B.Mask.gbs, Telemetry-B.SilkS.gbo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]
2019-06-24 Improved uartdriver fixed lost functions issues
    [main.c, main.h, uart_driver.c]
2019-06-25 Fixed Uart driver errors
    [main.c, uart_driver.c]
2019-07-04 updated processor to STM32F303CC
2019-07-05 ADC free running DMA working on the board
2019-07-20 Uart Driver working almost
2019-07-24 ADC rank fixing. Sport UART working
    [RCTelemetry.ioc, main.c, uart_driver.c]
2019-07-27 Added DMA to USART3. USART3 used as Sbus channel becaus USART2 is used for debugging. Will be changed at some point to use only text debug.
2019-09-06 Working prototype data
    [Telemetry.sch]
2019-11-03 General commit
    [Power.sch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]
2020-02-12 Updates to board revision 0.2 and newer HAL version
    [Power.sch, Telemetry.kicad_pcb, Telemetry.sch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]
2020-02-13 Pin remapping and layout improvements
    [Power.sch, Telemetry.kicad_pcb, Telemetry.sch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]
2020-02-20 Changed High current pwm connectors to 5mm pitch versions
    [Power.sch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]
2020-02-21 Added connector 3D model Changed inductors to be compatible with JLCPCB smt assembly
    [Power.sch, Telemetry.kicad_pcb, pxc_1935161.stp]
2020-02-22 Added board 3D model picture to readme
    [Telemetry.kicad_pcb]
2020-02-23 BOM Generation for 1.1 version
    [Power.sch, Telemetry.kicad_pcb, Telemetry.sch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]
2020-02-23 DAC Amplifier improvements
    [Telemetry.kicad_pcb, Telemetry.sch, Telemetry_bom_1.1_(prod).csv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]
2020-02-24 Added additional opamp to DAC output as a buffer.
    [Power.sch, Telemetry.kicad_pcb, Telemetry.sch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]
2020-02-24 Fixed Schematic PDF
2020-02-25 Routing update
    [Telemetry.kicad_pcb, Telemetry.sch]
2020-02-26 Improved routing
    [Telemetry.kicad_pcb]
2020-02-26 Added LTSpice simulation of the amplifier circuit
2020-02-26 Layout fixes
    [Telemetry.kicad_pcb]
2020-02-26 Signal remapping for Flash Memory and component optimizations
    [Power.sch, Telemetry.kicad_pcb, Telemetry.sch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]
2020-02-27 Generated Gerbers and BOM for production
    [Telemetry.kicad_pcb, Telemetry.sch, Telemetry_bom_1.1_(prod).csv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]
2020-02-27 Removed Gerbers working folder
    [Telemetry-NPTH.drl, Telemetry-PTH.drl]
2020-06-30 Fixed Current sensor pinout
    [Telemetry.kicad_pcb, Telemetry.sch, Telemetry_bom_1.1_(prod).csv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]
2020-07-06 Design updates
    [Telemetry.kicad_pcb, Telemetry.sch, current.sch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]

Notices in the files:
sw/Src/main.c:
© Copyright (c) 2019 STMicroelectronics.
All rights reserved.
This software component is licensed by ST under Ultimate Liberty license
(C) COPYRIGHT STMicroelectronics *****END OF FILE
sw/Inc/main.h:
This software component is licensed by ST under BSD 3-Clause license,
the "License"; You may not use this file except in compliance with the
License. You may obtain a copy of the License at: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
